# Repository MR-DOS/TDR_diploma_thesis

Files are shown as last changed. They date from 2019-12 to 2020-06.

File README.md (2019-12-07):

# Time domain reflectometer
----
## Description
Simple and cheap TDR based on experience from TDR\_avalanche and TDR\_splitter. Primary intention of this device is to give people the possibility to measure defects on cables / PCBs for less than about $100.
It is also my diploma thesis. All software (GUI in Octave), firmware (which runs in the processor in the reflectometer) and hardware (the PCB) was written/drawn by me. All parts are open source and you can use the in any way which is conformant with GNU GPL 3.0. The only parts not made by me are the SPD and CMSIS drivers which are included because the firmware might not work with different versions (note: I patched a bug in the SPD in ADC section where changing ADC sources was programmed plainly wrong). 

----
## Overview
This device uses a PLL, fast CML buffer and diode sampling bridge. The principle is simple: one oscillator is fed into the CML buffer and then the resulting rectangular waveform with sharp edges (measured around 75-85 ps) is fed into the cable. Both the input pulse and the reflections are sampled by the diode sampling bridge which is driven by another oscillator. The oscillators have a fixed frequency ratio, which allows equivalent-time sampling. The use of equivalent time sampling reduces cost of the device, because the slowed-down waveform can be sampled by a normal ADC, thus there is no need for a oscilloscope grade fast ADC, fast (and expensive) circuitry like FPGAs.
The generated pulse should have maximum jitter of about 23 ps peak-to-peak and 4 ps RMS (measured). The TDR is able to sample with timestep of 20 ps.
In contrary with the TDR\_avalanche, this device uses only deterministic parts. The avalanche pulser had quite a lot of jitter and was difficult to tune to behave properly, I decided to use these instead.

----
## How it works
### Pulse generator
This TDR uses Si5351-A-B with 8 outputs as a triple oscillator with balanced outputs. One of the oscillators drives a CML buffer (SY54020), which creates a rectangular pulse with sharp edges. The pulses are fed into the network which connect the pulse generator, cable and sampler.

### Connecting network
The network mentioned earlier serves as a matching network to reduce impedance mismatch at the measuring connector.

### Sampler
The sampler is a simple dual diode bridge sampler which is fed by the other two oscillators. These two oscillators are synchronous with constant offset to allow double sampling and have a slightly different frequency than the oscillator in the generator. With this setup, the output of the sampler is a slowed-down version of the input waveform, which is then sampled by the microcontroller.

### ADC
The sampled waveform is digitized by the ADC of the microcontroller.

----
## References
[1-GHz Sampling Oscilloscope Front End Is Easily Modified](http://www.redrok.com/sampscope.htm)

----
## Sidenotes

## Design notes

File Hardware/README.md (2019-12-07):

# TDR_5351_core
----
## Description
Simple and cheap TDR based on experience from TDR\_avalanche and TDR\_splitter. Primary intention of this device is to give people the possibility to measure defects on cables / PCBs for less than about $100. UNDER CONSTRUCTION UNTIL STATED OTHERWISE.

----
## Overview
This device uses a PLL, fast CML buffer and diode sampling bridge. The principle is simple: one oscillator is fed into the CML buffer and then the resulting rectangular waveform with sharp edges (currently less than 200 ps) is fed into the cable. Both the input pulse and the reflections are sampled by the diode sampling bridge which is driven by another oscillator. The oscillators have a fixed frequency ratio, which allows equivalent-time sampling. The use of equivalent time sampling reduces cost of the device, because the slowed-down waveform can be sampled by a normal ADC, thus there is no need for a oscilloscope grade fast ADC, fast (and expensive) circuitry like FPGAs.
The generated pulse should have maximum jitter of about 80 ps peak-to-peak. The jitter of the sampler is not known as of now. Without the use of any averaging or statistical analysis, this could allow to sample points separated by no more than 100 ps (about 1-1.5 cm in a typical cable) and even less if averaging is used.

In contrary with the TDR\_avalanche, this device uses only deterministic parts. The avalanche pulser had quite a lot of jitter and was difficult to tune to behave properly. Since there are now quite cheap buffers with low rise/fall times (less than 200 ps, but there are even faster, though more expensive), Idecided to use these instead.

----
## How it works
### Pulse generator
This TDR uses Si5351-A-B with 8 outputs as a triple oscillator with balanced outputs. One of the oscillators drives a CML buffer (SY54020), which creates a rectangular pulse with sharp edges. The pulses are fed into the network which connect the pulse generator, cable and sampler.

### Connecting network
The network mentioned earlier serves as a matching network to reduce impedance mismatch at the measuring connector.

### Sampler
The sampler is a simple dual diode bridge sampler which is fed by the other two oscillators. These two oscillators are synchronous with constant offset to allow double sampling and have a slightly different frequency than the oscillator in the generator. With this setup, the output of the sampler is a slowed-down version of the input waveform, which is then sampled by the microcontroller.

### ADC
The sampled waveform is digitized by the ADC of the microcontroller. Because the ADC has only 12 bits, there is also a logarithmic detector with 90 dB dynamic range, effectively increasing the resolution to ~15 bits. This resolution can not be achieved with realtime sampling without spending a fortune on the ADC itself. There is an additional DAC for calibrating offset before measurement.

### First level of postprocessing
The first level of postprocessing is differentiation and normalization. After these operations, the user gets the response of the DUT to the input impulse. However, since the input pulse does not have infinitesimally short risetime, it may need additional postprocessing to get transmission / reflection graph.

### Second level of postprocessing
This second level consists of Wiener deconvolution - we have a measured input pulse and a "wish" - we want to get a nice clean step rising edge. Using these two vectors, a reverse filter can be computed using Wiener deconvolution. This step could help to get data which could be processed by the third level of postprocessing.

### Third level of postprocessing
This level analyses the data from the second level to get transmission and reflection coefficients for each measured point. The measured data has to be processed point-by-point. At each point, the reflected energy is used to compute the coefficients and the remaining energy after it has passed through this point. Then, a 1D simulation is run to get a vector of the reflected pulses. 
This resulting vector is then subtracted from the measured vector of data to get rid of multiple reflections. There is still one unsolved problem: defects with antisymmetrical reflection coefficient. This happens when two cables of different impedance are connected together. A localised defect (such as additional resistor in the path) has symmetrical reflection coefficient. Second problem is figuring out what is a multiple reflection and what is a periodic structure (this question may even have NO answer). After processing all of the points, the T/R vectors should be computed (note that there are two vectors for each parameter due to the antisymmetric behavior).
Next step is to turn the T/R vectors into a vector of characteristic impedance.

----
## Images
Description:
Description
Description2:
Description2

----
## References
[1-GHz Sampling Oscilloscope Front End Is Easily Modified](http://www.redrok.com/sampscope.htm)

----
## Sidenotes

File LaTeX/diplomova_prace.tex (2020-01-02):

% arara: pdflatex: { synctex: yes }
% arara: makeindex: { style: ctuthesis }
% arara: bibtex

% The class takes all the key=value arguments that \ctusetup does,
% and a couple more: draft and oneside
\documentclass[twoside]{ctuthesis}
\newcommand{\unit}[1]{\ensuremath{\, \textup{#1}}}
\usepackage{amsmath}
\usepackage{mathtools}
\usepackage{graphicx}
\usepackage{epsfig}
\usepackage{physics}
\usepackage[automake,acronym,nonumberlist]{glossaries}
\usepackage[binary-units=true,detect-all]{siunitx}
\sisetup{%
     output-decimal-marker = {,},
     %inter-unit-product = \ensuremath{{}\cdot{}}
        }
\sisetup{range-phrase=--}
\usepackage[short,ddmmyyyy]{datetime}
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

V práci je popsána vytvořená konstrukce reflektometru a princip jeho funkce. Jednotlivé funkční bloky jsou podrobně popsány, vysvětlen je i postup optimalizace těchto bloků k dosažení co nejlepších parametrů zapojení. Vysvětleny jsou i metody detekce závad na vedení, kalibrace zařízení a autokalibrace.

Práce ze zabývá i případnými možnostmi, jak by bylo možné rozšířit schopnosti tohoto zařízení o funkci transmisometru, která by umožnila používat toto zařízení jako vektorový analyzátor v časové oblasti.

\end{abstract-czech}

% Abstract in English
\begin{abstract-english}
This work deals with construction of reflectometer in time domain, which is implemented as functional device along with control software. The goal was to develop a device capable of measuring reflections on transmission lines caused by faults with spatial resolution on the order of units of centimetres. The emphasis was to develop a cheap and simple device while trying not to limit the functionality or capability of the device.

The resulting device is able to measure up to units of~\si{\GHz}, sampling step is \SI{20}{\ps}, resulting in equivalent sampling rate of \SI{50}{\gigasample}. This sampling step theoretically allows spatial resolution of \SI{0.3}{\centi\meter} in vacuum, possibly even less in real environment. The device can detect simple faults on its own, along with their type and position. When used with computer, it is possible to perform calibration using calibration set.

The work contains explanation of the construction and its principles. Each functional block is described in detail as well as the optimalisations which were used to obtain the best possible parameters of the construction. Also explained are methods of detection of faults on the transmission line, calibration and autocalibration of the device.

This work also deals with eventual possibilities of extending the capabilities of the device by implementing a function of transmisometer, which could allow to use the device as a vector network analyzer in time domain.

\end{abstract-english}

% Acknowledgements / Podekovani
\begin{thanks}
Děkuji svým rodičům i celé rodině, že mi byli oporou po celou dobu mého studia.

Děkuji Ing. Viktoru Adlerovi, Ph.D., a prof. Ing. Karlu Hoffmannovi, CSc., za umožnění přístupu k mikrovlnné měřicí technice a možnost konzultování detailů této práce.

Děkuji Ing. Viktoru Adlerovi, Ph.D., za významnou pomoc při analýze vysokofrekvenčních parametrů substrátu použitého pro plošný spoj reflektometru.

Děkuji studentskému klubu Silicon Hill a projektu \quotedblbase MacGyver - Bastlíři SH\textquotedblleft\ za umožnění přístupu k měřicímu vybavení, pájecí a osazovací technice.

Děkuji Ing. Pavlu Poláškovi, Ing. Petru Bartoňovi, Ing. Stanislavu Tomáškovi, Ing. Martinu Řehákovi, Ing. Stanislavu Mašláňovi a Bc. Janu Sixtovi za pomoc při kontrole překlepů, jazykové úrovně a detailů estetické formy této práce.
\end{thanks}

% Declaration / Prohlaseni
\begin{declaration}
Prohlašuji, že jsem  předloženou práci vypracoval samostatně a že jsem uvedl veškeré použité informační zdroje v souladu s Metodickým pokynem č.~1/2009 o dodržování etických principů při přípravě vysokoškolských závěrečných prací.

Dále prohlašuji, že nemám závažný důvod proti užití tohoto školního díla ve smyslu §60 zákona č.~121/2000 Sb., o právu autorském, o právech souvisejících s právem autorským a o změně některých zákonů (autorský zákon).

V Praze, \ctufield{day}.~\monthinlanguage{title}~\ctufield{year}

% podpis pod prohlasenim
\begin{flushright}
	\parbox{5cm}
	{
		\begin{center}
			\dotfill \\ Bc. Petr Polášek 
		\end{center}
	}
\end{flushright}

\end{declaration}

% Only for testing purposes
%\listfiles
\usepackage[pagewise]{lineno}

\begin{document}

\maketitle

\printglossaries

\input{diplomova_prace_1_uvod.tex}
\input{diplomovy_projekt_1_uvod.tex}
\input{diplomovy_projekt_2_buzeni.tex}
\input{diplomovy_projekt_3_vzorkovani.tex}
\input{diplomovy_projekt_4_separace.tex}
\input{diplomovy_projekt_5_rozsireni_dynamickeho_rozsahu.tex}
\input{diplomovy_projekt_6_navrzena_architektura.tex}
%\input{diplomova_prace_2_princip_funkce.tex}
\input{diplomova_prace_3_popis_zapojeni.tex}
\input{diplomova_prace_popis_firmware.tex}
\input{diplomova_prace_popis_software}
\input{diplomova_prace_4_kalibrace.tex}
\input{diplomova_prace_5_detekce_zavad.tex}
\input{diplomova_prace_6_zmerene_parametry.tex}
%\input{diplomova_prace_7_uzivatelske_rozhrani_a_popis_ovladani.tex}
\input{diplomova_prace_8_zaver.tex}

\appendix

\printindex

\bibliographystyle{unsrt}
\bibliography{diplomova_prace}

%\ctutemplate{specification.as.chapter}

\end{document}

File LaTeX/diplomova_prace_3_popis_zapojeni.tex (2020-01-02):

\chapter{Princip zapojení}

\section{Základní princip zapojení}
Zapojení se skládá z generátoru impulsů, vzorkovacích obvodů a řídicího fázového závěsu, který tyto dvě části synchronizuje. Generátor impulzů se používá pro tvorbu budicího signálu, který je zaveden do měřeného systému. Pomocí vzorkovacího můstku se pak provádí měření odezvy měřeného systému. Fázový závěs časuje spouštění generátoru a vzorkovače asynchronně tak, aby se postupně spouštěcí událost obou části vzájemně posouvala. Tím dochází k tomu, že každý vzorek odpovídá jinému bodu měřené odezvy. Zařízení tedy pracuje v režimu měření v ekvivalentním čase. To znamená, že měřená odezva není změřena v reálném čase, ale je pomalu sbírána. V navrženém zapojení dojde při každé periodě budicího signálu ke změření jednoho vzorku odezvy systému.

\section{Blokové zapojení}
\begin{figure}[htbp]
\caption{Blokové zapojení reflektometru.} \label{block_diagram}
\end{figure}

Podrobnější blokové zapojení reflektometru je znázorněno na obrázku \ref{block_diagram}. V dalších částech této kapitoly jsou jednotlivé bloky popsány do hloubky. Oproti základnímu blokovému zapojení z obrázku \ref{reflectometer_blockdiagram} obsahuje toto blokové zapojení navíc 3 bloky, jejichž nezbytnost vyplynula ze simulací. Důvody pro nezbytnost těchto bloků jsou vysvětleny v rámci této kapitoly. 

\section{Generování potřebných hodinových signálů}
Hlavním prvkem celého zapojení je vícekanálový digitální fázový závěs, který je postaven na obvodu Si5351C-B \cite{Si5351datasheet}. Tento obvod obsahuje krystalový oscilátor, na nějž jsou zavěšeny dva interní oscilátory \acrshort{VCO}. Vnitřní blokové schéma je možné vidět na obrázku \ref{5351blockdiagram}.

Tyto oscilátory je možné nezávisle nastavit. Jejich frekvence $f_\mathrm{VCO}$ může být neceločíselným násobkem frekvence krystalového oscilátoru $f_\mathrm{XTAL}$.
\begin{equation}
f_\mathrm{VCO}=f_\mathrm{XTAL} \left(a+\dfrac{b}{c} \right)
\end{equation}
Koeficient $a$ může nabývat hodnot $\langle 15, 90 \rangle$. V neceločíselném režimu může koeficient $c$ nabývat hodnot $\langle 0, 1048575 \rangle$, koeficient $b$ pak $\langle 0, c \rangle$.
Je tedy možné nastavit frekvenci oscilátorů tak, že se liší o méně než 1 ppm. Při použití těchto dvou frekvencí jako časovacích signálů pro buzení a vzorkování je tedy možné odebírat až 1048576 vzorků. Dochází totiž k tomu, že s každou periodou se postupně hrany těchto obdélníkových signálů vůči sobě časově posunou o fixní časový krok. Tento krok je možné spočítat z nastavených frekvencí oscilátorů.

\begin{equation}
\begin{gathered}
f_\mathrm{VCO1}=f_\mathrm{XTAL} \left(a_1+\dfrac{b_1}{c_1} \right) \\
f_\mathrm{VCO2}=f_\mathrm{XTAL} \left(a_2+\dfrac{b_2}{c_2} \right)
\end{gathered}
\end{equation}

Za těmito oscilátory ještě následují děličky. Ty také umožňují neceločíselné dělení, které je ovšem nevýhodné, protože může zvyšovat fázové chvění výstupního signálu. Proto jsou použity pouze v celočíselném režimu. Děličky jsou použity kvůli omezenému vzorkovacímu kmitočtu použitého \acrshort{ADC}. Výsledkem jsou tedy dvě frekvence $f_\mathrm{OUT1}$ a $f_\mathrm{OUT2}$. Označíme-li společný dělicí poměr $d$ a za předpokladu, že $a_1=a_2=a$, $c_1=c_2=c$ a $b_2=0$:

\begin{equation}
\begin{gathered}
f_\mathrm{OUT1}=\dfrac{f_\mathrm{VCO1}}{d}=f_\mathrm{XTAL} \left(\dfrac{a+\dfrac{b_1}{c} }{d}\right) \\
f_\mathrm{OUT2}=\dfrac{f_\mathrm{VCO2}}{d}=f_\mathrm{XTAL} \left(\dfrac{a}{d}\right).
\end{gathered}
\end{equation}

Pak se během jedné periody oscilátory vůči sobě posunou o čas $T_\textrm{SHIFT}$:

\begin{equation}
\begin{gathered}
T_\mathrm{SHIFT}=T_\mathrm{OUT2}-T_\mathrm{OUT1}=\dfrac{1}{f_\mathrm{OUT2}} - \dfrac{1}{f_\mathrm{OUT1}} \\
T_\mathrm{SHIFT}=\dfrac{d}{f_\mathrm{XTAL}} \left(\dfrac{1}{a} - \dfrac{1}{a+\dfrac{b_1}{c}}\right) = \dfrac{d}{a f_\mathrm{XTAL}} \left(\dfrac{1}{1+a\dfrac{c}{b_1}}\right).
\end{gathered}
\label{equation_tshift}
\end{equation}

Pro minimalizaci fázového chvění je podle \cite{Si5351datasheet} a \cite{Si5351applicationnote} vhodné preferovat celočíselné násobení i dělení, je-li to možné. Dále může fázové chvění zmenšit i použití sudých násobitelů a dělitelů. V navrženém zapojení je tedy fázový závěs nastaven takto:

\begin{equation}
\begin{gathered}
f_\mathrm{XTAL}=\SI{25}{MHz} \\
a=24 \;\;\; b_1=24/8=3 \\
c=500000/8=62500 \;\;\; d=128 \cdot 46=5888 \\
f_\mathrm{OUT1} \doteq \SI{101902}{kHz} \doteq f_\mathrm{OUT2} \\
T_\mathrm{SHIFT} = \dfrac{46 \cdot 128}{24 \cdot 25000000} \left(\dfrac{1}{1+24 \cdot \dfrac{500000}{24}}\right) \doteq \SI{19.627}{ps}.
\end{gathered}
\end{equation}

Podobný princip měření pomocí dvou oscilátorů o podobné frekvenci se již v literatuře objevil, avšak zatím nebyl implementován přímo pomocí fázového závěsu. V \cite{vernierreflectometer} byly použity dva nezávislé oscilátory. Toto řešení je sice jednodušší, avšak není možné zajistit, jak velký bude časový krok měření. Vzhledem ke skutečnosti, že oscilátory jsou závislé na teplotě a dalších vnějších vlivech, není možné zajistit ani dlouhodobou stabilitu. Při použití dvojitého fázového závěsu s neceločíselným násobitelem však je možné tuto dlouhodobou stabilitu zajistit. Krok měření je pak závislý pouze na frekvenci jediného krystalového oscilátoru. Při použití \acrshort{TCXO} může být tato stabilita velmi dobrá, na úrovni jednotek \si{ppm}.

Další podobný způsob časování vzorkování je použit v \cite{ddsfpgareflectometer}, kde je využito \acrshort{FPGA} jako \acrshort{DDS}. Výstup z této \acrshort{DDS} je filtrován dolní propustí a následně zaveden do komparátoru, římž je získáván obdélníkový řídicí signál. Řízení vzájemné polohy budicího pulzu a vzorkování je pak dosaženo nastavováním fáze sinusového signálu, který je generován \acrshort{DDS}. Tento systém umožňuje krok vzorkování v jednotkách pikosekund. Je tedy podobný vlastnostmi konstrukci popsané v této práci. Něvýhodou je však to, že autoři se příliš nezabývali generátorem impulzů, náběžná hrana použitého generátoru činí přibližně \SI{2}{ns}. Důvod, proč tak autoři učinili, je možná omezení vyplývající ze zvoleného způsobu vzorkování pomocí komparátoru a digitálního integrátoru.

\begin{figure}[htbp]
\caption{Zapojení hodinového generátoru Si5351.}\label{timing_section_schematic}
\end{figure}	

Zapojení hodinového generátoru s fázovým závěsem Si5351 je zobrazeno na \ref{timing_section_schematic}. Symbol obvodu je rozdělený na dvě části, U207A a U207B. Kromě samotného obvodu Si5351 je potřeba pouze referenční krystal a napájecí obvody. Napájení je rozděleno na dvě domény. První je jádro fázového závěsu, které napájí interní logické obvody a \acrshort{VCO}. Druhá napájí výstupní budiče. Toto rozdělení by mělo omezit fázový šum generovaných hodinových signálů způsobený rušením na napájení \acrshort{VCO} \cite{Si5351applicationnote}. Pro krystalový oscilátor není potřeba používat zatěžovací kondenzátory, jsou obsaženy uvnitř obvodu Si5351, je možné je nastavit v rozsahu \SIrange{4}{10}{\pico\farad}.

Výstupní budiče obvodu Si5351 jsou slučitelné jak s \acrshort{CMOS} obvody a jejich modernějšími variantami, tak i s obvody rodin \acrshort{TTL}, \acrshort{ECL}, \acrshort{CML}, \acrshort{LVDS} a podobnými. Budiče jsou proudové, proud je možné nastavit ve čtyřech krocích v rozsahu \SIrange{2}{8}{\milli\ampere} \cite{Si5351datasheet}. Tohoto faktu je využito v zapojení, 4 výstupy jsou použity přímo pro proudové buzení vzorkovacích můstků, 2 výstupy pro buzení \acrshort{CML} bufferu, jeden výstup pro synchronizaci vzorkování použitého mikrokontroléru a jeden výstup pro řízení stavu \acrshort{CML} bufferu.

Dle katalogových údajů by tento fázový závěs měl typicky dosahovat mezivrcholového fázového šumu \SI{70}{\pico\second}, maximálně  \SI{155}{\pico\second}. Dle výrobce by mělo jít o parametry v \quotedblbase nejhorším možném případě v reálné aplikaci \ldots{} skutečné vlastnosti mohou být výrazně lepší\textquotedblleft{} \cite{Si5351datasheet}. Bohužel není uvedeno, jak se tento parametr mění v závislosti na nastavení násobicích a dělicích sekcí. Není uveden ani histogram šumu, jeho frekvenční spektrum, ani efektivní hodnota. Spektrum fázového šumu je možné najít v \cite{Si5351_phase_noise_measurement}, bohužel se nejedná o ověřený zdroj.

\section{Tvorba budicího pulzu}
Pro tvorbu budicích pulzů byl vybrán obvod SY54020, který je původně určen jako \acrshort{CML} buffer. Logické obvody \acrshort{CML} používají logické úrovně referencované vůči kladnému pólu napájení, výstupy i vstupy těchto obvodů jsou přizpůsobené impedanci \SI{50}{\ohm}. Podle katalogových údajů \cite{SY54020datasheet} by měla výstupní impedance ležet v rozsahu \SIrange{45}{55}{\ohm}. Hlavní důvod pro použití tohoto bufferu je vysoká rychlost, dle katalogových údajů by měla délka náběžných a sestupných hran spadat do rozsahu \SIrange{35}{100}{\pico\second}, typicky \SI{60}{ps}. Tento údaj je udáván pro body, kde prochází náběžná hrana \SI{20}{\%} a \SI{80}{\%} mezi původním a konečným napětím. U obvodu Si5351 by podle katalogových údajů měl tento parametr být typicky \SI{1}{\nano\second}, maximálně \SI{1.5}{\nano\second}. Použitím obvodu SY54020 by tedy mělo být možné zkrátit náběžné hrany o \SIrange{90}{98}{\%} oproti přímému použití výstupu z obvodu Si5351 jako zdroje budicích pulzů. Dle katalogových údajů by špičkové aditivní fázové chvění mělo být přibližně \SI{1}{\pico\second}, tedy přibližně o dva řády lepší, než fázové chvění obvodu Si5351. Použití budiče SY54020 by tedy mělo mít zcela minimální vliv na celkovou úroveň fázového chvění.

\begin{figure}[htbp]
\caption{Zapojení generátoru budicích pulzů}\label{pulse_generator_section_schematic}
\end{figure}	

Postatná výhoda obvodu SY54020 spočívá v oddělení napájecích úrovní vstupů a výstupů tohoto obvodu. V zapojení je vstupní část obvodu napájena \SI{3.3}{\volt}, výstupní část \SI{1.65}{\volt}, tedy přesně polovičním napájecím napětím. Tato napájecí hladina označená jako VCC, a zároveň jako GNDS, je použita jako virtuální analogová země. Všechny následující analogové obvody jsou vztažené k této virtuální zemi. Díky tomu je možné k buzení vzorkovacích můstků použít přímo fázový závěs Si5351, protože můstek je tak buzen symetricky. Zapojení generátoru budicích impulzů je na obrázku \ref{pulse_generator_section_schematic}.

\section{Přizpůsobovací obvody a testovací port}
Generátor budicích impulzů z předchozího bodu je nezbytné připojit k měřicímu portu. K tomuto portu však musí být zároveň připojeny vzorkovací obvody. Proto jsou nezbytné přizpůsobovací obvody, které umožňují připojit k testovacímu portu obě tyto části při dodržení vstupní impedance. Jejich zapojení je uvedeno na obrázku \ref{match_section_schematic}.

\begin{figure}[htbp]
\caption{Schéma přizpůsobovacích obvodů.}\label{match_section_schematic}
\end{figure}

Přizpůsobovací obvody jsou navrženy tak, aby bylo dosaženo co nejlepšího impedančního přizpůsobení na testovacím konektoru. Problematická je impedance vzorkovacího můstku, neboť na jeho výstupu je připojen vzorkovací kondenzátor, který způsobuje rezonanci pouzdra vzorkovacího můstku na frekvenci přibližně \SI{1.7}{\giga\hertz}. Vliv této rezonance na vstupní impedanci reflektometru je částečně potlačen použitím děliče sestaveného z odporů R220, R224 a R229 a cívky L201 (označení podle obrázku \ref{match_section_schematic}). Výsledná impedance je zakreslena v grafu \ref{input_impedance}, parametr $S_{11}$ pak v grafu \ref{input_reflection}. Simulace byla provedena bez vedení T1, které se nachází na schématu \ref{ltspice_schematic} a přibližně simuluje vedení mezi testovacím konektorem a vzorkovačem. Hodnoty použitých součástek v děliči se mezi schématy liší, protože během vývoje zařízení byly použité diodové můstky HSMS-282P vyřazeny z výroby. Jako náhrada byly vybrány diodové můstky SMS3923-081LF. Díky podrobnějšímu SPICE modelu bylo možné do simulace zahrnout i vliv parazitních vlastností pouzdra tohoto můstku, což umožnilo další optimalizace. Konečné hodnoty použitých součástek se nachází ve schématu použitém v simulaci.

\begin{figure}[htbp]
\caption{Schéma použité pro simulaci vstupní impedance v programu LTSpice.}\label{ltspice_schematic}
\end{figure}

\begin{figure}[htbp]
\caption{Vstupní impedance reflektometru.}\label{input_impedance}
\end{figure}

\begin{figure}[htbp]
\caption{Přizpůsobení vstupní impedance reflektometru.}\label{input_reflection}
\end{figure}

Vstupní impedance byla simulována do 10 GHz. V celém simulovaném pásmu se vstupní impedance odchyluje od nominálních $50~\Omega$ o méně než $\pm2~\Omega$. Parametr $\lvert S_\mathrm{11} \rvert$ je vykreslen v grafu \ref{input_reflection}. V celém rozsahu je menší než \SI{-33}{\deci\bel}, což odpovídá koeficientu odrazu $\Gamma <= 0.023$. Navržené přizpůsobení by tedy mělo být velmi dobré. Vzhledem k tomu, že konektory obvykle způsobují odraz větší, než je odraz vycházející ze simulace, měl by být klíčovým prvkem pro dosažení malého odrazu na testovacím portu kvalitní konektor a připojovací vedení. Při uvažování tolerance impedance budiče SY54020, která se pohybuje v rozsahu \SIrange{45}{55}{\ohm}, se přizpůsobení zhorší, nicméně v celém rozsahu je lepší než \SI{-30}{\deci\bel}.

\section{Vzorkovací obvody a oddělovací zesilovač}
Vzorkování je v reflektometru prováděno ve třech stupních. První stupeň je tvořený diodovým můstkem U208 (na obrázku \ref{sampler_section_schematic}) a kondenzátorem C230. Druhý stupeň vzorkování je tvořen diodovým můstkem U209 a kondenzátorem C233. Třetí stupeň probíhá uvnitř mikrokontroléru v \acrshort{ADC}.

První vzorkovací stupeň je připojen k obvodu Si5351, který proudově napájí vzorkovací můstek. Proud nastavený na budičích tohoto obvodu je \SI{8}{\milli\ampere}. V době, kdy vzorkovač sleduje vstupní signál, jsou diody sepnuty v propustné oblasti, můstek se pak chová přibližně jako rezistor o odporu jednotek \si{\ohm} zapojený mezi vstupem a vzorkovacím kondenzátorem. V okamžiku, kdy má být odebrán vzorek měřeného napětí, se obrátí směr proudu tekoucí skrz můstek, čímž se můstek rozepne. Po rozepnutí má můstek charakter kondenzátoru o kapacitě desetin pikofaradu. Aby můstek co nejméně ovlivňoval vstupní impedanci reflektometru, je připojen přes přizpůsobovací obvody. Kondenzátor C230 musí mít co nejmenší kapacitu, aby příliš kapacitně nezatěžoval vzorkovací můstek. Při použití většího kondenzátoru klesá šířka propustného pásma vzorkovače a zvětšuje se vliv vzorkovače na vstupní impedanci reflektometru. Pro potlačení kapacitního charakteru vzorkovače je v přizpůsobovacím obvodu použita kombinace R229 a L201 podle schématu \ref{sampler_section_schematic}, které částečně na vysokých frekvencích stáčí impedanci zpět k reálným hodnotám. Při použití příliš malého kondenzátoru je problematická parazitní kapacita diodového můstku v rozepnutém stavu, měřený signál pak výrazně \quotedblbase prosakuje\textquotedblleft{} do navzorkovaného signálu i v okamžiku, kdy je diodový můstek rozepnutý.

\begin{figure}[htbp]
\caption{Zapojení vzorkovacích obvodů.}\label{sampler_section_schematic}
\end{figure}

Vzhledem k velice malé kapacitě vzorkovacího kondenzátoru je nezbytné, aby obvody připojené k němu měly minimální vstupní proud. To by bylo možné zajistit přímo unipolárním operačním zesilovačem U205, avšak má velkou vstupní kapacitu, přibližně 27 pF \cite{oscilloscopefrontend}. Proto je použit oddělovací zesilovač s unipolárním dvouhradlovým tranzistorem BF998 s malou kapacitou hradla. Vstupní impedance oddělovacího zesilovače je přibližně do \SI{900}{\mega\hertz} takřka čistě imaginární, kapacita odpovídající této impedanci je přibližně \SI{0.6}{\pico\farad} na \SI{10}{\mega\hertz} a \SI{0.9}{\pico\farad} na \SI{1}{\giga\hertz}. Zesilovač je zapojen jako sledovač signálu s jednotkovým ziskem. V source tranzistoru je zapojen proudový zdroj kvůli minimalizaci zkreslení. Dle simulace by stejnosměrné zkreslení zesilovače mělo být lepší než \SI{0.0005}{\%}, absolutní chyba výstupního napětí je uvedena v grafu \ref{buffer_voltage_error}. Rozkmit měřeného napětí je podle simulací \SI{20}{\milli\volt}.

Při návrhu zapojení byly uvažovány i varianty s jinými tranzistory. Bohužel nebyl nalezen žádný tranzistor, který by byl  schopen pracovat do vyšších frekvencí a přitom měl nízký vstupní proud hradla. Moderní tranzistory HEMT bohužel zpravidla mají vstupní proud v řádu mikroampérů. Rychlejší tranzistory typů MOSFET nebo MESFET se vyrábí pouze pro výkonové aplikace. Ke vhodným tranzistorům typu JFET se bohužel dodávají pouze S-parametry a nejsou dostupné parametry pro SPICE modely. Nakonec tedy byl zvolen tranzistor BF998. 

Maximální hodnotu kapacity kondenzátoru C230 určuje i oddělovací zesilovač. Při kapacitě větší než \SI{1.5}{\pico\farad} se oddělovací zesilovač rozkmital, což bylo zjištěno v zapojení během testování. Následně byla tato skutečnost potvrzena simulací a opravena. Proto jsou v zesilovači použity odpory R249, R250 a R251. R251 omezuje kladnou zpětnou vazbu a tlumí rezonanci páru U208~--~C230, čímž je zabráněno rozkmitání zesilovače. Odpor R249 nadále zeslabuje tuto kladnou zpětnou vazbu. Odpor R250 zvětšuje vstupní impedanci zesilovače a zvětšuje šířku pásma tohoto oddělovacího stupně. Kondenzátor C231 není v konečném zapojení použit, neboť zmenšoval použitelnou šířku pásma zesilovače a zhoršoval stabilitu zapojení. Přenosová charakteristika oddělovacího zesilovače je uvedena v grafu \ref{frequency_transfer_function_bf}.Podle těchto odsimulovaných výsledků by měla být 6\si{\deci\bel} šířka pásma přibližně \SI{5.9}{\giga\hertz}.

\begin{figure}[htbp]
\caption{Přenos oddělovacího zesilovače.}\label{frequency_transfer_function_bf}
\end{figure}

Celková přenosová charakteristika od testovacího portu až k výstupu oddělovacího zesilovače je uvedena v grafu \ref{frequency_transfer_function_all}. 6\si{\deci\bel} šířka pásma pak činí přibližně \SI{1.93}{\giga\hertz}.

\begin{figure}[htbp]
\caption{Přenos celého systému přizpůsobení-vzorkovač-zesilovač.}\label{frequency_transfer_function_all}
\end{figure}

Simulace nebyla provedena s idealizovaným proudovým zdrojem, ale již v zapojení, které je uvedeno na schématu \ref{sampler_section_schematic}. Simulovaná data by tak měla lépe odpovídat realitě. Důvod, proč na schématu \ref{ltspice_schematic} není uvedeno celé zapojení proudového zdroje, ale jen idealizovaného zdroje, je časová náročnost výpočtů. Při simulacích vstupní impedance má tato část minimální vliv na výsledky, ale výrazně zpomaluje výpočty, proto byla ze simulací týkajících se vstupní impedance a tranzientních simulací oddělovacího zesilovače vynechána. Celé zapojení proudového zdroje je vidět na schématu \ref{current_source_section_schematic}.

\begin{figure}[htbp]
\caption{Absolutní chyba linearity oddělovacího zesilovače.}\label{buffer_voltage_error}
\end{figure}

\begin{figure}[htbp]
\caption{Zapojení proudového zdroje.}\label{current_source_section_schematic}
\end{figure}

Proudový zdroj na schématu \ref{current_source_section_schematic} napájí oddělovací zesilovač. Zdroj je řízen \acrshort{DAC}, je možné jej nastavit v rozsahu \SIrange{0}{15.9}{\si{mA}} v 4096 krocích po přibližně \SI{3.88}{\micro\ampere}. Zdroj je určen k autokalibraci reflektometru, umožňuje stejnosměrné posunutí měřeného signálu. Tento autokalibrační proces je nezbytný kvůli výrobním tolerancím a teplotní závislosti unipolárního dvouhradlového tranzistoru BF998. Proudový zdroj je zapojen jako kaskodové proudové zrcadlo. Odpor R235 spolu s tranzistory Q203 a Q204 slouží jako převodník z napětí na proud. Tranzistory Q202, Q205, Q206 a Q207 tvoří proudové zrcadlo. V emitorech tranzistorů jsou zapojeny odpory, čímž se zrcadlo podobá Widlarově proudovému zrcadlu se zesilovacím poměrem přibližně 60. Tranzistor Q202 je vysokofrekvenční typ s $f_T=\SI{6}{\giga\hertz}$ při \SI{8}{\milli\ampere} a nízkou výstupní kapacitou kolektoru, maxímálně $C_\mathrm{ob}<\SI{1.8}{\pico\farad}$. Pro ochranu tranzistoru Q202 před lavinovým průrazem během zapínání reflektometru a autokalibrace je použita dioda D201, která omezuje napětí kolektor-emitor na tranzistoru Q202 na přibližně \SI{4}{\volt}, průrazné napětí tranzistoru je dle katalogových údajů \SI{6}{\volt}. Proudový zdroj je navržen tak, že není možné nastavit proud emitorem tranzistoru Q202 větší než \SI{15}{\milli\ampere}, přičemž povolený trvalý proud je \SI{50}{\milli\ampere}. Tranzistor by tedy měl být kompletně ochráněn před poškozením. Pro potlačení vlivu kapacity diody D201 na přenos oddělovacího zesilovače na vysokých frekvencích je použita cívka L203.

\begin{figure}[htbp]
\caption{Zapojení napájecích zdrojů vzorkovacích obvodů.}\label{analog_source_section_schematic}
\end{figure}

Napájecí zdroj operačních zesilovačů, proudového zdroje a oddělovacího zesilovače je na schématu \ref{analog_source_section_schematic}. Zdroj je napájen z \SI{5}{\volt} získávaných z USB. Jádrem je spínaný zdroj MT3608 pracující na frekvenci \SI{2}{\mega\hertz}, který je nastaven na napětí \SI{12.6}{\volt}. Tato napájecí větev je filtrována aktivním filtrem s tranzistorem Q208. Napájecí hladina \SI{12.6}{\volt} je filtrována RC článkem R244-C264. Toto vyfiltrované napětí je zapojeno do gate tranzistoru Q208, který je zapojen jako sledovač. Teoreticky je tak možné zajistit značné potlačení zvlnění napětí na napájecí větvi. Výsledkem je vyfiltrované nestabilizované napětí přibližně \SI{10}{\volt}. Potlačení zvlnění by dle simulace mělo být přibližně \SI{-128}{\deci\bel} na frekvenci \SI{2}{\mega\hertz}, kde pracuje spínaný zdroj. Přenosová charakteristika tohoto aktivního filtru je na grafu \ref{analog_source_filter_transfer}, je vyznačená modře. V realizovaném zapojení bude toto potlačení pravděpodobně výrazně menší, což může způsobit např. nízká renonanční frekvence nebo sériový odpor kondenzátorů použitých na výstupu filtrů.

Záporná napájecí větev je získávána z téhož zdroje pomocí nábojové pumpy tvořené kondenzátory C266 -- C268 a diodami D205 a D206. Výsledné napětí je přibližně \SI{-12}{\volt}. Tranzistor Q209 opět tvoří aktivní filtr. Odporovým děličem je nastaveno výstupní napětí přibližně \SI{-5}{\volt}. Potlačení zvlnění by dle simulace mělo být přibližně \SI{-134}{\deci\bel} na frekvenci \SI{2}{\mega\hertz}, kde pracuje spínaný zdroj. Přenosová charakteristika tohoto aktivního filtru je na grafu \ref{analog_source_filter_transfer}, je vyznačená oranžově.

Za předpokladu, že simulace odpovídají reálnému chování navržených obvodů, mělo by být zvlnění na napájecích větvích způsobené spínaným zdrojem potlačeno aktivními filtry natolik, že by nemělo být měřitelné a nemělo by nijak ovlivňovat měření.

\begin{figure}[htbp]
\caption{Přenosová charakteristika aktivních napájecích filtrů.}\label{analog_source_filter_transfer}
\end{figure}

Za oddělovacím zesilovačem následuje jednotkový sledovač s operačním zesilovačem TL072, který slouží ke snížení výstupní impedance oddělovacího zesilovače. Výstup tohoto zesilovače je opět vzorkován pomocí vzorkovacího můstku U209 do \SI{1}{\nano\farad} kondenzátoru. Oddělovací zesilovač má sice vysokou impedanci, takže téměř nezpůsobuje drift napětí na vzorkovacím kondenzátoru C230, nicméně vzhledem ke svodovému proudu vzorkovacího můstku U208 je tento drift nenulový. Proto těsně před sepnutím můstku U208 se rozepne můstek U209. Vzhledem k tomu, že kapacita kondenzátoru C233 je o 3 řády větší, než kapacita kondenzátoru C230, je i výsledný drift o 3 řády menší. Napětí po tomto sekundárním vzorkování je zesíleno v zesilovači U205 na schématu \ref{secondary_sampler_section_schematic}.

\section{Logaritmický detektor}

Toto navzorkované napětí je převáděno na logaritmickou podobu pomocí logaritmického detektoru AD8307. Logaritmický detektor byl použit pro rozšíření dynamického rozsahu měření dvanáctibitového \acrshort{ADC}. Bohužel, v rámci testování se ukázalo, že šum vzorkovacích obvodů je příliš velký a logaritmický detektor nepřinášel žádné zpřesnění měřených hodnot. Změřená závislost výstupního napětí logaritmického detektoru na kódovém slově \acrshort{DAC} je v grafu \ref{log_function_graph_whole}, přiblížená problematická oblast v grafu \ref{log_function_graph_zoomed}.

\begin{figure}[htbp]
\caption{Schéma sekundárního vzorkovače a logaritmického detektoru.}\label{secondary_sampler_section_schematic}
\end{figure}

\begin{figure}[htbp]
\caption{Změřená závislost výstupního napětí na kódovém slově DAC, celkové zobrazení.}\label{log_function_graph_whole}
\end{figure}

\begin{figure}[htbp]
\caption{Změřená závislost výstupního napětí na kódovém slově DAC, výřez problematické oblasti.}\label{log_function_graph_zoomed}
\end{figure}

\section{Digitalizace měřeného průběhu}
Navzorkovaný průběh je třeba pro zpracování zdigitalizovat. K tomuto účelu je použit interní \acrshort{ADC} použitého mikrokontroléru STM32F103. Tento převodník má rozlišení 12~bitů a maximální vzorkovací kmitočet \SI{1}{\megasample}. Podstatná výhoda interního převodníku je automatizace obsluhy měření. Digitalizace je synchronizována se vzorkováním, obvod Si5351 generuje synchronizační signál, kterým se digitalizace spouští. Ihned po dokončení digitalizace se vyvolává přerušení, které změřený vzorek zpracuje. Tento proces by bylo možné ještě zjednodušit použitím DMA v procesoru, avšak bylo zvoleno řešení s přerušením, protože přerušení řeší i průměrování a další úkony. Zapojení mikrokontroléru je vyobrazeno na schématu \ref{microcontroller_section}.

\begin{figure}[htbp]
\caption{Zapojení mikrokontroléru.}\label{microcontroller_section}
\end{figure}

\section{Komunikace s počítačem}
Komunikace reflektometru s počítačem je zajištěna pomocí virtuálního sériového portu. Ten je tvořen převodníkem CH340G, který podporuje standardní přenosové rychlosti, navíc nabízí i nestandardní rychlosti až do \SI{2}{\mega\baud}. Pro komunikaci s reflektometrem slouží software napsaný v prostředí Octave.

\section{Navržená deska plošných spojů}
Plošný spoj reflektometru byl nakreslen v návrhovém prostředí KiCAD. Vysokofrekvenční část spojů zahrnuje pouze cestu mezi konektorem, budičem a vzorkovačem. Tato cesta je dlouhá pouze několik milimetrů. Proto byl spoj navržen s předpokladem, že na takto krátkou vzdálenost není nezbytné použít materiál určený pro vysokofrekvenční zapojení. Byl proto použit obyčejný substrát typu FR-4 o tloušťce \SI{0.6}{\milli\meter}, motiv je pouze oboustranný. Tloušťka byla zvolena tak, aby koplanární vedení nemusela být širší než přibližně \SI{1}{\milli\meter} při mezeře mezi vedením a zemnicí plochou větší než \SI{0.2}{\milli\meter}. Požadavek na mezeru vychází z běžných výrobních požadavků a tolerancí výrobců plošných spojů. Navržená a vyrobená deska plošných spojů je vyfocena na obr. \ref{pcb_top_unassembled} a \ref{pcb_bottom_unassembled}. Osazená a otestovaná deska plošných spojů je na obrázcích \ref{pcb_top_assembled} a \ref{pcb_bottom_assembled}. Velké hnědé součástky, které jsou osazeny z obou stran desky plošných spojů, jsou kondenzátorová pole, která slouží ke spojení virtuální a skutečné signálové země pro vysoké frekvence, ohraničují celou oblast virtuální země. Okolí testovacího portu s koplanárním vedením je na obr. \ref{pcb_coplanar}.

\begin{figure}[htbp]
\caption{Vrchní strana desky plošných spojů, neosazená.}\label{pcb_top_unassembled}
\end{figure}

\begin{figure}[htbp]
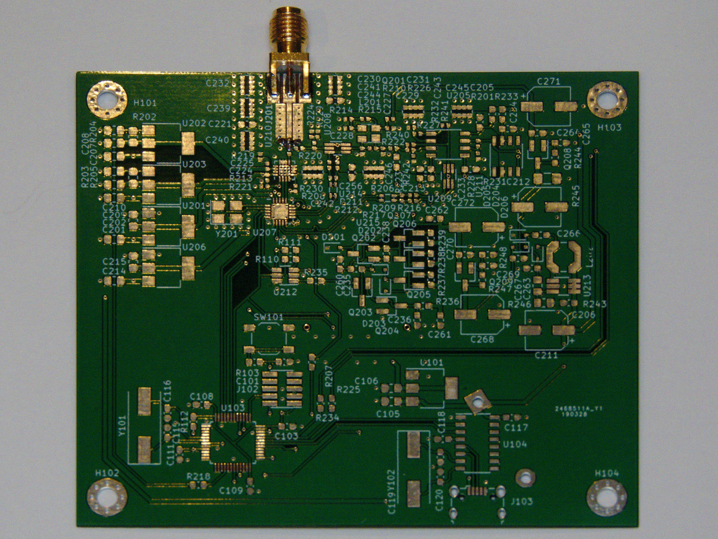
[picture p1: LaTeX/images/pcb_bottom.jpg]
\caption{Spodní strana desky plošných spojů, neosazená.}\label{pcb_bottom_unassembled}
\end{figure}

\begin{figure}[htbp]
\caption{Vrchní strana desky plošných spojů, osazená.}\label{pcb_top_assembled}
\end{figure}

\begin{figure}[htbp]
\caption{Spodní strana desky plošných spojů, osazená.}\label{pcb_bottom_assembled}
\end{figure}

\begin{figure}[htbp]
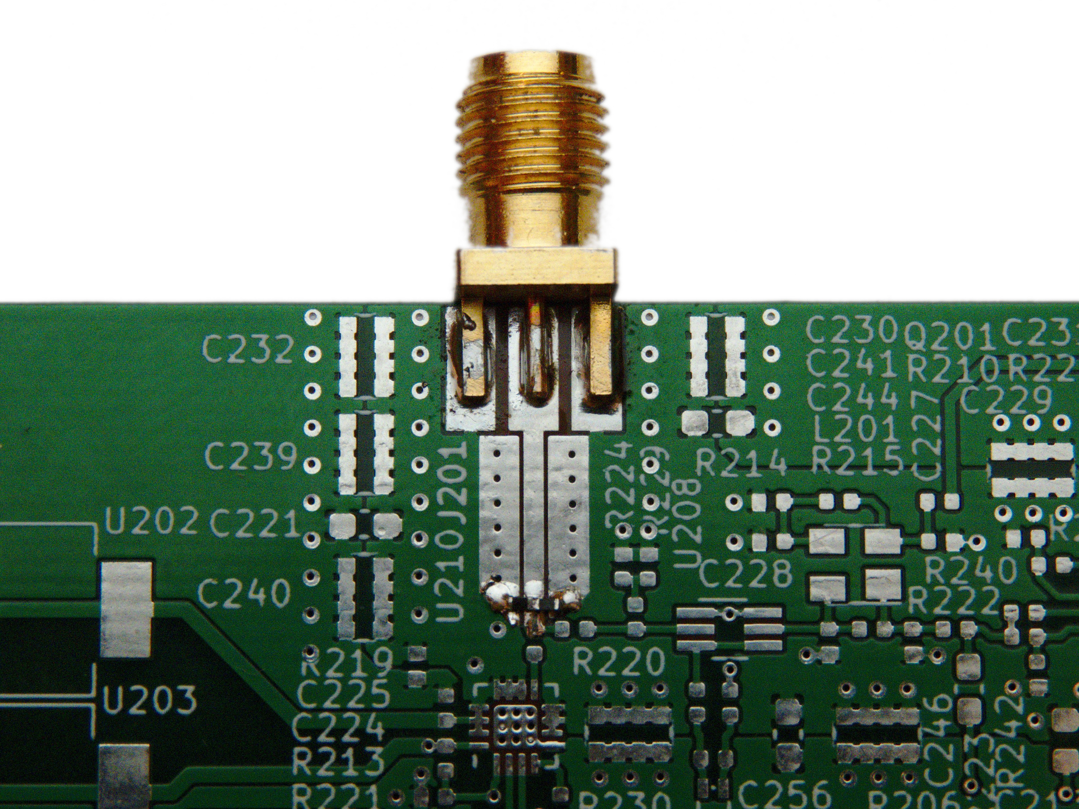
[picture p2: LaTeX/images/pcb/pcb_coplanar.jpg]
\caption{Testovací konektor, koplanární vedení a motiv budiče a vzorkovače.}\label{pcb_coplanar}
\end{figure}

Na obr. \ref{pcb_coplanar} je vidět koplanární vedení vedoucí ke konektoru. Délka tohoto vedení je necelých \SI{8}{\milli\meter}, šířka vodiče je \SI{0.775}{\milli\meter} a šířka mezery \SI{0.2}{\milli\meter}. Při tloušťce substrátu \SI{0.6}{\milli\meter} a permitivitě $\epsilon _r= \SI{4.6}{}$ vychází impedance tohoto koplanárního vedení na \SI{50.01}{\ohm}.

Pod konektorem se nachází také koplanární vedení. Jeho délka je \SI{5.3}{\milli\meter}, šířka vodiče je \SI{2}{\milli\meter} a šířka mezery \SI{0.2}{\milli\meter}. Tato část vedení byla bohužel nesprávně navržena, šířka pájecí plošky pro konektor měla být správně přibližně \SI{1.1}{\milli\meter} a mezera \SI{0.9}{\milli\meter}. Takto má tato část vedení impedanci přibližně \SIrange{30}{40}{\ohm} namísto \SI{50}{\ohm}. Spočtená impedance je uvedená jako rozsah, protože geometrické rozměry se nacházejí v rozsahu, kde se různé analytické nástroje ve výsledku lišily, protože obvykle pracují pouze pro určitý rozsah poměru šířky vedení k tloušťce substrátu. Mezi použitými nástroji byly programy TX-LINE, Saturn PCB Toolkit a KiCAD. Během měření se také ukázalo, že vybraný SMA konektor nebyl pro toto použití vhodný, neboť má velké výrobní tolerance a malou opakovatelnost montáže.

Na obrázku \ref{pcb_pll_buffer} se nachází napravo uprostřed fázový závěs Si5351 s referenčním krystalem. Nad ním se nachází budič SY54020. Nalevo se nacházejí celkem čtyři napájecí zdroje. Spodní dva zdroje slouží pro napájení fázového závěsu. Jeden napájí výstupní budiče, druhý vnitřní logiku a oba vnitřní oscilátory. Horní dva zdroje slouží pro napájení budiče SY54020, jeden napájí vstupní obvody, druhý výstupní budiče. Obě komponenty vyžadují nízkou impedanci napájecích větví, proto je blízko těchto komponent na každé napájecí větvi velké množství vyrovnávacích kondenzátorů. Většinu těchto kondenzátorů není možné vyfotit, protože se nacházejí pod displejem, který je na druhé straně plošného spoje. Jejich poloha je vidět v obr. \ref{pcb_decoupling}, jde o snímek z návrhového prostředí KiCAD. Zmíněné kondenzátory byly zvýrazněny. Červená vrstva je strana, kde se nachází fázový závěs a budič. Zelená vrstva je strana s diplejem. Většina kondenzátorů se nachází z opačné strany desky plošných spojů než fázový závěs a budič, aby byly se zemí spojeny co nejkratší cestou. Pro napájení byly použity lineární stabilizátory pro zajištění co nejmenšího šumu na napájecích větvích.
\begin{figure}[htbp]
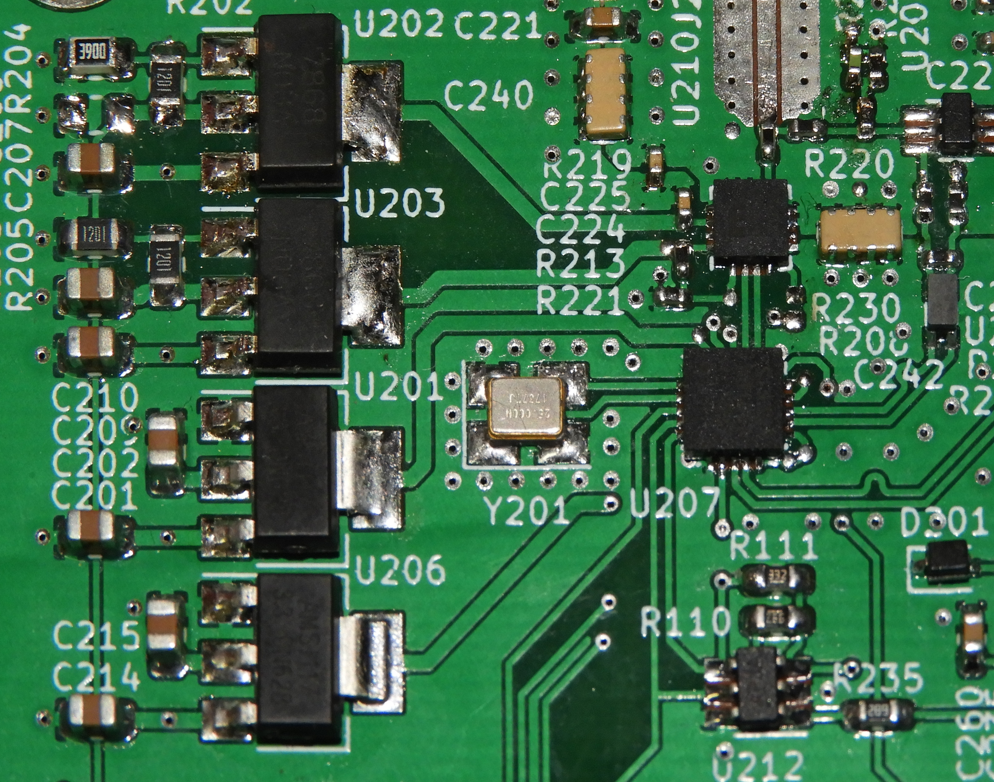
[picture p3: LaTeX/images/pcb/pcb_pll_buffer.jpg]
\caption{Fázový závěs, generátor budicích impulzů a napájecí zdroje.}\label{pcb_pll_buffer}
\end{figure}

\begin{figure}[htbp]
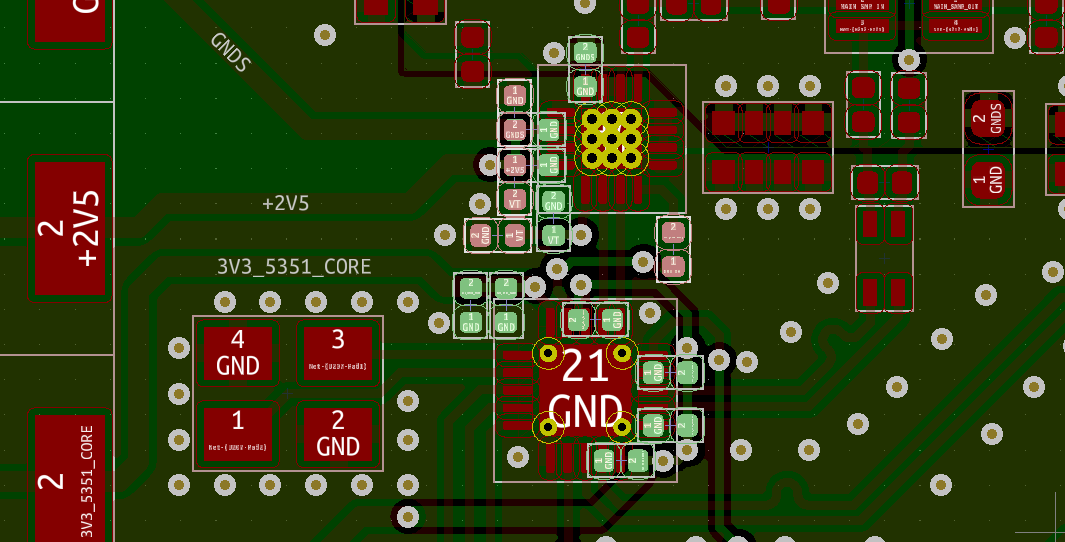
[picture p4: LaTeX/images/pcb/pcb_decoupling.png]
\caption{Okolí fázového závěsu a budiče v návrhovém prostředí KiCAD. Červenou barvou je vyznačena vrstva, kde se nachází většina součástek, zeleně vrstva, na které se nachází displej.}\label{pcb_decoupling}
\end{figure}

Na obrázku \ref{pcb_splitter} je okolí testovacího konektoru. Na spodním okraji se nachází budič SY54020, přímo nad ním se nachází rezistivní splitter určený k přizpůsobení budiče a vzorkovače k \SI{50}{\ohm} vedení. Splitter je připojen ke konektoru pomocí koplanárního vedení. Pro zajištění správné impedance a minimálních ztrát je z koplanárního vedení odstraněna nepájivá maska. U zvoleného výrobce bohužel nebyla k dispozici možnost nechat vyrobit desku plošných spojů bez povrchové úpravy. Možnosti povrchové úpravy byly olovnatý \acrshort{HAL}, bezolovnatý HAL a zlacení ENIG. Podle \cite{pcb_surface} a \cite{pcb_surface_simple} je z těchto možností lepší volba HAL, protože vedení s touto povrchovou úpravou má vlivem menší drsnosti povrchu nižší ztráty.
\begin{figure}[htbp]
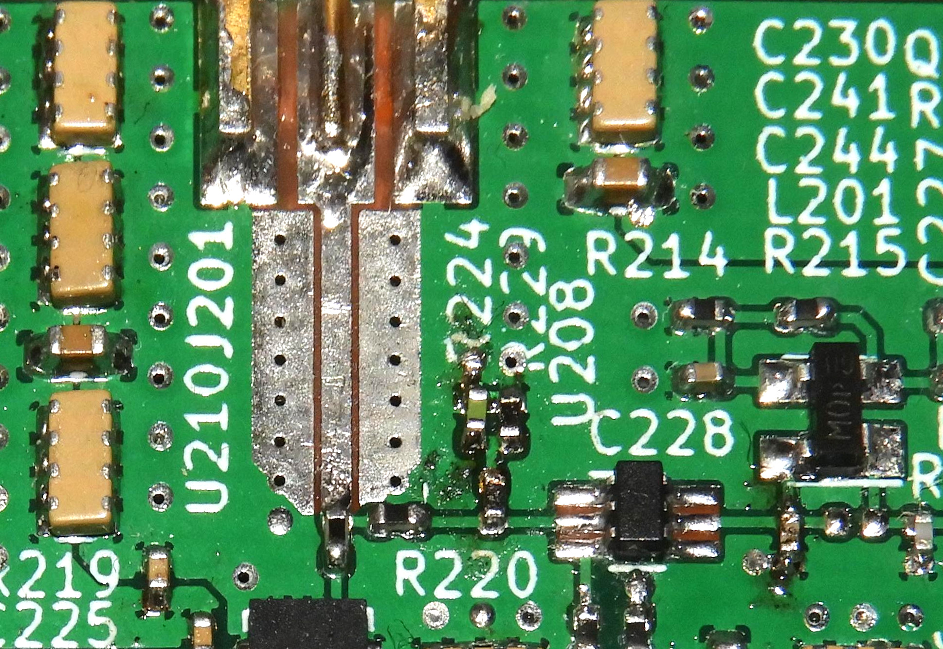
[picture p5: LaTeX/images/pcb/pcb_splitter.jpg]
\caption{Budič, rezistivní dělič, koplanární vedení a testovací konektor.}\label{pcb_splitter}
\end{figure}

Na obr. \ref{pcb_main_sampler} je vidět hlavní vzorkovač. V plastovém pouzdře se 6 vývody se nachází diodový můstek SMS3923-081. Pod ním se nachází \SI{150}{\ohm} rezistory a balun, přes které je přivedeno buzení z fázového závěsu Si5351. Tyto komponenty byly použity pro zvýšení souhlasné impedance buzení a tedy zvýšení vstupní impedance vzorkovače. Balun byl později odstraněn, neboť způsoboval rezonanční zákmity na hranách měřeného průběhu. Napravo od vzorkovače je oddělovací zesilovač, lépe je vidět na obr. \ref{pcb_buffer}. Nad tranzistorem BF998 se nachází odpory pro nastavení pracovního bodu. Vpravo se nachází operační zesilovač TL072, ve spodní části odpor, který vede do proudového zdroje, který se využívá pro autokalibraci.
\begin{figure}[htbp]
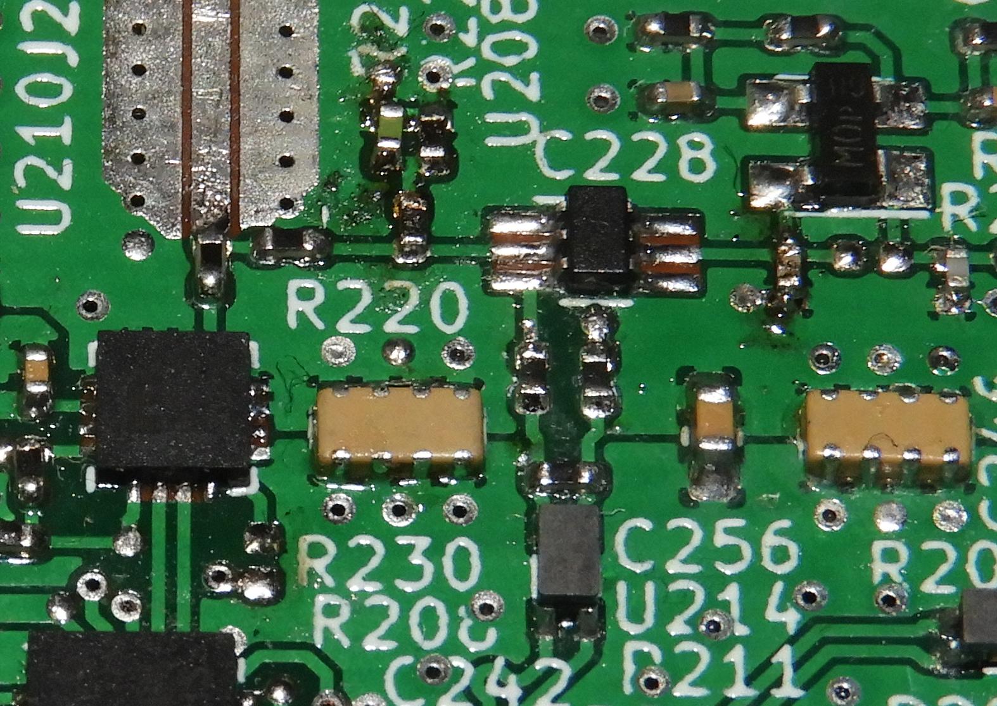
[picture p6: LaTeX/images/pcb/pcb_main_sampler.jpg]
\caption{Hlavní vzorkovač.}\label{pcb_main_sampler}
\end{figure}

\begin{figure}[htbp]
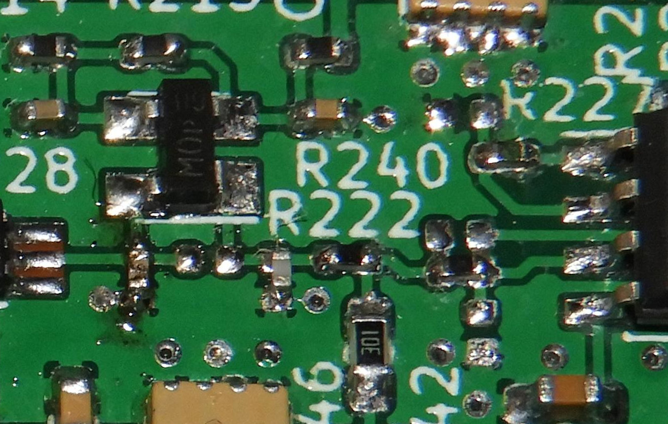
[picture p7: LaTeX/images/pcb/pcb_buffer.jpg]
\caption{Oddělovací zesilovač.}\label{pcb_buffer}
\end{figure}

Na obr. \ref{pcb_current_source} je proudový zdroj, který je součástí oddělovacího zesilovače. Pouzdro s 6 vývody v levé části je DAC, kterým se celý zdroj řídí. Ve spodní části se nachází převodník z napětí na proud, vpravo proudové zrcadlo. Tranzistor Q202 je VF tranzistor 2SC5773, jeho kolektor je připojen k oddělovacímu zesilovači.
\begin{figure}[htbp]
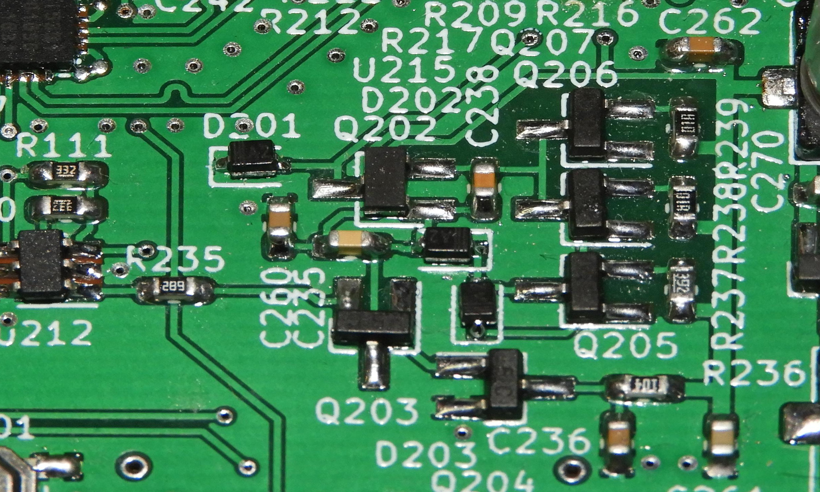
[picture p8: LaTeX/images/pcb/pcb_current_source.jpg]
\caption{Proudový zdroj.}\label{pcb_current_source}
\end{figure}

Na obr. \ref{pcb_log} je sekundární vzorkovač a logaritmický detektor. Vzorkovací můstek je opět připojen k fázovému závěsu přes odpory a balun, který byl také později odstraněn. V levé spodní části fotografie je vidět meandr sloužící k vyvážení délek diferenciálního páru. Diferenciální pár, který budí vzorkovací můstek primárního i sekundárního vzorkovače, má takto vyvažované délky vodičů, aby se všechny diody ve vzorkovacích můstcích spínaly ve stejný okamžik. Výstup sekundárního vzorkovače je připojen do operačního zesilovače TL072. Zde se zesílí, aby byl co nejlépe využit rozsah použitého ADC. Zároveň je tento signál přiveden do logaritmického detektoru kvůli možnosti rozšíření dynamického rozsahu měření. Bohužel se později ukázalo, že úroveň šumu v navzorkovaném signálu je příliš vysoká, a tedy detektor nepřináší rozšíření dynamického rozsahu. Dynamický rozsah měření se tedy ve výsledku vylepšuje pomocí průměrování popsaného v rovnici \ref{equation_averaging} podle \cite{HP54100_article_journal}.
\begin{figure}[htbp]
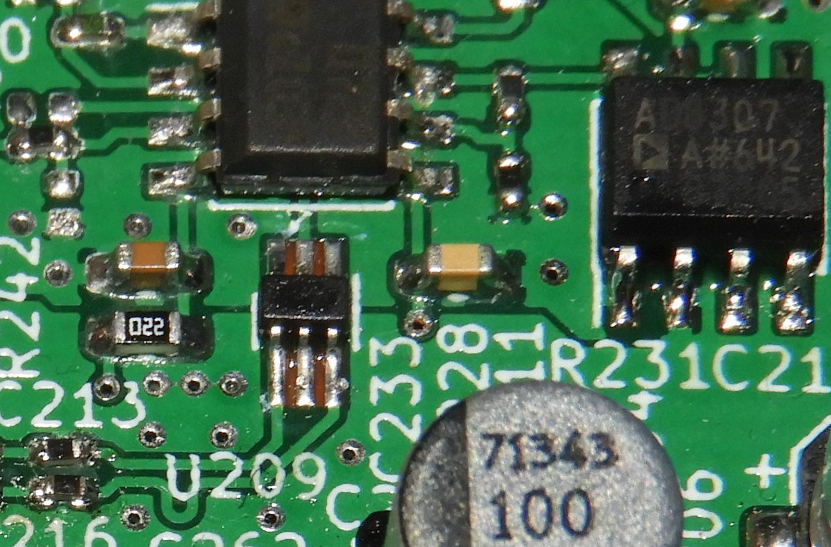
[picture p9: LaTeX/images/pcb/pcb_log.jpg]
\caption{Sekundární vzorkovač a logaritmický detektor.}\label{pcb_log}
\end{figure}

Na fotografii \ref{pcb_analog_supply} je symetrický spínaný zdroj pro analogové části reflektometru. Napájí oddělovací zesilovač, proudový zdroj oddělovacího zesilovače a operační zesilovač. V šestinohém pouzdře je samotný měnič MT3608, v těsné blízkosti jsou umístěny blokovací keramické kondenzátory a zpětná vazba kladné napájecí větve. Nalevo od cívky měniče se nachází nábojová pumpa, která vytváří zápornou napájecí větev. Mezi elektrolytickými kondenzátory v levé části se nachází aktivní filtr záporné napájecí větve, jehož zapojení se nachází ve schématu \ref{analog_source_section_schematic}.
\begin{figure}[htbp]
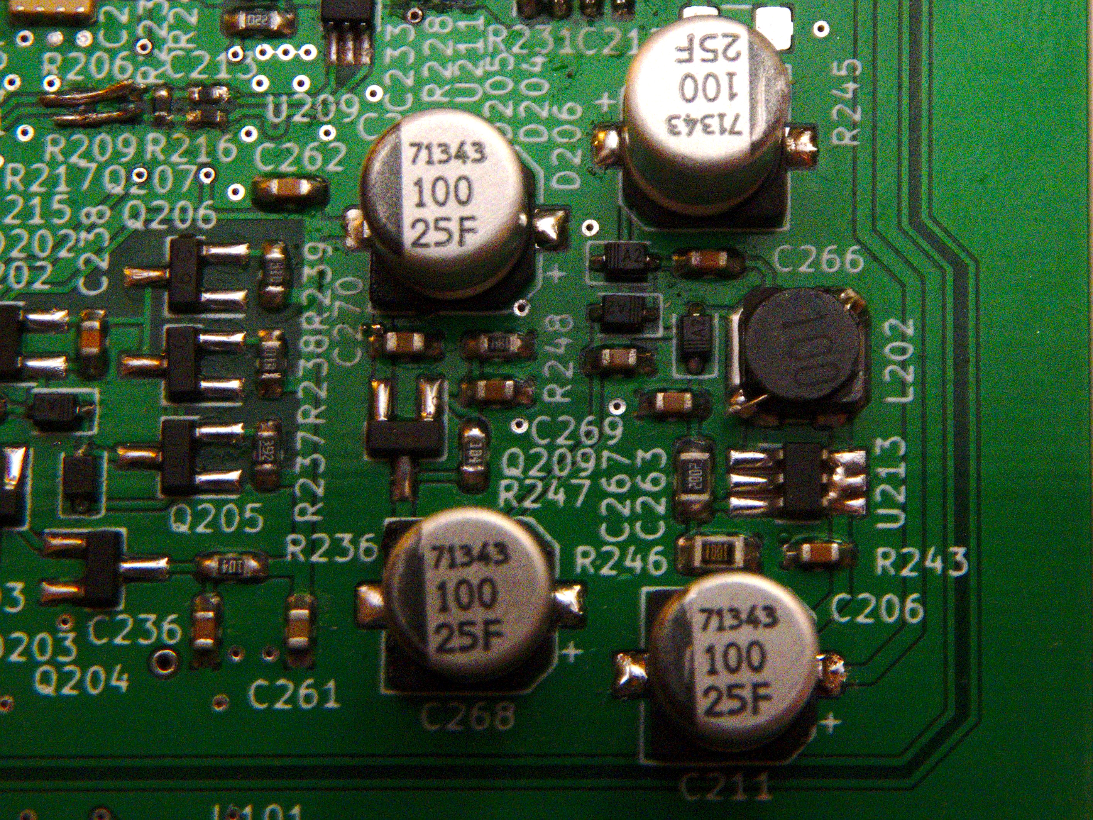
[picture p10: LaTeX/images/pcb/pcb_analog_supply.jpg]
\caption{Kombinovaný symetrický zdroj pro analogové části reflektometru.}\label{pcb_analog_supply}
\end{figure}

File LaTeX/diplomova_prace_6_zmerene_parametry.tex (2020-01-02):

\chapter{Změřené parametry}

\section{Průběh budicího pulzu}
Průběh budicího pulzu byl nejprve změřen osciloskopem Teledyne LeCroy WaveRunner 6 Zi. Tento osciloskop vyniká vzorkovací frekvencí \SI{40}{\gigasample} v reálném čase a analogovou šířkou pásma \SI{4}{\giga\hertz}. Měřicí soustava s tímto osciloskopem je na fotografii \ref{lecroy_photo}. Bohužel v měření na grafu \ref{lecroy} se ukázalo, že šířka pásma \SI{4}{\giga\hertz} je pro toto měření nedostatečná.

\begin{figure}[htbp]
\caption{Fotografie měřicí sestavy s osciloskopem LeCroy Waverunner 6 Zi.}\label{lecroy_photo}
\end{figure}

\begin{figure}[htbp]
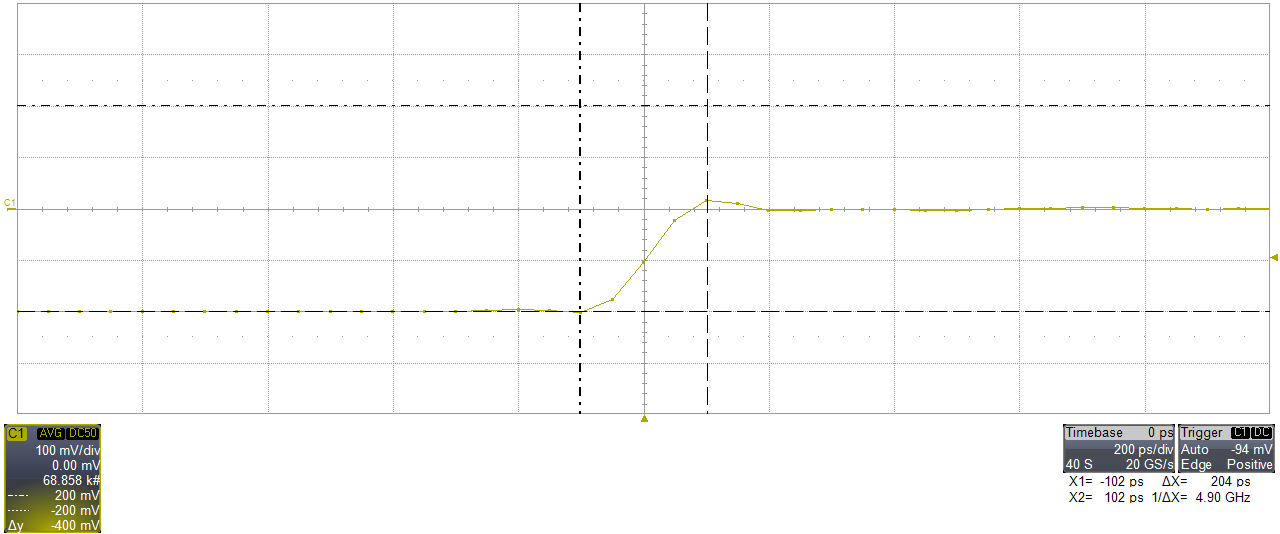
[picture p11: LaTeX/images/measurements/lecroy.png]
\caption{Náběžná hrana budicího signálu změřená osciloskopem LeCroy Waverunner 6 Zi.}\label{lecroy}
\end{figure}

Následně byl budicí pulz změřen vzorkovací hlavou Agilent 86015C v mainframe Agilent 86100C s měřením v ekvivalentním čase a analogovou šířkou pásma \SI{20}{\giga\hertz}. Pro měření bylo nezbytné připojit jak měřený signál, tak spuštěcí signál. Měřicí soustava je uvedena na fotografii \ref{agilent_photo}. Změřený průběh je uveden v grafu \ref{agilent_fall}. Změřená délka sestupné hrany se pohybuje v rozsahu \SIrange{80}{95}{\pico\second}. Bohužel výrobce u vzorkovací hlavy neuvádí, jaká je nejkratší měřitelná délka náběžné hrany. Proto není možné usuzovat, zda se jedná již o skutečnou délku náběžné hrany, nebo zda je měření zatíženo schopnostmi použité vzorkovací hlavy. Z měření je však možné usuzovat, že délka náběžné hrany je kratší nebo rovna \SI{90}{\pico\second}.
\begin{figure}[htbp]
\caption{Fotografie měřicí sestavy s mainframem 86100C.}\label{agilent_photo}
\end{figure}

\begin{figure}[htbp]
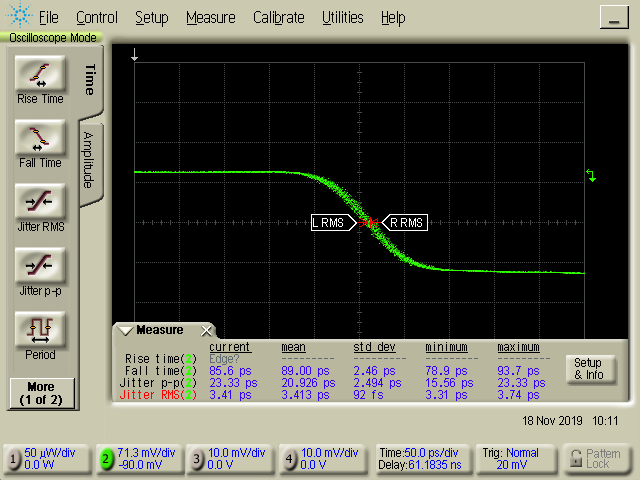
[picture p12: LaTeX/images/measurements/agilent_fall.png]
\caption{Měření sestupné hrany na mainframe Agilent 86100C.}\label{agilent_fall}
\end{figure}

\section{Parametry fázového závěsu}
Snahou v této části měření bylo změřit fázový šum fázového závěsu. Tato snaha bohužel byla z větší části neúspěšná. Nejprve byl vyzkoušen osciloskop Teledyne LeCroy WaveRunner 6 Zi, který umí měřit fázový šum a ze změřených dat vytvořit graf histogramu fázového šumu, graf frekenčního spektra šumu a numerické statistiky. Bohužel se ukázalo, že tento osciloskop, který katedra elektromagnetickéh pole vlastní, není vybaven softwarovou licencí na tato měření. Vyzkoušen byl tedy mainframe Agilent DCA-J 86100C, který podle označení DCA-J obsahuje hardwarové vybavení potřebné pro měření jitteru. Bohužel i u tohoto osciloskopu se také ukázalo, že není vybaven softwarovou licencí pro tato měření. Bez této licence je schopen pouze zobrazit dvě statistické hodnoty, mezivrcholovou úroveň fázového šumu a efektivní úroveň fázového šumu. Nakonec byl pouze změřen fázový šum mezi dvěma výstupy připojenými ke stejnému fázovému závěsu. Výsledkem měření je tedy fázový šum odpovídající šumu mezi dvěma výstupy diferenciálního páru. Toto měření je vidět na grafu \ref{agilent_fall}. Mezikanálový šum tedy dosahuje mezivrcholové úrovně \SI{21}{\pico\second} a efektivní úrovně \SI{3.4}{\pico\second}.

\section{TDR měření vstupní impedance reflektometru}
Vstupní impedance reflektometru byla změřena pomocí TDR hlavy Agilent 54754A v mainframe Agilent 86100C. Před použitím byla provedena kompletní kalibrace TDR hlavy pomocí kalibrů open, short a match. Podle očekávání na přechodu mezi konektorem a plošným spojem dochází k poklesu impedance přibližně na \SI{35}{\ohm}. K dalšímu poklesu impedance dochází nejspíše na přechodu mezi koplanárním vedení pod konektorem a úzkým koplanárním vedením. Dále již impedance reflektometru odpovídá \SI{50}{\ohm}.
\begin{figure}[htbp]
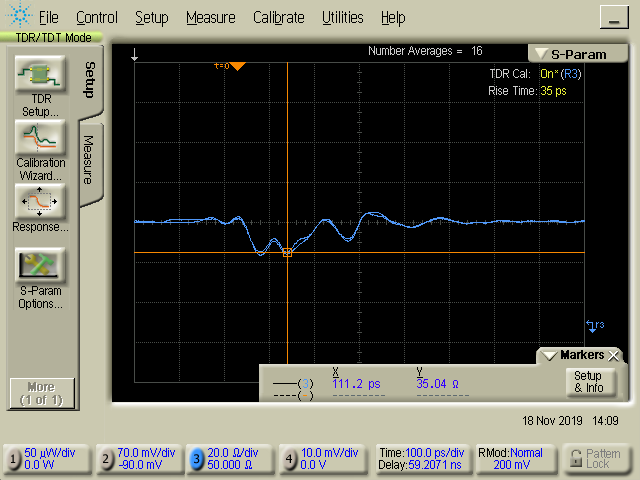
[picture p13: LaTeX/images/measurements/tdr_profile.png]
\caption{TDR měření vstupní impedance reflektometru.}\label{tdr_profile}
\end{figure}

\section{Měření vstupní impedance reflektometru pomocí VNA}
Měření impedance bylo zopakováno pomocí \acrshort{VNA} Agilent E8364A. Výsledek měření je prezentován v grafu \ref{vna_impedance}. Parametr $S_{11}$ je menší než \SI{-20}{\deci\bel} pro frekvence do \SI{3.5}{\giga\hertz} a menší než \SI{-10}{\deci\bel} pro frekvence do \SI{7.7}{\giga\hertz}. Měření bylo provedeno při různých výkonech generátoru ve VNA za účelem zjištění, zda se vstupní port chová lineárně. Test probíhal pro výkony do \SI{0}{\deci\bel m}, neprojevovaly se žádné viditelné nelineární jevy.

Toto měření bylo opakováno s neosazenou deskou plošných spojů z obr. \ref{pcb_coplanar}, změřený průběh parametru $S_{11}$ je v grafu \ref{vna_impedance_blank}. Změřený průběh je velmi podobný osazené desce plošných spojů, charakteristické prvky se vyskytují na podobných frekvencích a s podobnou velikostí. Zavěrem tohoto měření je tedy fakt, že špatné přizpůsobení vstupu není způsobeno navrženým splitterem, budičem, ani vzorkovačem, nýbrž nesprávným návrhem vedení pod konektorem a nekvalitním konektorem.

\begin{figure}[htbp]
\caption{Měření vstupní impedance reflektometru pomocí VNA. Modře je označeno měření v logické úrovni 1 a žlutě měření v logické úrovni 0.}\label{vna_impedance}
\end{figure}

\begin{figure}[htbp]
\caption{Měření vstupní impedance reflektometru pomocí VNA. Modře je označeno měření v logické úrovni 0, červeně měření na neosazené desce z obr. \ref{pcb_coplanar} terminované \SI{50}{\ohm} terminátorem.}\label{vna_impedance_blank}
\end{figure}

\section{Měření parametrů použitého substrátu}
Pro ověření permitivity použitého substrátu byla vytvořena testovací deska s kalibry pro kalibrační metody \acrshort{TRL} a \acrshort{UOSM}. Tato deska je na fotografii \ref{uoml}. Nachází se na ní seshora postupně kalibrační vedení nulové délky \quotedblbase thru\textquotedblleft , kalibry \quotedblbase short\textquotedblleft , \quotedblbase open\textquotedblleft{} a \quotedblbase match\textquotedblleft{}. Pod nimi se nachází tři vedení různých délek. Seshora jsou to vedení délek \SI{8}{\milli\meter}, \SI{50}{\milli\meter} a \SI{69.8}{\milli\meter}. Tloušťka substrátu a povrchová úprava je stejná jako u reflektometru, tedy \SI{0.6}{\milli\meter} a olovnatý HAL. Deska byla navržena tak, aby bylo možné na ni namontovat jak kvalitní konektory Southwest Endlaunch, tak i připájet levné konektory použité na reflektometru. Detail kalibru \quotedblbase match\textquotedblleft{} v podobě rezistoru velikosti 0201 je na fotografii \ref{match_detail}, pro srovnání velikosti má otvor napravo od rezistoru průměr \SI{0.3}{\milli\meter}.
\begin{figure}[htbp]
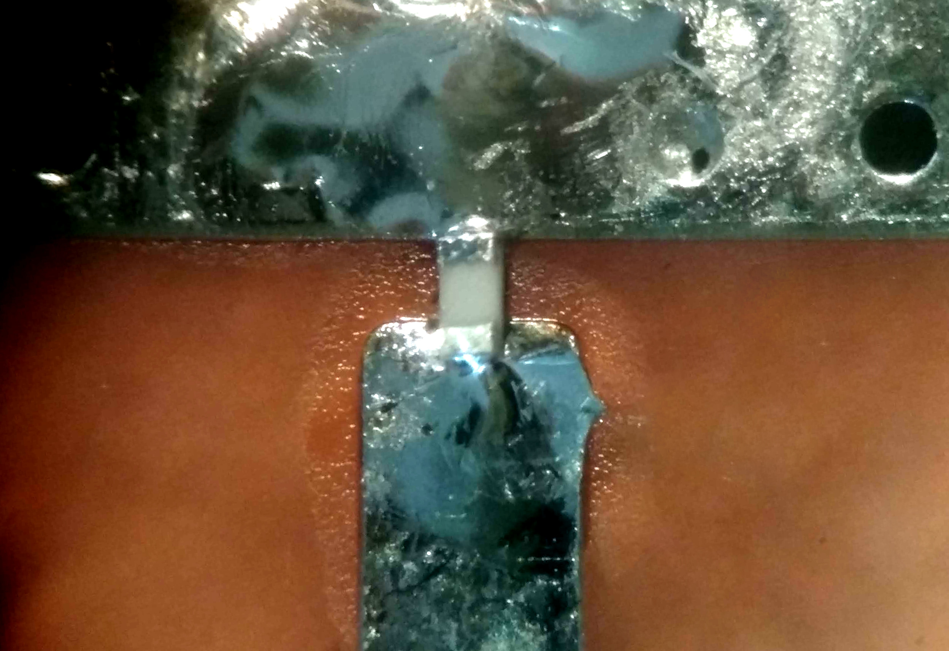
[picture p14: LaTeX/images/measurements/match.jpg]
\caption{Detail kalibru \quotedblbase match\textquotedblleft .}\label{match_detail}
\end{figure}

\begin{figure}[htbp]
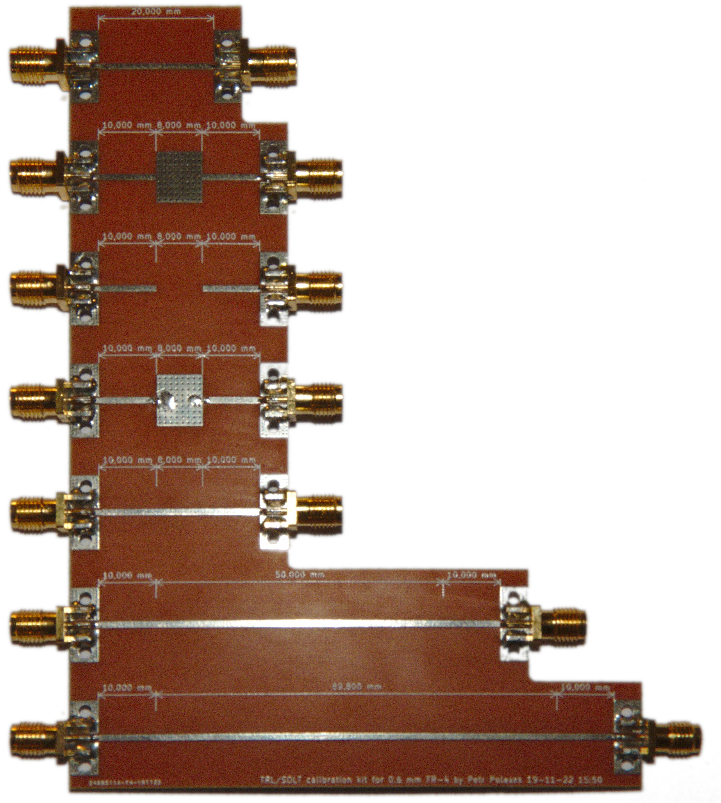
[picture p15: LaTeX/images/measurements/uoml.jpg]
\caption{Testovací deska plošných spojů pro změření parametrů substrátu s připájenými konektory.}\label{uoml}
\end{figure}

Pro zjištění parametrů substrátu bylo provedeno měření všech vedení a kalibrů pomocí \acrshort{VNA} Agilent E8364A. Změřená data byla zpracována pomocí algoritmu, který vytvořil podle \cite{TRL_calibration} Ing.~Viktor Adler,~Ph.D. v matematickém prostředí MATLAB. Takto zpracovaná data ze změřených kalibrů, vedení a jejich vzájemných kombinací byla použita pro kalibraci. Pomocí takto získané kalibrace byly získány parametry jednoho z vedení. Tato data byla následně importována do simulačního nástroje CST a pomocí optimalizace parametrů substrátu byly získány jeho vlastnosti. Bohužel takto získané parametry jsou zatíženy zdrojem chyb, který pramení ze skutečnosti, že byly získávány pouze parametry substrátu, nebyl uvažován vliv samotného vedení. Ztráty způsobené např. hrubostí povrchu vedení na desce plošných spojů jsou tak součástí získaných parametrů substrátu. Parametr $\tan \delta$ uvedený v tabulce \ref{permittivity_table} tedy nejspíše neodpovídá přesně ztrátám způsobeným substrátem. V tabulce \ref{permittivity_table} je vidět, že permitivita substrátu je až do \SI{6}{\giga\hertz} přibližně konstantní, poté začne klesat. Pokles je ovšem vcelku malý, na \SI{18}{\giga\hertz} činí pokles permitivity méně než \SI{1.5}{\percent}.

Při permitivitě substrátu $\epsilon'=\SI{4.1}{}$ místo $\epsilon'=\SI{4.6}{}$, se kterou byl reflektometr navržen, tak vychází impedance použitého koplanárního vedení na přibližně \SI{52.5}{\ohm}. Vzhledem ke skutečnosti, že pod testovacím konektorem se nachází vedení s nesprávnou (nižší) impedancí, má tento fakt vliv spíše pozitivní, protože je tak výsledný odraz na měřicím portu menší, než bylo původně očekáváno.

\begin{table}[htbp]
\begin{center}
\caption{Tabulka permitivity a ztrát substrátu získaná z testovací desky plošných spojů z obr. \ref{uoml}}\label{permittivity_table}
\begin{tabular}{ |c|c|c|  }
 \hline
 Frekvence (\si{\giga\hertz}) & $\epsilon'$ (-) & $\tan \delta$ (-)\\
 \hline
 \hline
	\SI{0.99}{}	&	\SI{4.100}{}	&	\SI{0.013}{}\\
 \hline
	\SI{2.18}{}	&	\SI{4.104}{}	&	\SI{0.006}{}\\
 \hline
	\SI{4.15}{}	&	\SI{4.081}{}	&	\SI{0.005}{}\\
 \hline
	\SI{6.13}{}	&	\SI{4.096}{}	&	\SI{0.007}{}\\
 \hline
	\SI{8.10}{}	&	\SI{4.065}{}	&	\SI{0.010}{}\\
 \hline
	\SI{10.1}{}	&	\SI{4.083}{}	&	\SI{0.012}{}\\
 \hline
	\SI{12.1}{}	&	\SI{4.050}{}	&	\SI{0.014}{}\\
 \hline
	\SI{14.0}{}	&	\SI{4.061}{}	&	\SI{0.015}{}\\
 \hline
	\SI{16.0}{}	&	\SI{4.037}{}	&	\SI{0.017}{}\\
 \hline
	\SI{18.0}{}	&	\SI{4.046}{}	&	\SI{0.017}{}\\
 \hline
\end{tabular}
\end{center}
\end{table}

\section{Parametry změřených dat}
Prvním zajímavým parametrem, který je možné z dat změřených reflektometrem získat, je délka měřené náběžné hrany. V grafu \ref{measured_open_risetime} je tato náběžná hrana vykreslena. Při měření délky náběžné hrany mezi \SIrange{20}{80}{\percent} mezi počátečním a konečným napětím je tato délka \SI{220}{\pico\second}. Celý změřený průběh pro kalibr \quotedblbase open\textquotedblleft{} na konci vedení je zakreslen v grafu \ref{measured_open}. Z grafu je vidět, že koeficient odrazu na tomto kalibru je $\Gamma \doteq 1$. Ve vzdálenosti odpovídající délce kabelu mezi reflektometrem a kalibrem, tedy přibližně okolo \SI{23}{\nano\second} se nachází další odraz, tentokrát menší a záporný. Ten je způsoben odrazem změřené odezvy na kalibr od konektoru reflektometru a zpět. Záporný je z toho důvodu, že impedance měřicího portu reflektometru je menší než \SI{50}{\ohm}.
\begin{figure}[htbp]
\caption{Délka náběžné hrany při měření kalibru \quotedblbase open\textquotedblleft{} na konci vedení.}\label{measured_open_risetime}
\end{figure}

\begin{figure}[htbp]
\caption{Odezva při měření kalibru \quotedblbase open\textquotedblleft{} na konci vedení.}\label{measured_open}
\end{figure}

Při měření kalibru v grafu \ref{measured_short_risetime} \quotedblbase short\textquotedblleft{} je náběžná hrana odezvy dlouhá \SI{240}{\pico\second}. Celá odezva se po diskontinuitě pohybuje okolo koeficientu odrazu $\Gamma \doteq -1$. Opět je na grafu \ref{measured_short} tento nežádoucí odraz vidět přibližně na \SI{23}{\nano\second}. Tentokrát má ovšem stejnou polaritu jako odraz od kalibru, protože koeficient odrazu měřicího portu i kalibru je záporný, po dvou odrazech má tedy stejnou polaritu jako první odraz.

\begin{figure}[htbp]
\caption{Délka náběžné hrany při měření kalibru \quotedblbase short\textquotedblleft{} na konci vedení.}\label{measured_short_risetime}
\end{figure}

\begin{figure}[htbp]
\caption{Odezva při měření kalibru \quotedblbase short\textquotedblleft{} na konci vedení.}\label{measured_short}
\end{figure}

Odezva na kalibr \quotedblbase match\textquotedblleft{} je v grafu \ref{measured_load}. Dle očekávání není v změřených datech viditelný žádný odraz od tohoto kalibru, přítomen je pouze šum.

\begin{figure}[htbp]
\caption{Odezva při měření kalibru \quotedblbase match\textquotedblleft{} na konci vedení.}\label{measured_load}
\end{figure}

\section{Měření funkčnosti potlačení šumu a zvlnění průměrováním a jednoduchou kalibrací}
Pro ověření funkčnosti potlačení šumu pomocí průměrování byl změřen kalibr \quotedblbase open\textquotedblleft{} při různých počtech průměrování ($1\times$, $2\times$, $4\times$, $8\times$, $16\times$, $32\times$, $64\times$). Tato změřená data jsou zanesena v grafu \ref{noise_raw_comparison}. Graf je pouze informativní, data pro různé úrovně průměrování jsou posunuta tak, aby se nepřekrývala. Měření probíhalo při vzorkovacím kroku $10\times$~větším, než ve zbytku práce, tedy přibližně \SI{196.2}{\pico\second}. Byl změřen i standard \quotedblbase load\textquotedblleft{} při průměrování $64\times$, pomocí získaných dat byla zkalibrována data jednotlivých měření kalibru \quotedblbase open\textquotedblleft . Z měření je vidět, že úroveň šumu klesá s rostoucím počtem průměrování, přičemž nedochází k žádným viditelným negativním jevům průměrování, jako je například prodloužení náběžné hrany vlivem vysokého fázového šumu. V grafu \ref{noise_cal_comparison} jsou zakreslena tatáž změřená data po kalibraci pomocí standardu \quotedblbase load\textquotedblleft . Z tohoto grafu je vidět, že téměř veškeré zvlnění měřeného signálu pomocí této kalibrace bylo výrazně potlačeno.

\begin{figure}[htbp]
\caption{Porovnání úrovně šumu pro různé počty průměrování, bez jednoduché kalibrace pomocí standardu \quotedblbase load\textquotedblleft .}\label{noise_raw_comparison}
\end{figure}

\begin{figure}[htbp]
\caption{Porovnání úrovně šumu pro různé počty průměrování, s použitím jednoduché kalibrace pomocí standardu \quotedblbase load\textquotedblleft .}\label{noise_cal_comparison}
\end{figure}

\begin{figure}[htbp]
\caption{Spektrum měřeného kalibru \quotedblbase open\textquotedblleft{} při průměrování $1\times$, bez jednoduché kalibrace pomocí standardu \quotedblbase load\textquotedblleft .}\label{noise_raw_avg1}
\end{figure}

\begin{figure}[htbp]
\caption{Spektrum měřeného kalibru \quotedblbase open\textquotedblleft{} při průměrování $64\times$, bez jednoduché kalibrace pomocí standardu \quotedblbase load\textquotedblleft .}\label{noise_raw_avg64}
\end{figure}

\begin{figure}[htbp]
\caption{Spektrum měřeného kalibru \quotedblbase open\textquotedblleft{} při průměrování $1\times$, s použitím jednoduché kalibrace pomocí standardu \quotedblbase load\textquotedblleft .}\label{noise_cal_avg1}
\end{figure}

\begin{figure}[htbp]
\caption{Spektrum měřeného kalibru \quotedblbase open\textquotedblleft{} při průměrování $64\times$, s použitím jednoduché kalibrace pomocí standardu \quotedblbase load\textquotedblleft .}\label{noise_cal_avg64}
\end{figure}

Amplitudové spektrum měřeného kalibru při počtech průměrování $1\times$ a $64\times$, s jednoduchou kalibrací i bez ní, je uvedeno v grafech \ref{noise_raw_avg1}, \ref{noise_raw_avg64}, \ref{noise_cal_avg1} a \ref{noise_cal_avg64}. V grafu \ref{noise_raw_avg64} je oproti grafu \ref{noise_raw_avg1} vidět výrazně nižší úroveň šumu - spektrum je hladší a i na frekvencích přes \SI{2}{\giga\hertz} jsou vidět periodické propady ve spektru, zatímco bez průměrování jsou tyto propady viditelné jen přibližně do \SI{0.5}{\giga\hertz}. Pomocí průměrování tedy bylo dosaženo snížení šumové úrovně a rozšíření použitelného frekvenčního rozsahu reflektometru. Graf \ref{noise_cal_avg1} a \ref{noise_raw_avg1} vypadají podobně, pro malé počty průměrování tedy kalibrace nepřínáší výrazné vylepšení měřených dat. V grafu \ref{noise_cal_avg64} je však vidět, že při velkém počtu průměrování zlepšuje kalibrace dynamický rozsah. Při použití kalibrace je amplituda mezi vrcholy a propady ve spektru přibližně \SIrange{80}{90}{\deci\bel}, bez použití kalibrace je tato amplituda pouze přibližně \SIrange{40}{80}{\deci\bel}.

Experimentálně tedy bylo zjištěno, že průměrováním a kalibrací pomocí kalibru \quotedblbase load\textquotedblleft{} je možné výrazně potlačit šum a zvlnění a zlepšit dynamický rozsah měření.

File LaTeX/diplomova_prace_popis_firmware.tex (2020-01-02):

\chapter{Popis firmware}

Pojmem firmware je v této kapitole myšlen program, který běží v mikrokontroléru, obsluhuje všechny části reflektometru, poskytuje uživatelské rozhraní a zajišťuje měření, vyhodnocování měření a komunikaci s počítačem. Firmware je napsán v jazyce C, knihovny pro ovládání periferií byly převzaty od výrobce. Všechen ostatní zdrojový kód je vlastní, vznikl v rámci této práce.

\section{Technické parametry firmware}
Použitý mikrokontrolér disponuje \SI{20}{\kilo\byte} \acrshort{RAM}. Jeden měřený vzorek zabírá 12 bitů, bez použití komprese dat je možné do \acrshort{RAM} uložit 10000~vzorků. Parametr $\frac{a b}{c}$ v rovnici \ref{equation_tshift} určuje délku měřeného souboru dat. Vzhledem k použitým hodnotám má měřený soubor dat 500000~bodů s časovým krokem přibližně \SI{19.62}{\pico\second}. Část RAM ovšem zabírá program pro svůj chod, délka měřicího okna byla nakonec zvolena 4096 bodů, což umožňuje v rámci jednoho okna změřit interval o délce přes \SI{80}{\nano\second}. Ve vakuu tento interval odpovídá délce měřeného úseku \SI{12}{\meter}. Pro koaxiální kabely odpovídá měřený úsek přibližně \SIrange{7.9}{10.2}{\meter} při uvažování typického rozsahu zkracovacího činitele \SIrange{0.66}{0.85}{}. V případě potřeby měřit delší vedení se může měřicí okno posunout a měřit další úsek vedení. Tento nedostatek tedy nebrání měřit libovolně dlouhá vedení, pouze znamená, že pro delší vedení je nezbytné provádět měření po částech.

\section{Autokalibrace a autodiagnostika zařízení}

\subsection{Detekce stability fázového závěsu}
Po zapnutí mikrokontrolér zapne všechny svoje interní periferie, načež začne komunikovat s fázovým závěsem Si5351. Nejprve je kontrolován indikátor úspěšného startu fázového závěsu, firmware čeká, dokud není fázový závěs připraven. Firmware pak nakonfiguruje všechny registry fázového závěsu, ovšem prozatím je nastaven tak, aby negeneroval žádné řídicí signály. Následně kontroluje firmware diagnostické registry fázového závěsu pro zjištění, zda je stabilní krystalový oscilátor. Fázový závěs je schopen indikovat stav, kdy vysazuje krystalový oscilátor \cite{Si5351datasheet}, například kvůli nedostatečnému zisku oscilátoru. Dále jsou kontrolovány indikátory nestability fázového závěsu, která může být způsobena například špatně navrženým napájením obvodu, které má na pracovních frekvencích \acrshort{VCO} pak příliš vysokou impedanci (interní \acrshort{VCO} pracují ve frekvenčním rozsahu \SIrange{600}{900}{\mega\hertz}). Pokud během fáze testování nenastane žádná z popsaných chyb, pokračuje program dále, jinak se zastaví a informuje uživatele o chybě.

\subsection{Autokalibrace stejnosměrné složky}
Dalším krokem autokalibrace je nastavení stejnosměrného posuvu měřeného signálu. Tento krok je nezbytný kvůli rozptylu parametrů tranzistoru BF998 použitého v oddělovacím zesilovači, testuje se při odpojeném měřeném vedení. Fázovému závěsu se nyní zapnou všechny výstupy, není však generován budicí impulz, výstup obvodu je ovládán firmwarem. Nejprve je nastavena logická úroveň 1, firmware postupně inkrementuje kódové slovo \acrshort{DAC}, dokud se nedostane měřené napětí do měřitelného rozsahu. Pokud tento test selže, je opět indikována chyba. Výstup pro budicí impulz se přepne do logické úrovně 0. Ze změřených napětí se spočítá, jak je nezbytné dále posunout měřený signál tak, aby průměr napětí v obou stavech ležel uprostřed rozsahu ADC. Podle tohoto výsledku je kódové slovo DAC inkrementováno nebo dekrementováno, dokud není dosaženo požadovaného stavu.

\subsection{Kalibrace napěťových úrovní}
V dalším kroku se provede kalibrace logických úrovní a zjištění úrovně šumu v měřeném signálu. V obou logických úrovních budicího pulzu je nejprve změřeno 4096 vzorků, ze kterých se spočítá průměr. Potom se změří dalších 4096 vzorků, které jsou použity pro spočítání rozptylu měřených hodnot. Tím se získá informace o statických napěťových úrovních pro stavy odpovídající vedení zakončenému otevřeným koncem a zkratem, tedy pro koeficienty odrazu $-1$ a $+1$, čímž je získán teoretický rozsah měřených hodnot. Rozptyl hodnot je podstatný pro odhad vhodného počtu průměrování. Vhodný počet průměrování byl uvažován jako počet průměrů, při kterých již byl šum podstatně potlačen, avšak dále by jeho úroveň klesala již pomalu.

\subsection{Odhad šumové úrovně a průměrování}
Pro průměrování je použit algoritmus, který se v minulosti objevil např. v osciloskopech značky Hewlett-Packard \cite{HP54100_article_journal}. Tento algoritmus je počítán celočíselně a pro svůj chod potřebuje množství paměti odpovídající pouze jedinému zaznamenanému průběhu. Pro algoritmus je potřeba jen soubor předchozích změřených dat $ y_{i-1}$, nový změřený vzorek $x$ a proměnná $i$ vyjadřující, kolikátý průměr je právě měřen. Při změření nového $n$-tého vzorku se odpovídající $n$-tý zprůměrovaný vzorek získá podle rovnice \ref{equation_averaging}.

\begin{equation}
\begin{gathered}
	y_i[n]=	\frac{x[n]+i \cdot y_{i-1}[n]}{i+1}
\end{gathered}
\label{equation_averaging}
\end{equation}

Tento algoritmus byl numericky simulován, nejprve v přesné podobě v plovoucí desetinné čárce a poté v celočíselné podobě. Pro simulaci byla použita náhodná data s rozptylem 1024, a tedy směrodatnou odchylkou 32. Tato hodnota je blízká reálně měřeným hodnotám v realizovaném zapojení reflektometru. Graf \ref{averaging_variance} vychází z dat simulovaných v plovoucí desetinné čárce, pro celočíselnou variantu není graf uveden, neboť rozdíl mezi nimi není rozpoznatelný. Rozdíly jsou znázorněny na následujících grafech. Výpočty byly provedeny $256\times$, výsledky byly zprůměrovány, aby byly křivky v grafech hladké. Bez průměrování jsou křivky lehce zatížené šumem.

\begin{figure}[htbp]
\caption{Závislost rozptylu na počtu provedených průměrů.}\label{averaging_variance}
\end{figure}	

Průběh této závislosti odpovídá funkci $\frac{1}{N}$, což je možné vizualizovat tak, že se rozptyl ve všech bodech pronásobí počtem průměrů, který danému bodu odpovídá. Na grafu \ref{averaging_float_difference_error} je vidět, že součin rozptylu s počtem průměrů je přibližně konstantní a odpovídá počátečnímu rozptylu. Diference rozptylu se pro větší počet průměrů než 16 blíží nule. Pro více než 16 průměrů, tedy polovinu směrodatné odchylky, tedy již úroveň šumu výrazně neklesá.

\begin{figure}[htbp]
\caption{Závislost diference rozptylu (červeně) a součinu rozptylu s počtem průměrů (modře) na počtu provedených průměrů pro výpočet v plovoucí desetinné řádce.}\label{averaging_float_difference_error}
\end{figure}

\begin{figure}[htbp]
\caption{Závislost diference rozptylu (červeně) a součinu rozptylu s počtem průměrů (modře) na počtu provedených průměrů pro celočíselné výpočty.}\label{averaging_integer_difference_error}
\end{figure}

V případě celočíselných výpočtů vypadá diference rozptylu podobně, ovšem ze součinu počtu průměrů a rozptylu je vidět, že závislost rozptylu na počtu průměrů neodpovídá již přesně hyperbolické funkci. Jde o vliv numerických chyb způsobovaných zaokrouhlováním výsledků. Pro větší počet průměrů než je směrodatná odchylka měřeného signálu, již znatelně stoupají numerické chyby. Význam tohoto faktu spočívá v tom, že již nestoupá odstup užitečného signálu od šumu, protože dominantním zdrojem šumu jsou chyby zaokrouhlování.

Výsledkem těchto simulací je odhad vhodného počtu průměru. Optimální počet průměrů $N$ tedy leží v rozsahu $\langle\frac{\sigma}{2}, \sigma \rangle$, kde $\sigma$ je směrodatná odchylka měřeného signálu. Po změření rozptylu měřeného signálu je tedy možné přímo odhadnout vhodný počet průměrování.

\subsection{Autokalibrace polohy budicího pulzu}
Při zapnutí fázového závěsu je fázový rozdíl mezi budicím signálem a vzorkovacím signálem náhodný. Proto je potřeba nejprve najít polohu budicího pulzu v měřených datech. Vzhledem k tomu, že není pro nedostatek RAM možné uložit celé měření a v uložených datech hledat budicí impulz, je využito přímého hledání náběžné hrany, kdy se ukládá pouze posledních 8 vzorků. Ta probíhá tak, že v obslužném přerušení se ukládá posledních 8 měřených vzorků, ze kterých se počítá průměr diferencí přes těchto 8 vzorků kvůli zvýšení imunity vůči šumu. Výpočet této průměrné diference je možné zjednodušit podle vzorce \ref{equation_difference_sum}. 

\begin{equation}
\begin{gathered}
	\mathit{diff}_{\mathrm{AVG8}}[n]= \dfrac{1}{8} \sum_{k=0}^7 \dfrac{x[n-k]-x[n-(k+1)]}{2}= \dfrac{x[n]-x[n-8]}{16}
\end{gathered}
\label{equation_difference_sum}
\end{equation}

Pak platí, že pro průměr $n$ diferencí je potřeba spočítat jen diferenci ze dvou vzorků vzdálených o~$n$~prvků. Tato operace tedy pro každý změřený vzorek vyžaduje jedinou matematickou operaci, a tedy zabere malé množství výpočetního času, díky čemuž je možné tento výpočet umístit do obslužného přerušení. Z tohoto spočteného průměru diferencí se hledá maximum, tedy oblast s nejvyšší strmostí. Během fáze hledání náběžné hrany je mimo přerušení sledována odhadnutá poloha náběžné hrany. Pokud se tato poloha čtyřikrát v řadě ocitne v tolerančním poli $\pm256$ bodů, je tato poloha uznána jako skutečná poloha náběžné hrany. Celá tato autokalibrační fáze probíhá s odpojeným měřeným systémem i prodlužovacím vedením. 

\begin{figure}[H]
\caption{Budicí pulz při připojeném standardu \quotedblbase load\textquotedblleft{} přímo k testovacímu portu. Červeně je vyznačena diference při průměrování přes 8 bodů. Maximum diference odpovídá přibližně středu náběžné hrany.}\label{rising_edge_port_load}
\end{figure}

\subsection{Kalibrace polohy roviny měření}
Následně je poloha měřicího okna nastavena 512 bodů před detekovanou hranu budicího pulzu. Reflektometr čeká na zásah uživatele, je vyžadováno připojení vedení, na jehož konec se později bude připojovat měřený systém. Na konec vedení je při tomto kalibračním kroku připojený kalibr typu \quotedblbase open\textquotedblleft. Průběh v okolí budicího pulzu je osmkrát změřen a zprůměrován. Ve změřeném průběhu jsou v oblasti odhadnuté náběžné hrany v rovině měření změřena počáteční napětí před náběžnou hranou a konečné napětí po náběžné hraně, odhad probíhá na základě maxima, ke kterému dochází na náběžné hraně v rámci překmitu. Následně proběhne hledání bodů, kde náběžná hrana prochází \SI{20}{\percent} a \SI{80}{\percent} mezi počátečním a konečným napětím. Z polohy těchto bodů je lineárně extrapolován počátek odezvy v rovině měření tak, aby při měření již nebyla měřena část sytému před rovinou měření. Budicí impulz je tedy po tomto kroku již mimo okno měření a nadále již v měření nijak nevystupuje. Ukázková odezva kalibru \quotedblbase open\textquotedblleft{} společně s vyznačenými význačnými body je na grafu \ref{rising_edge_DUT_open}.

\begin{figure}[H]
\caption{Odezva v rovině měření při připojeném standardu \quotedblbase open\textquotedblleft , čáry vyznačují úrovně \SI{20}{\percent} (tmavě červená) a \SI{80}{\percent} (tmavě zelená) náběžné hrany a jejich polohu v čase. Délka náběžné hrany v tomto úseku je \SI{180}{\pico\second}. Při měření mezi body \SI{10}{\percent} a \SI{90}{\percent} náběžné hrany je tato délka \SI{280}{\pico\second}.}\label{rising_edge_DUT_open}
\end{figure}

\section{Postup ovládání firmware}
Po zapnutí se zobrazí obrazovka s informací o verzi firmware, datu a času jeho kompilace. Její podoba je vidět na obrázku \ref{greeting_screen}. Všechny dále uvedené obrázky byly vyexportovány z běžícího zařízení, měly by tedy přesně odpovídat zobrazovaným informacím.
\begin{figure}[H]
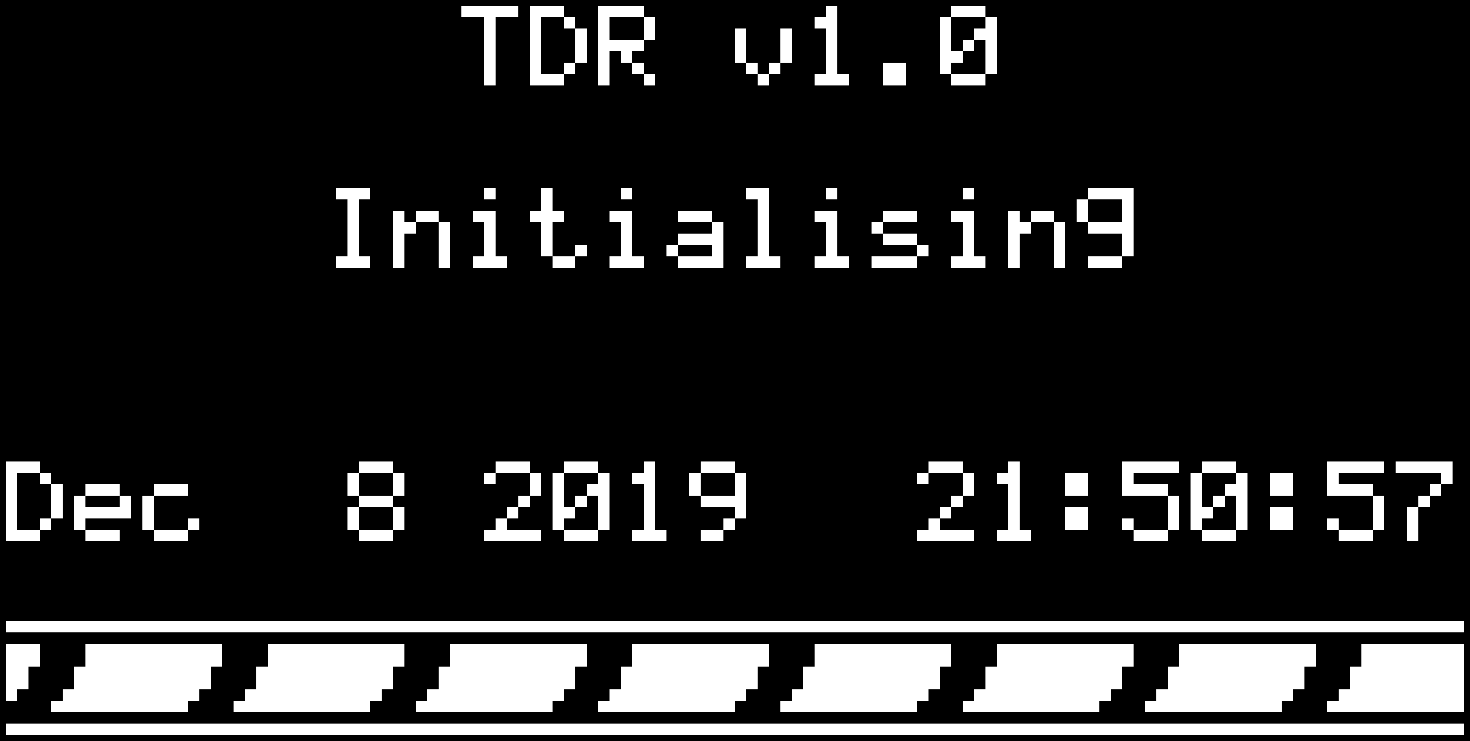
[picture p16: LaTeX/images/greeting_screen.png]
\caption{Uvítací obrazovka s informací o verzi.}\label{greeting_screen}
\end{figure}

Prozatím není zařízení interaktivní, pouze oznamuje stav autokalibračních postupů. Následuje detekce stability fázového závěsu, tuto část ukazují obrázky \ref{init_5351} a \ref{stability_5351}. Ukazatel ve spodní části je běžící, aby uživateli signalizoval, že zařízení běží a nezastavilo se například z důvodu nějaké chyby.
\begin{figure}[H]
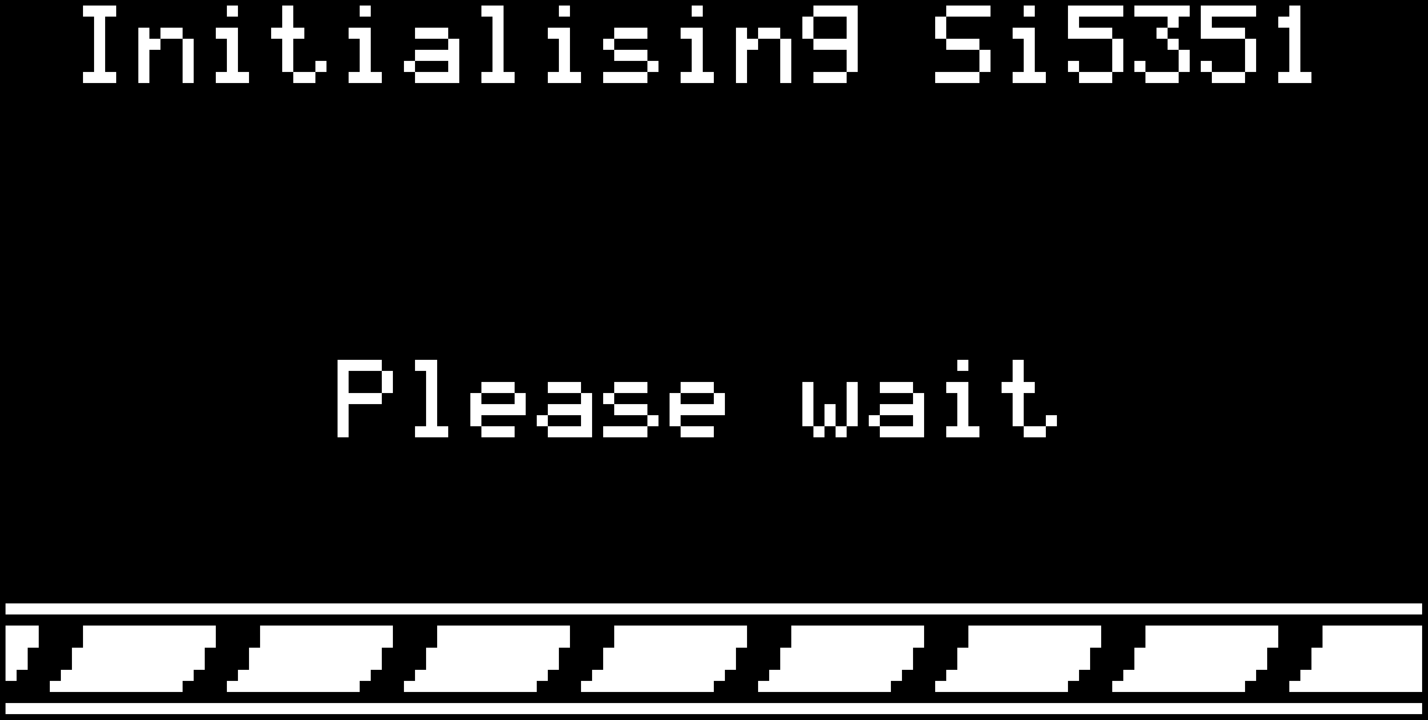
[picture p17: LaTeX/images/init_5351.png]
\caption{Obrazovka zobrazovaná po dobu inicializace fázového závěsu.}\label{init_5351}
\end{figure}

Po inicializaci následuje indikace stability jednotlivých částí PLL podle obrázku \ref{stability_5351}. V případě, že je vše v pořádku, zobrazí se hlášení \quotedblbase PLL Startup complete\textquotedblleft{} a program pokračuje dále. V případě, že dojde k chybě, program se zde zastaví s indikací chyby \quotedblbase PLL Startup error\textquotedblleft. 
\begin{figure}[H]
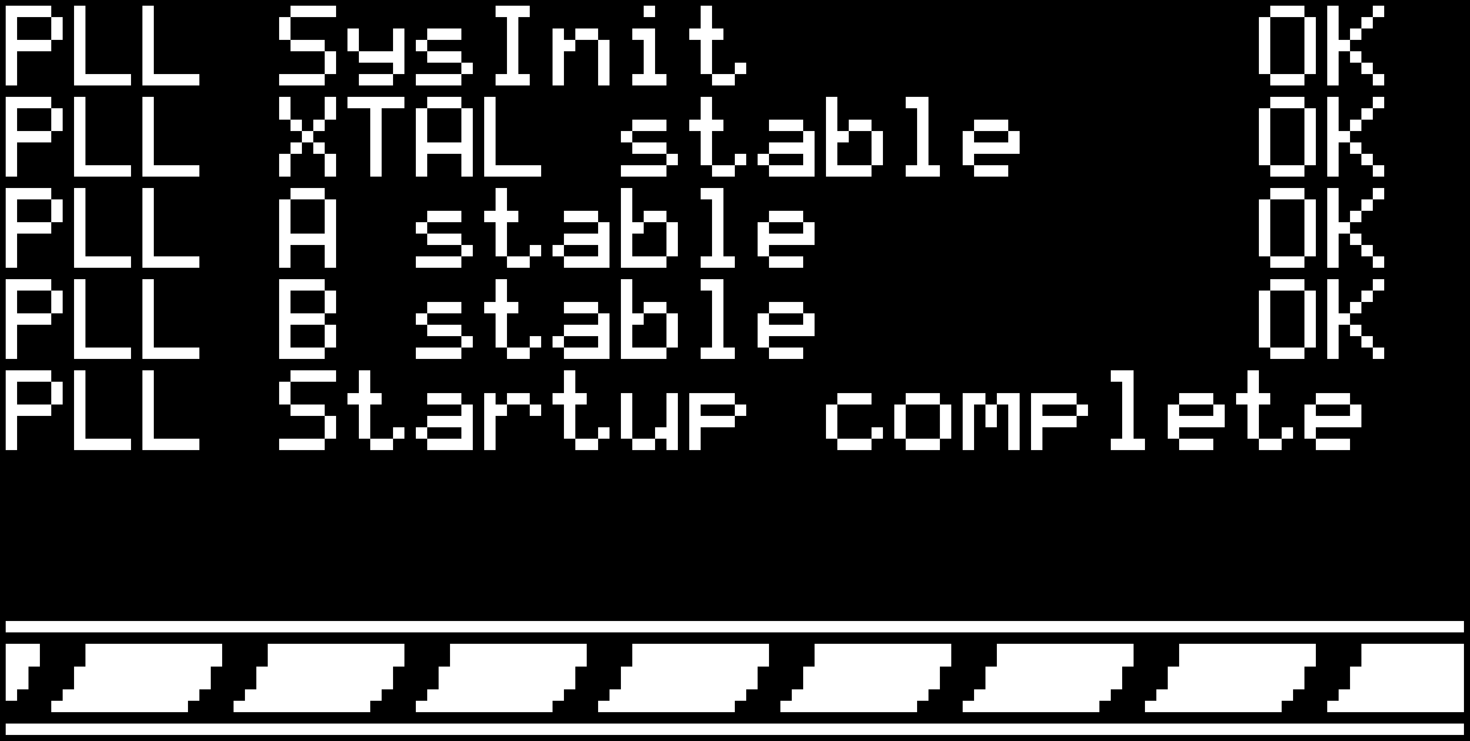
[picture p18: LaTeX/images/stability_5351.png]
\caption{Obrazovka s informacemi o stabilitě jednotlivých částí PLL Si5351.}\label{stability_5351}
\end{figure}

Před autokalibrací polohy budicího pulzu, autokalibrací stejnosměrné složky a odhadu šumové úrovně je uživatel požádán, aby odpojil od reflektometru všechna připojená vedení nebo DUT. Tento požadavek je uveden na obr. \ref{offset_user_wait}. V tuto chvíli se zastaví běžící ukazatel ve spodní části obrazovky, aby signalizoval čekání.
\begin{figure}[H]
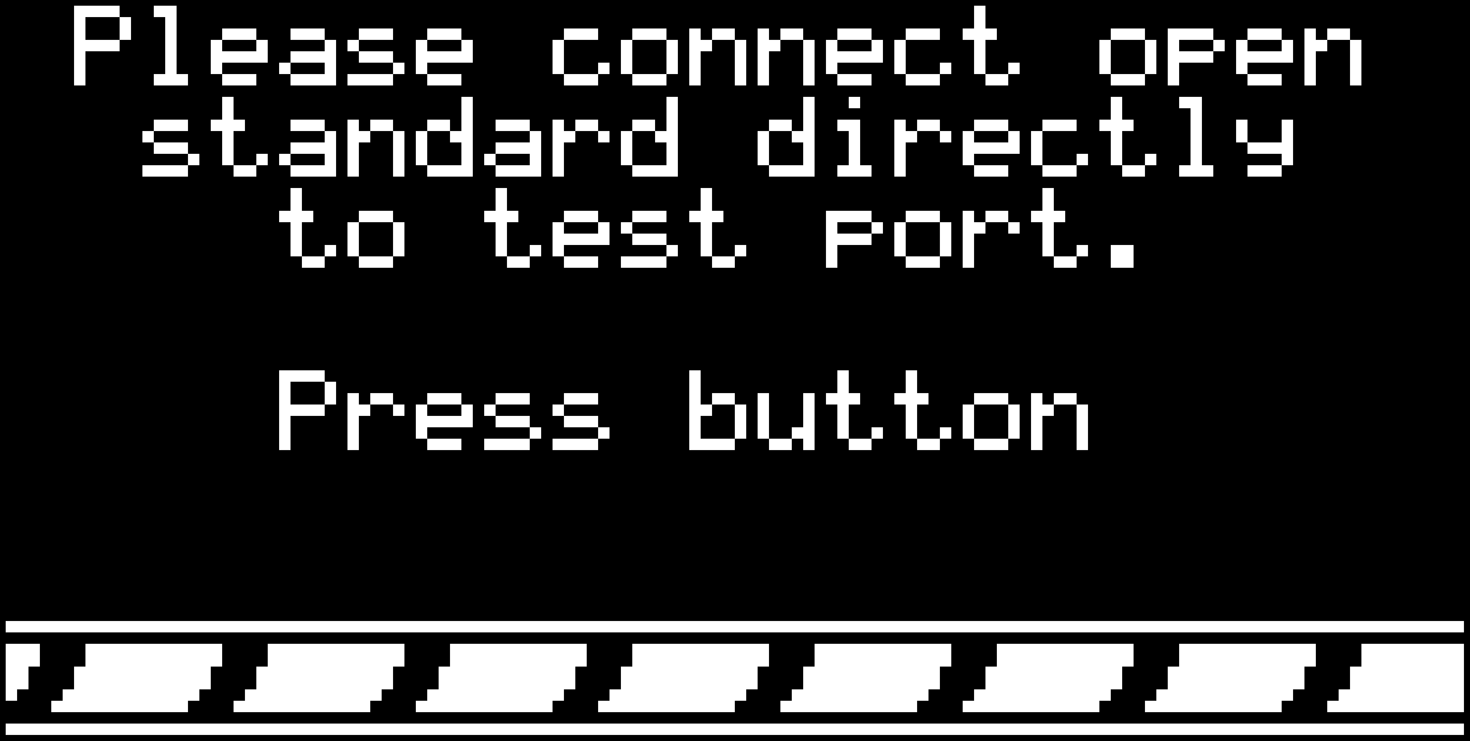
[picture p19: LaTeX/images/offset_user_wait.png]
\caption{Čekání na zásah uživatele - autokalibrace stejnosměrné složky, kalibrace úrovní a měření úrovně šumu.}\label{offset_user_wait}
\end{figure}

V průběhu autokalibračních kroků je uživatel postupně informován o probíhajícím kroku, případně o jeho postupu. Takto proběhne autokalibrace stejnosměrné složky (obr. \ref{offset_wait}) a měření napěťových úrovní a úrovně šumu (obr. \ref{levels_user_wait}). Následně je uživatel informován o výsledku autokalibrace napěťových úrovní a šumu (obr. \ref{levels_complete}), ze kterých je možné odhalit některé možné závady. Pokud by například jedna z úrovní byla rovna 0 nebo 4095, případně kdyby se obě přibližně rovnaly, pak je možné usuzovat na chybu ADC nebo hardwarovou závadu. Pokud by vyšla variance měřeného signálu příliš vysoká nebo příliš nízká, mohla by tato informace indikovat chybu vzorkovače.
\begin{figure}[H]
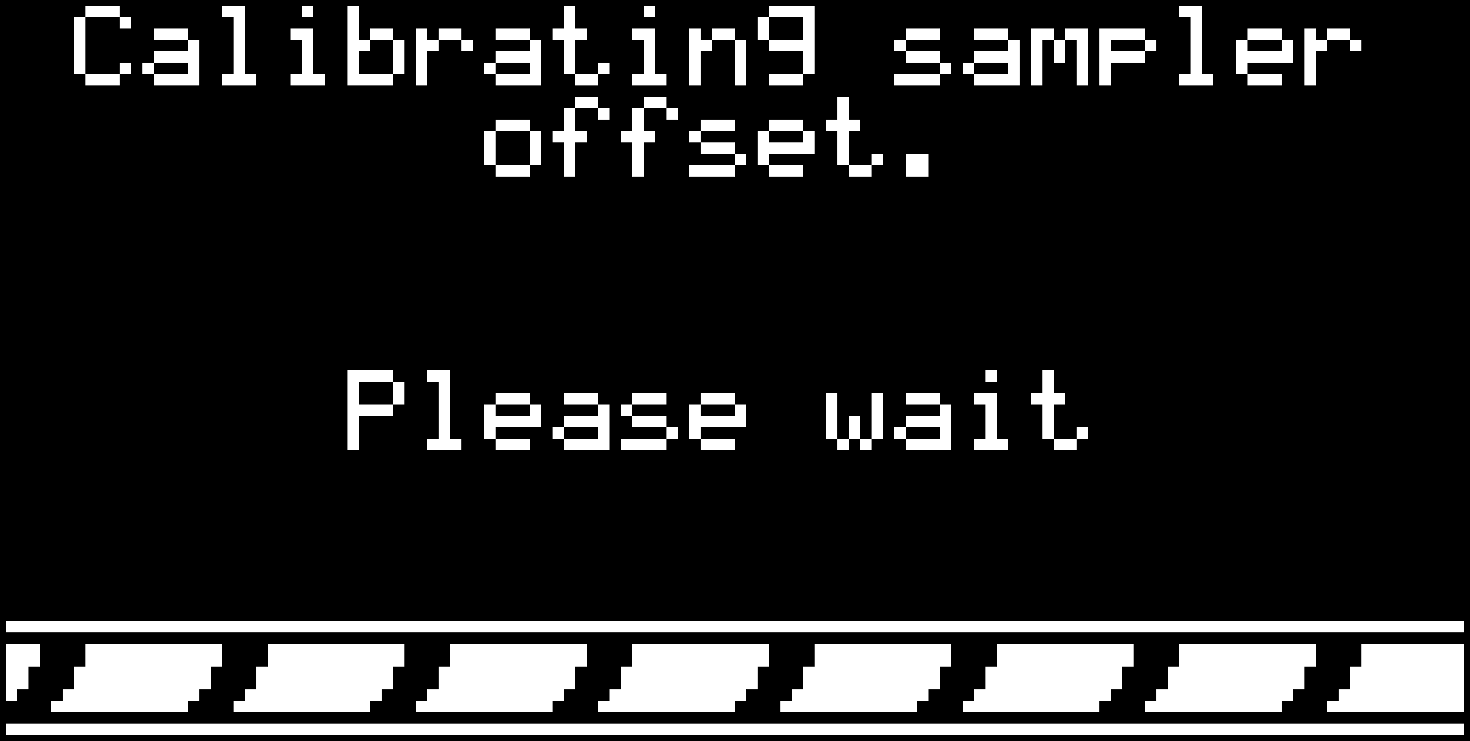
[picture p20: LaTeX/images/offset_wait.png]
\caption{Probíhající autokalibrace stejnosměrné složky.}\label{offset_wait}
\end{figure}

\begin{figure}[H]
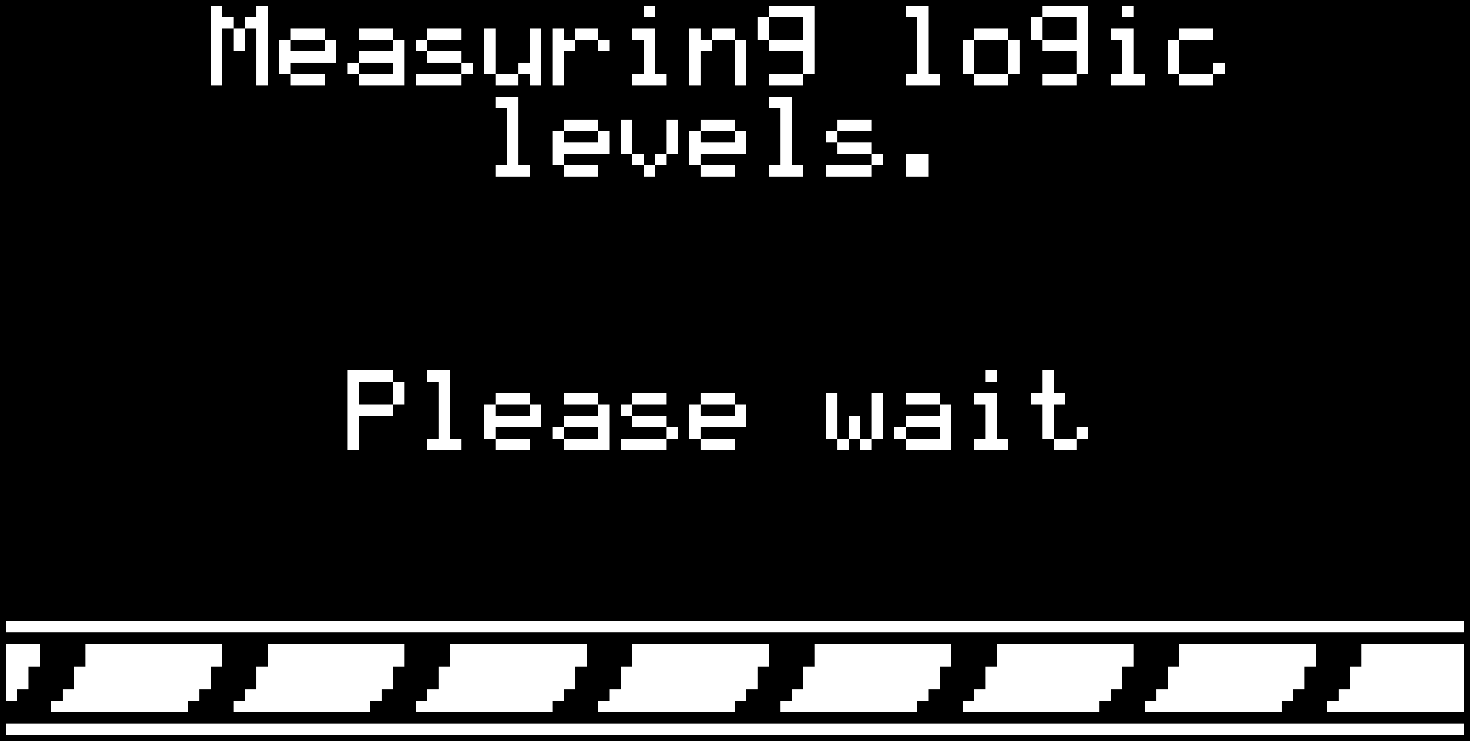
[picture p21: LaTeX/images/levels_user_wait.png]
\caption{Probíhající autokalibrace napěťových úrovní a měření úrovně šumu.}\label{levels_user_wait}
\end{figure}

\begin{figure}[H]
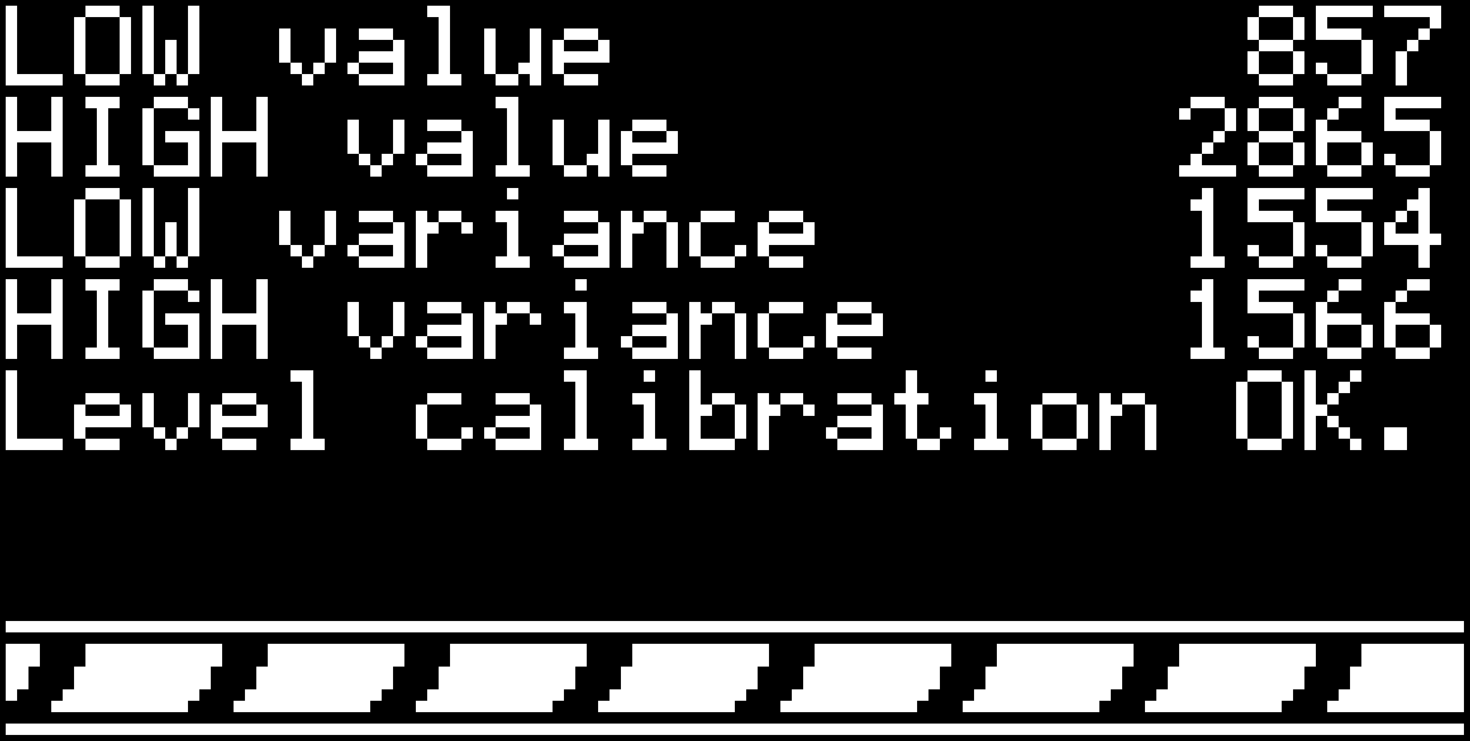
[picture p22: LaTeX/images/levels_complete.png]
\caption{Výsledek autokalibrace napěťových úrovní a měření šumu.}\label{levels_complete}
\end{figure}

Po změření napěťových a šumových úrovní následuje hrubé hledání náběžné hrany budicího signálu, indikováno je dle obr. \ref{edge_wait}.
\begin{figure}[H]
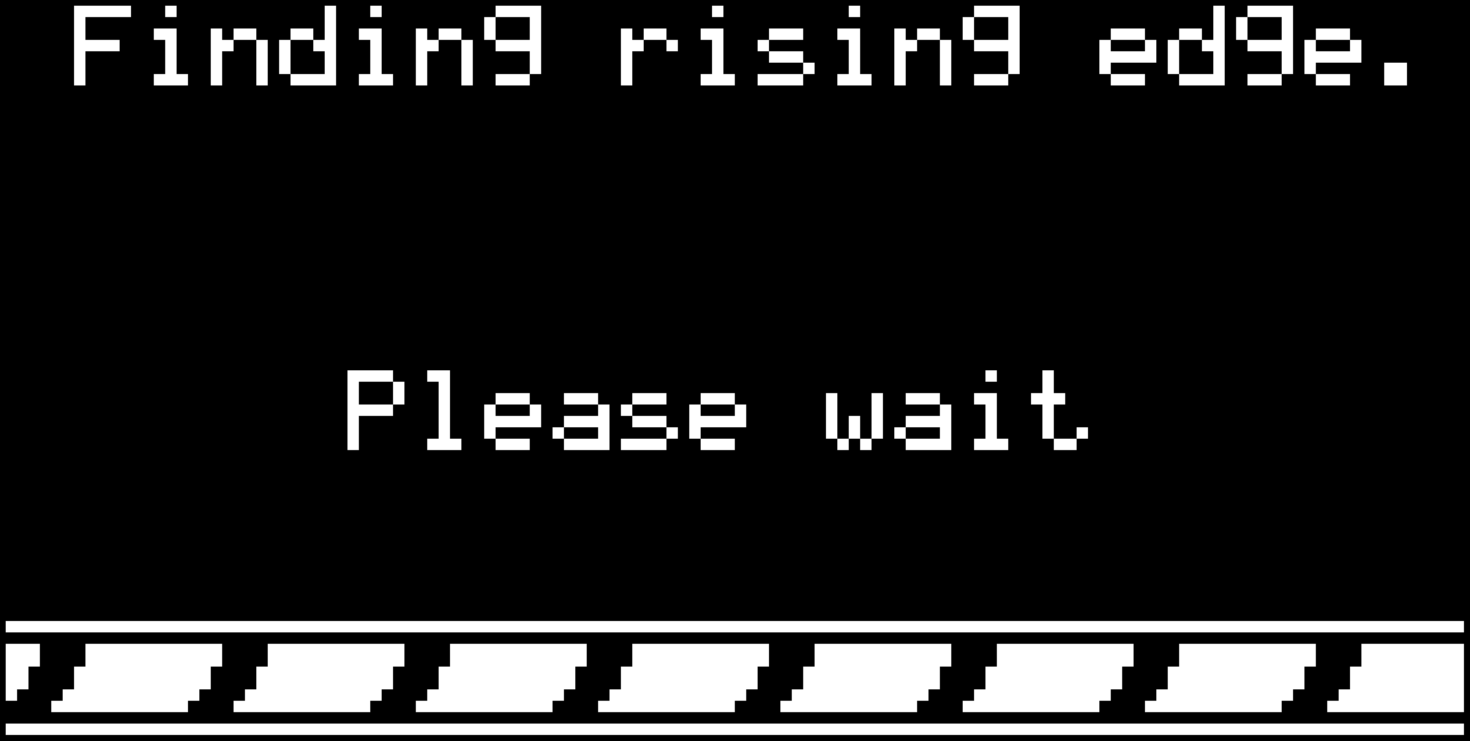
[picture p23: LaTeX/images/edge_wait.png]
\caption{Hrubé hledání náběžné hrany.}\label{edge_wait}
\end{figure}

Po hrubém nalezení polohy hrany budicího signálu je uživatel vyzván k připojení testovacího vedení a připojení standardu \quotedblbase open\textquotedblleft{} na konec vedení podle obr. \ref{edge_user_wait}.
\begin{figure}[H]
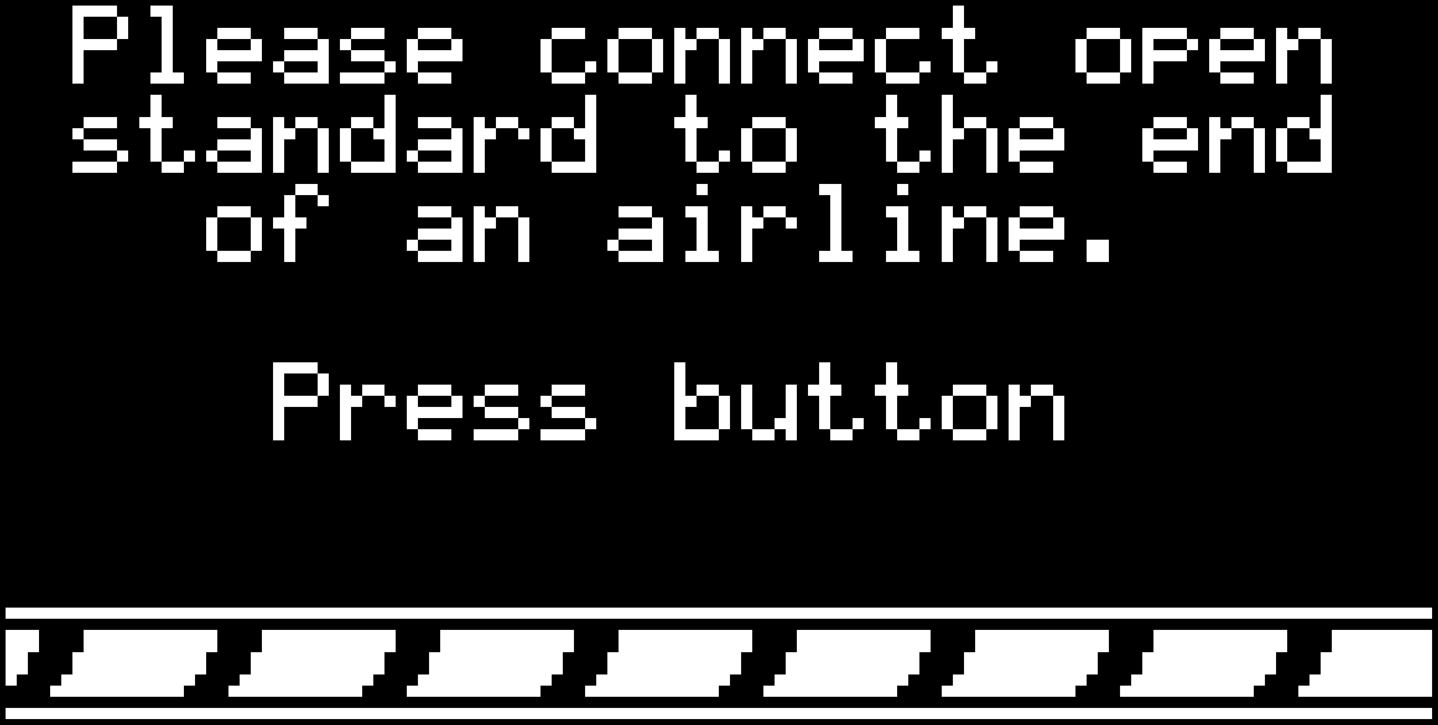
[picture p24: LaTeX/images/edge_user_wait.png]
\caption{Čekání na zásah uživatele - přesné hledání náběžné hrany.}\label{edge_user_wait}
\end{figure}

Přesné hledání polohy měřicí roviny trvá delší dobu, protože dochází k opakovanému měření a průměrování. Tento proces je tedy indikován ukazatelem průběhu, ze kterého je možné odhadnout, kdy bude proces dokončen. Tento krok je uveden na obr. \ref{edge_sampling}. Po dokončení hledání je zobrazeno potvrzení o úspěšném dokončení autokalibrace podle obr. \ref{edge_found}.
\begin{figure}[H]
\caption{Přesné hledání náběžné hrany.}\label{edge_sampling}
\end{figure}

\begin{figure}[H]
\caption{Úspěšné nalezení přesné polohy náběžné hrany.}\label{edge_found}
\end{figure}

Nyní je již zařízení připraveno k měření. Uživatel je dle obr. \ref{measurement_user_wait} vyzván k připojení DUT a potvrzení začátku měření tlačítkem.
\begin{figure}[H]
\caption{Čekání na zásah uživatele - připojení DUT a začátek měření.}\label{measurement_user_wait}
\end{figure}

Během prvního měření je zobrazena informace o čekání na dokončení prvního měření dle obr. \ref{measurement_avg_wait}.
\begin{figure}[H]
\caption{Čekání na proběhnutí prvního měření.}\label{measurement_avg_wait}
\end{figure}

V průběhu dalších měření je průběh každého měření indikován ukazatelem v levé spodní části obrazovky dle obr. \ref{measurement_running} a celkový počet změřených průběhů je uveden v pravé spodní části obrazovky. Změřený a zprůměrovaný průběh je vidět v horní části obrazovky.
\begin{figure}[H]
\caption{Průběh měření, 33. průměr.}\label{measurement_running}
\end{figure}

V případě, že je zařízení ovládáno z počítače, je na konci měření zobrazena výzva k vyčkání na odeslání zprůměrovaných změřených dat do počítače. Tato výzva je vyobrazena na obr. \ref{measurement_complete}.
\begin{figure}[H]
\caption{Měření dokončeno.}\label{measurement_complete}
\end{figure}

V případě, že je zařízení ovládáno bez využití počítače, přiblíží se změřená data tak, aby každý změřený bod odpovídal jednomu horizontánímu bodu na displeji. Začátek tohoto procesu je zachycen na obr. \ref{zooming_start}, konec tohoto procesu pak na obr. \ref{zooming_complete}.
\begin{figure}[H]
\caption{Měření dokončeno, začátek přibližování změřených dat.}\label{zooming_start}
\end{figure}

\begin{figure}[H]
\caption{Měření dokončeno, konec přibližování změřených dat.}\label{zooming_complete}
\end{figure}

Po přiblížení se změřený průběh začne plynule posouvat až k části průběhu, kde byla detekována diskontinuita na vedení podle obr. \ref{discontinuity_open_after_split}. Firmware jako diskontinuitu považuje jakoukoli část změřeného průběhu, kde diference průběhu odpovídá $\abs{\Gamma}>\SI{0.15}{}$. Zde několik sekund počká, aby si jej uživatel mohl prohlédnout. 
\begin{figure}[H]
\caption{Přiblížená data vycentrovaná na polohu diskontinuity.}\label{discontinuity_open_after_split}
\end{figure}

Následně se zobrazí informační text, který informuje o pořadí diskontinuity, koeficient odrazu v místě diskontinuity, detekovaný typ závady a polohu závady. Poloha je indikována v časových jednotkách, protože nejsou známé parametry vedení. Poloha je vztažena vůči detekované poloze roviny měření. Tato informační obrazovka je vyobrazena na obr. \ref{discontinuity_split}.
\begin{figure}[H]
\caption{Informační obrazovka o typu diskontinuity, obecná diskontinuita.}\label{discontinuity_split}
\end{figure}

Odezva na kalibr typu \quotedblbase open\textquotedblleft{} je na obr. \ref{discontinuity_open}. Z levé strany je průběh uprostřed obrazovky, odpovídá $\Gamma=0$, v místě diskontinuity přejde až k vrchnímu okraji obrazovky, který odpovídá $\Gamma=1$. Spodní okraj obrazovky odpovídá $\Gamma=-1$.
\begin{figure}[H]
\caption{Přiblížená odezva na kalibr typu \quotedblbase open\textquotedblleft .}\label{discontinuity_open}
\end{figure}

Průběhu na obr. \ref{discontinuity_open_report} odpovídá informační obrazovka z obr. \ref{discontinuity_open_report}. Koeficient $\Gamma$ je přibližně roven 1, odpovídá tedy odrazu na kalibru \quotedblbase open\textquotedblleft .
\begin{figure}[H]
\caption{Informační obrazovka o typu diskontinuity, kalibr typu \quotedblbase open\textquotedblleft .}\label{discontinuity_open_report}
\end{figure}

Poté, co jsou uživateli popsány všechny diskontinuity (firmware detekuje pouze 8 největších diskontinuit), zobrazí se informace o tom, že všechny diskontinuit již byly zobrazeny. Tato informace je vidět na obr. \ref{discontinuities_shown}. Poté je možné celé měření opakovat.
\begin{figure}[H]
\caption{Informační obrazovka o zobrazení všech diskontinuit.}\label{discontinuities_shown}
\end{figure}

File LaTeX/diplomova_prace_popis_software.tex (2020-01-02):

\chapter{Popis software}

Pojmem software je v této kapitole myšlen program, který je spuštěn v počítači, ke kterému je připojen reflektometr. Tento program slouží pro ovládání reflektometru, zobrazování změřených dat a kalibraci reflektometru. Kalibrace probíhá pomocí změření odezvy na tři mechanické kalibry. Software předpokládá ideální kalibry \quotedblbase open\textquotedblleft, \quotedblbase short\textquotedblleft{} a \quotedblbase match\textquotedblleft{}.

Software je napsán v prostředí GNU Octave a určen pro operační systém GNU/Linux. S menšími úpravami by mělo být možné tento software provozovat i pod operačním systémem Windows. Prostředí Octave je z převážné části kompatibilní s programovacím jazykem MATLAB, v lehce upravené podobě by mělo být možné ovládací program spustit i  v prostředí MATLAB. Prostředí Octave bylo zvoleno, protože jde o jazyk určený pro matematické úlohy, podobně jako MATLAB, ovšem je šířeno zdarma pod licencí GNU GPL, k obsluze reflektometru tedy není třeba pořizovat nákladnou licenci na prostředí MATLAB. Další výhodou je, že Octave je multiplatformní, a není tedy vázáno jen na běžné počítače, ale je možné jej provozovat i na levných jednodeskových počítačích, např. na Raspberry Pi.

\section{Ovládání software}

Nejprve software testuje dostupnost sériových portů podle obr. \ref{serial_probe}. Tento problém může na operačním systému GNU/Linux nastat v příadě, kdy uživatel, který prostředí Octave spouští, nemá dostatečná práva na přístup k sériovým portům. Druhou možností, kdy k této chybě může dojít, je v případě, kdy je Octave spouštěno z kontejneru Flatpak bez povolení k přístupu k hardware. V případě operačního systému Windows může být příčinou chyby buď nedostatečné oprávnění uživatele nebo otevření sériového portu jiným programem, protože oproti operačnímu systému GNU/Linux neumožňuje otevřít sériový port ve více programech najednou.
\begin{figure}[H]
\caption{Test dostupnosti sériových portů.}\label{serial_probe}
\end{figure}	

V případě, že dojde k problému s přístupem k sériovému portu, je o této skutečnosti uživatel informován včetně nápovědy, co je možné v tomto případě dělat podle obr. \ref{serial_port_unsupported}. Uveden je příklad opravy spouštěcího příkazu pro kontejnery Flatpak.
\begin{figure}[H]
\caption{Chybové hlášení o nedostupnosti sériových portů, oříznuto.}\label{serial_port_unsupported}
\end{figure}	

V případě, že je přístup k sériovým portům povolen, začne program vyhledávat virtuální sériové porty připojené přes USB, přičemž zobrazí hlášení jako na obr. \ref{serial_port_lookup}. Ty se v prostředí GNU/Linux jmenují \verb"/dev/ttyUSB*". 
\begin{figure}[H]
\caption{Hledání sériových portů.}\label{serial_port_lookup}
\end{figure}

Pokud není nalezen žádný virtuální sériový port, je zobrazeno hlášení na obrázku \ref{serial_no_port_available}, které vyzývá uživatele k připojení reflektometru. Pokud je vhodný port nalezen, zobrazí se hlášení z obrázku \ref{serial_port_found}.
\begin{figure}[H]
\caption{Hlášení v případě, kdy není připojen žádný virtuální sériový port.}\label{serial_no_port_available}
\end{figure}

\begin{figure}[H]
\caption{Hlášení v případě, kdy je nalezen vhodný virtuální sériový port.}\label{serial_port_found}
\end{figure}

Software následně nalezený port otestuje tak, že na něj pošle zprávu \verb"DEV?", na kterou očekává odpověď. V případě, že je součástí odpovědí text \verb"TDR5351_CORE", software použije tento port pro komunikaci s reflektometrem. Plná identifikace zařízení obsahuje ještě informaci o datu a času kompilace firmware, tento identifikátor je vidět na obr. \ref{serial_device_found}. Zařízení je následně poslán příkaz \verb"REM!", kterým je zařízení informováno o požadavku na dálkové ovládání. Software očekává potvrzení ve formě zprávy \verb"REM.", načež se spustí vlastní rozhraní pro ovládání reflektometru. Celý úspěšný proces potvrzování je ještě indikován zprávou na obr. \ref{serial_accepted}.
\begin{figure}[H]
\caption{Hlášení v případě, kdy je nalezen vhodný virtuální sériový port.}\label{serial_device_found}
\end{figure}

\begin{figure}[H]
\caption{Informace o úpěšném potvrzení vzdáleného přístupu.}\label{serial_accepted}
\end{figure}

Po připojení k reflektometru se zobrazí ovládací rozhraní, které je vidět na obr. \ref{gui_edge_wait}. V tuto chvíli čeká reflektometr na odpojení všech zařízení od měřicího portu a potvrzení uživatelem. To je možné udělat jak barevně zvýrazněným tlačítkem CONTINUE, tak stiskem tlačítka na reflektometru. V případě odpojení ovládacího programu je možné program znovu spustit, přičemž reflektometr tato událost nijak nezasáhne - není potřeba znovu provádět autokalibrace, ani se nepřeruší měření. Grafické rozhraní je možné k reflektometru připojit kdykoli, není potřeba jej spustit při zapínání reflektometru.
\begin{figure}[htbp]
\caption{Grafické rozhraní, čekání na zásahu uživatele - autokalibrace napěťových úrovní, úrovně šumu a hrubé pozice budicího pulzu.}\label{gui_edge_wait}
\end{figure}

Grafické rozhraní postupně uživatele provází autokalibrací, vždy poskytuje informace o aktuálním probíhajícím kroku. Zároveň informuje uživatele srozumitelnou formou o tom, co se od něj očekává. Veškerá tlačítka se podle aktuálního stavu automaticky uzamykají a odemykají, případně podbarvují nebo mizí tak, aby uživatel nemohl provést neočekávaný požadavek, který by v dané chvíli buď nedával smysl, případně uživatele mátl.

V okamžiku, kdy jsou provedeny všechny autokalibrační procesy, je uživateli předloženo rozhraní podle obr. \ref{dut_ready}. Objevily se nové ovládací prvky, tlačítko RUN a posuvník pro nastavení počtu průměrování. Uživatel může nastavit pomocí posuvníku požadovaný počet průměrování. Program automaticky nastaví na posuvníku počet průměrování, který je dle odhadu šumové úrovně ideální, nicméně uživatel může toto nastavení dle svých potřeb změnit v rozsahu \SIrange{1}{64}{}. 
\begin{figure}[htbp]
\caption{Grafické rozhraní, zařízení je připraveno na měření.}\label{dut_ready}
\end{figure}

Jakmile software obdrží první měřená data, zobrazí je v grafu jako na obr. \ref{measured_data}. Poté se odemknou ovládací prvky a s grafem je možné manipulovat. Graf je možné horizontálně i vertikálně zvětšovat i posouvat. V případě nastavení mimo změřená data je možné osy resetovat do původního stavu.
\begin{figure}[htbp]
\caption{Probíhající měření s aktuálními změřenými daty.}\label{measured_data}
\end{figure}

Ve stavu, kdy již bylo provedeno měření a reflektometr je připraven k dalšímu měření, je možné stisknout tlačítka na kalibračním panelu. Stiskem tlačítek \quotedblbase Open\textquotedblleft, \quotedblbase Short\textquotedblleft{} nebo \quotedblbase Load\textquotedblleft{} se uloží kalibrační data pro daný mechanický kalibr, který byl předtím takto změřen. Kalibrační data je možné odstranit opětovným stiskem tlačítka. Je-li tlačítko vybraveno žlutě, má software pro daný kalibr již uložena kalibrační data. Od okamžiku, kdy se uloží kalibrační data pro standard \quotedblbase load\textquotedblleft , je pro zobrazování změřených dat použita jednoduchá základní kalibrace, která spočívá v tom, že od měřených dat je odečten průběh dpovídající kalibru \quotedblbase load\textquotedblleft . Tato částečná kalibrace se dá vypnout pouze tak, že se odstraní data pro kalibr \quotedblbase load\textquotedblleft , protože bylo vypozorováno, že aplikace této základní kalibrace výrazně potlačuje stejnosměrný posun měřených dat a zvlnění průběhu. Toto zvlnění je opakovatelné a prakticky neměnné, proto je možné jej takto jednoduše potlačit. Rozdíl mezi zobrazovanými průběhy před a po této základní kalibraci je vidět na obrázcích \ref{calibration_running} a \ref{calibrations_performed}.

\begin{figure}[htbp]
\caption{Měřený průběh před základní kalibrací pomocí kalibru \quotedblbase load\textquotedblleft .}\label{calibration_running}
\end{figure}

\begin{figure}[htbp]
\caption{Měřený průběh po základní kalibrací pomocí kalibru \quotedblbase load\textquotedblleft .}\label{calibrations_performed}
\end{figure}

V okamžiku, kdy jsou změřeny všechny tři kalibrační průběhy, je možné zapnout plnou kalibraci. Ta je implementována formou OSL kalibrace \cite{VNAcalibrationarticle} s předpokládanými ideálními mechanickými kalibry. Zaškrtnutím políčka \quotedblbase Use calibration\textquotedblleft se přepne zobrazování z nekalibrovaných dat na zobrazení dat po OSL kalibraci. Zobrazená data po \acrshort{OSL} kalibraci jsou vidět na obrázku \ref{calibration_applied_on_new_short}.

\begin{figure}[htbp]
\caption{Měřený průběh po plné kalibraci OSL.}\label{calibration_applied_on_new_short}
\end{figure}

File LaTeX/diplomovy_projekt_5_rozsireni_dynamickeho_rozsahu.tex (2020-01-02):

\chapter{Rozšíření dynamického rozsahu, potlačování šumu a rušení}
Pro co nejpřesnější měření je nezbytné dosáhnout co největšího SNR (signal to noise ratio). Prvním limitujícím faktorem je dynamický rozsah ADC. V případě měření v reálném čase by bylo možné použít nanejvýš osmibitové převodníky, které mají dynamiku přibližně \SI{48}{\deci\bel} podle vztahu \ref{equation_dynamic_range}.
\begin{equation}
	 \mathit{DR}_n=20\log\left(2^n-1\right)
	 \label{equation_dynamic_range}
\end{equation}
Pro nižší rychlosti jsou dostupné již ADC s vyšší přesností, někdy již integrované přímo do mikrokontrolérů. Běžně se integrují převodníky až do \SI{1}{\megasample} při rozlišení 12~bitů, tedy s dynamickým rozsahem přibližně
\begin{equation}
	\mathit{DR}_{12}\doteq \SI{72}{\deci\bel}.
\end{equation}

Pro aplikace ve zvukové technice jsou pak dostupné šestnáctibitové až dvacetičtyřbitové převodníky (obvykle do \SI{96}{\kilosample}) s dynamikou od 
\begin{equation}
	\mathit{DR}_{16}\doteq \SI{96}{\deci\bel}.
\end{equation} až do
\begin{equation}
	\mathit{DR}_{24}\doteq \SI{144}{\deci\bel}.
\end{equation}
 Druhý údaj je však pouze teoretický, převodníky sice nabízejí tento počet bitů, ovšem jejich vlastní šum zpravidla omezuje použitelný rozsah na méně než \SI{100}{\deci\bel}. Přesné \SI{24}{\bit} převodníky, které mají skutečně dynamický rozsah odpovídající počtu bitů, vzorkují zpravidla nanejvýš na desítkách \si{\hertz}. Takové rychlosti jsou však pro použití v reflektometru příliš pomalé, neboť změření odezvy systému by bylo velice zdlouhavé.

Vzhledem k rychlosti se zdají být použitelné nanejvýš \SIrange{12}{16}{bitové} převodníky. Existují ovšem metody rozšíření dynamického rozsahu, zpravidla spoléhající na zkreslení měřených dat nelineární funkcí, která umožní navzorkovaná data inverzní funkcí převést zpět na původní signál, přičemž ale nedojde ke ztrátě přesnosti, nýbrž k jejímu zlepšení v určité části převodní charakteristiky. Pro účely telefonie se v minulosti používaly například komprese definované ve standardu G.711 od ITU-T. Tyto komprese umožňovaly komprimovat logaritmicky enkódovaná data z 14~bitů na 8, přičemž uživatel po dekompresi pozoroval výrazně menší zkreslení, než k jakému by došlo, pokud by bylo použita přímo osmibitová kvantizace.

Pro účely měření vysokofrekvenčních signálů se vyrábí logaritmické detektory s rozsahem až \SI{100}{\deci\bel} \cite{AD8309datasheet} \ref{ad8309function}. Pro nízké frekvence poskytuje např. detektor AD8309 \SI{85}{\deci\bel} dynamického rozsahu při toleranci $\pm \SI{1}{\deci\bel}$, tolerance je zakreslena v grafu \ref{ad8309error}. Logaritmus je prostá funkce, je tedy možné spočítat její inverzní funkci. Podle \ref{ad8309function} odpovídá vstupnímu rozsahu \SI{-70}{\deci\bel m}~až~+\SI{10}{\deci\bel m} výstupní rozsah o velikosti \SI{1.5}{\volt}. Při uvažování převodníku s referencí \SI{3.3}{\volt} a rozlišení 12~bitů odpovídá nejmenší měřitelný rozdíl napětí převodníkem \SI{0.8}{\milli\volt}, což s detektorem odpovídá vstupnímu rozlišení přibližně \SI{0.043}{\deci\bel}. Kombinací takového detektoru s dvanáctibitovým převodníkem a proložením dat získaných z lineárního a logaritmického měření je možné vytvořit převodník, který se přesností blíží rychlému šestnáctibitovému převodníku.

Pro potlačení šumu v měřeném průběhu je možné použít velké převzorkování signálu a aplikovat na tato data filtr pro potlačení šumu mimo užitečné pásmo. Dále je možné měřený průběh opakovaně měřit a statisticky zpracovávat (buď jednoduchým průměrem nebo např. Kalmanovými filtry).

Použitím měření v ekvivalentním čase je také možné redukovat rušení z okolí za předpokladu, že žádný násobek tohoto rušivého signálu není přesně roven vzorkovacímu kmitočtu. Pak se toto rušení projeví jako šum, který je možné odstranit či alespoň potlačit metodami zmíněnými v předchozím odstavci. V opačném případě je možné rušení potlačit pouze tak, že se provede měření s jinou vzorkovací frekvencí.

\begin{figure}[htbp]\caption{Převodní funkce logaritmického detektoru AD8309 \cite{AD8309datasheet}}\label{ad8309function}\end{figure}	

\begin{figure}[htbp]\caption{Chyba převodní funkce logaritmického detektoru AD8309 \cite{AD8309datasheet}}\label{ad8309error}\end{figure}

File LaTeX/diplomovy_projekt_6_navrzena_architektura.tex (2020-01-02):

\chapter{Navržené blokové zapojení reflektometru}
V předchozích kapitolách byly vysvětleny technologie, které byly uvažovány pro návrh architektury jednoduchého reflektometru a následně byly z nich vybrány ty nejvhodnější nebo nejjednodušší na implementaci. Pro jednotlivé části reflektometru tedy budou použity tyto stavební bloky:
\begin{itemize}
	\item
	\textbf{Buzení}\\*
	Pro buzení bude použito buzení aproximovaným jednotkovým skokem pomocí budiče technologie \acrshort{CML}, kterým je možné dosáhnout aproximace s náběžnou hranou o délce kratší než \SI{100}{\pico\second}, typicky okolo \SI{60}{\pico\second}, tedy s užitečnou šířkou pásma v jednotkách \si{\giga\hertz}. Výstup je dobře přizpůsoben pro použití v \SI{50}{\ohm} systémech.
	
	\item
	\textbf{Separace budicího a odraženého signálu}\\*	
	Pro separaci buzení od odezvy systému bude použito prodlužovací vedení jako metoda pro dosažení časového posunu. Samotná separace bude probíhat až z navzorkovaných dat během zpracování.
	
	\item
	\textbf{Vzorkování}\\*	
	Data budou sbírána pomocí postupného vzorkování v ekvivalentním čase pomocí vyvážených diodových můstků. Touto metodou je možné vzorkovat měřený signál pomocí pomalých převodníků s větším dynamickým rozsahem a přesností, je také možné potlačit ruchy z okolí. Byla navržena metoda pro měření s dynamickým rozsahem nejméně \SI{80}{\deci\bel}.
	
	\item
	\textbf{Generování signálů pro řízení reflektometru}\\*	
	Pro řízení jednotlivých částí reflektometru bude použita \acrshort{PLL} Si5351, která disponuje 8 výstupy, které je možné konfigurovat jako diferenciální výstupy. Jednotlivé výstupy mohou mít neceločíselné vzájemné poměry frekvencí (krok nastavení je menší než \SI{1}{ppm}), je možné dosáhnout vzorkování s krokem menším než \SI{100}{\pico\second}, tedy ekvivalentní vzorkovací frekvence větší než \SI{10}{\gigasample}. Díky proudovým výstupům je možné ji přímo propojit jak se vstupy \acrshort{CML} logických prvků, tak ji použít pro spínání diodových vzorkovačů. Je možné i vygenerovat synchronizační hodinový signál pro mikrokontrolér, aby se provádělo vzorkování v přesně stanovený čas.
\end{itemize}

Z těchto jednotlivých prvků je tedy již možné navrhnout základní blokové zapojení navrhované architektury. Toto blokové zapojení je na obrázku \ref{reflectometer_blockdiagram}.

\begin{figure}[htbp]\caption{Základní blokové schéma navržené architektury reflektometru.}\label{reflectometer_blockdiagram}\end{figure}

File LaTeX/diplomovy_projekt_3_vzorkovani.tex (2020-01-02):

\chapter{Vzorkování odraženého signálu}
Má-li být doržen Nyquistův vzorkovací teorém, je nezbytné vzorkovat budicí a odražený signál na nejméně dvakrát větší frekvenci, než se nachází nejvyšší frekvenční složka měřených signálů. Vybraný zdroj budicího signálu má šířku frekvenčního pásma až \SI{9}{\giga\hertz}, je tedy nezbytné, aby vzorkovač byl schopen vzorkovat alespoň na \SI{18}{\gigasample}. Tento vztah platí při zanedbání frekvenční charakteristiky vzorkovače, který se může chovat jako dolní propust, a tedy minimální vzorkovací frekvence může být nižší. Takovýmto vzorkovacím frekvencím se však blíží jen \quotedblbase folding\textquotedblleft{} ADC a Flash \acrshort{ADC}, které však při takovýchto rychlostech jsou nanejvýš osmibitové, tedy nabízejí dynamický rozsah nanejvýš \SI{48}{\deci\bel}. Nejrychlejší převodníky zatím (v roce 2019) nedosahují vzorkovacích frekvencí ani \SI{10}{\giga\hertz} při dostatčném dynamickém rozsahu. Pro rychlejší vzorkování se používá tzv. \gls{ADCinterleave}, tedy prokládání většího počtu převodníků. Pro přenos a zpracování dat z takto rychlých převodníků jsou potřeba i velmi rychlá FPGA, případně ještě signálové procesory. Tato metoda je ve výsledku v současné době velmi nákladná, navíc má malý dynamický rozsah.

Od doby prvních digitálních osciloskopů se používá technika známá jako vzorkování v \quotedblbase ekvivalentním čase\textquotedblleft . Tato metoda spočívá ve vzorkování periodického signálu přes větší množství jeho period, přičemž postupně se doplňují změřené body, dokud nejsou nalezeny všechny body měřeného průběhu. Hlavní nevýhoda tohoto postupu je nemožnost vzorkování jednorázových signálů (např. šum). Zásadní výhoda tohoto postupu je ovšem možnost částečně potlačit rušení z okolí, jsou-li asynchronní vůči vzorkování. Případně je možné i zvětšit dynamický rozsah, je-li použit rychlý vzorkovač pro navzorkování signálu pro pomalejší vícebitový \acrshort{ADC}. Existují dva základní přístupy, jak provádět toto vzorkování:
\begin{itemize}
	\item
		\textbf{Náhodné vzorkování}\\*		
		Vzorky jsou odebírány neustále, je zaznamenáván časový rozdíl mezi spouštěcí událostí (zde začátek budicího signálu) a nejbližší následující periodou vzorkovacího hodinového signálu. Postupně se tak náhodně doplňují naměřené body, až vznikne dostatečně přesný obraz měřeného signálu. Tato metoda je vhodná například pro osciloskopy, protože zpravidla není možné synchronizovat přesně vzorkovací hodinový signál se spouštěcí událostí.
		
	\item
		\textbf{Postupné vzorkování}\\*
		Vzorky jsou odebírány při každé periodě měřeného průběhu tak, že jednotlivé odebrané vzorky jsou časově seřazeny. Toho se dá dosáhnout fázovým posouváním vzorkovacího hodinového signálu oproti spouštěcí události, což je možné udělat pomocí digitálních zpožďovacích linek nebo tak, že vzorkovací hodinový signál a budicí signál budou mít nepatrně jinou frekvenci \cite{vernierreflectometer}. První řešení může být jednodušší na implementaci, ale zpožďovací linka omezuje krok měření a maximální počet odebraných vzorků \cite{fpgadelaylinereflectometer}, \cite{simpledelaylinereflectometer}. Druhé řešení se dá vytvořit pomocí \acrshort{DDS} \cite{ddsfpgareflectometer} nebo fázového závěsu, který podporuje násobení nebo dělení frekvencí neceločíselným násobkem. Do nedávné doby nebylo řešení pomocí fázových závěsů praktické, protože vyžadovalo fázový závěs pro vytvoření vysokofrekvenční reference a další dva fázové závěsy pro vytvoření dvou rozdílných frekvencí. V posledních letech se však objevily fázové závěsy, které všechny tyto funkce (včetně \acrshort{VCO}) integrují do jediného integrovaného obvodu a prakticky vyžadují pouze kmitočtovou referenci v podobě krystalu nebo krystalového oscilátoru \cite{ADF4350datasheet}, \cite{Si5351datasheet}.
\end{itemize}

\begin{figure}[htbp]\caption{Blokové zapojení \acrshort{PLL} Si5351 \cite{Si5351datasheet}.}\label{5351blockdiagram}\end{figure}

Vzhledem k existenci dostupných fázových závěsů umožňujících velkou integraci a miniaturizaci zapojení bylo zvoleno postupné vzorkování pomocí fázového závěsu. Vybraný fázový závěs Si5351 obsahuje v jednom pouzdře dva neceločíselné fázové závěsy \cite{Si5351datasheet}, dva vysokofrekvenční \acrshort{VCO} a osm výstupních neceločíselných děliček. Díky tomuto vývoji v integraci je možné celý hodinový generátor zmenšit do podoby jednoho integrovaného obvodu, jedinou potřebnou externí součástkou je krystal nebo krystalový oscilátor. Neceločíselná část násobiče frekvence umožňuje krok po $2^{{-20}}$ referenční frekvence, je tedy možné měnit podíl frekvencí hodinových signálů s krokem menším než \SI{1}{\ppm}. Při rozdílu frekvencí \SI{1}{\ppm} je počet vzorkovaných bodů celkem 1\,000\,000, což je počet bodů, který je prakticky nedosažitelný se zpožďovacími linkami.
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

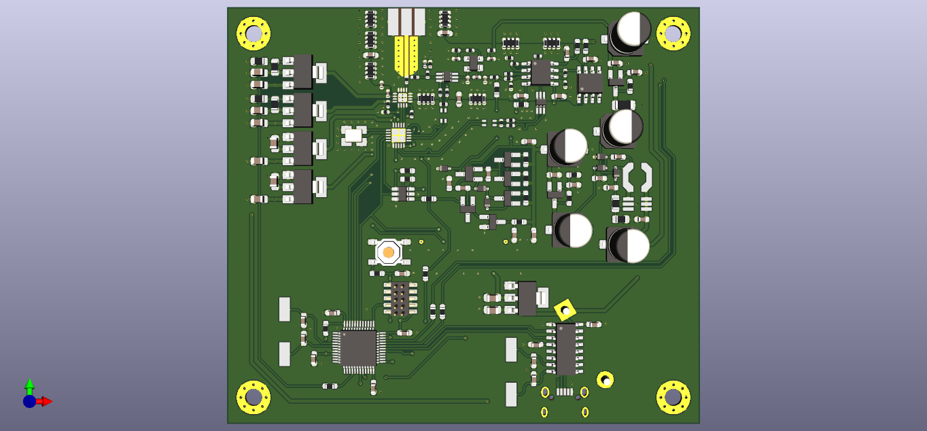
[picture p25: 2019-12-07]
Hardware/images/TDR_5351_core.png

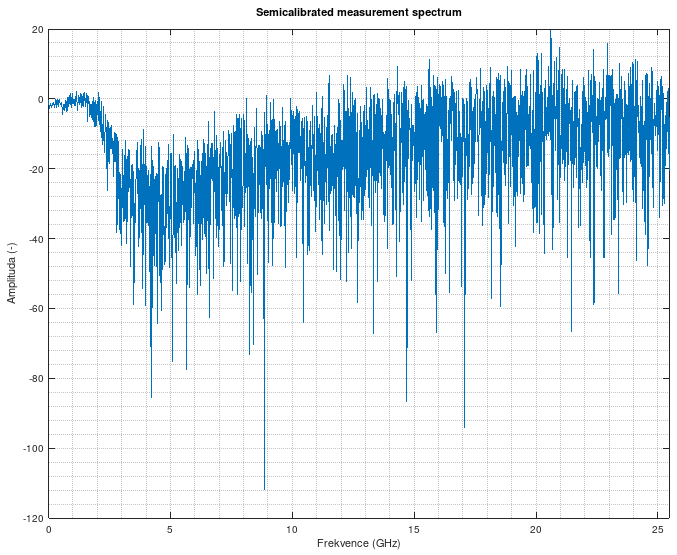
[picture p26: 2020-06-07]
obhajoba/semical_spectrum.png

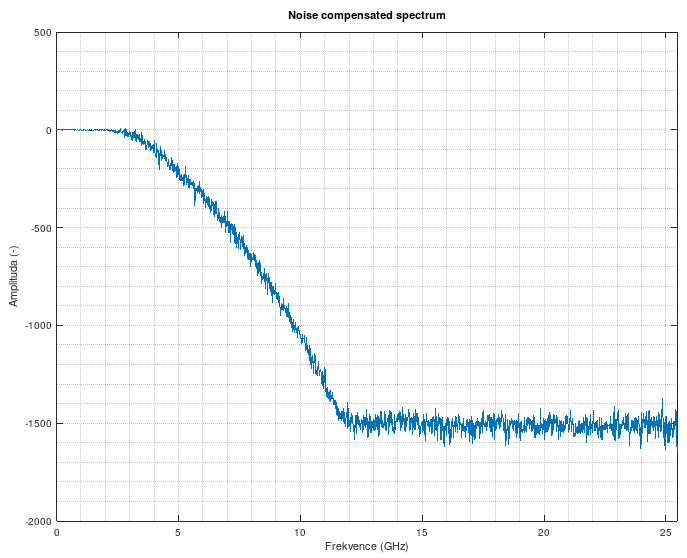
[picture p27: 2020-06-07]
obhajoba/nr_spectrum.png

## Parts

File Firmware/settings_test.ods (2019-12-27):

MASTER OFFSET | SLAVE INVERT | SLAVE OFFSET | ADC INVERT | ADC OFFSET | LOW variation | HIGH variation | OK?
0 | OFF | 0 | OFF | 0 | 29 | 34 | NOK
0 | OFF | 0 | OFF | 127 | 28 | 32 | NOK
0 | OFF | 0 | ON | 0 | 46 | 53 | NOK
0 | OFF | 0 | ON | 127 | 45 | 53 | NOK
0 | OFF | 127 | OFF | 0 | 27 | 32 | NOK
0 | OFF | 127 | OFF | 127 | 29 | 32 | NOK
0 | OFF | 127 | ON | 0 | 48 | 55 | NOK
0 | OFF | 127 | ON | 127 | 49 | 56 | NOK
0 | ON | 0 | OFF | 0 | 1803 | 1622 | OK
0 | ON | 0 | OFF | 127 | 1674 | 1594 | OK
0 | ON | 0 | ON | 0 | 1241 | 1215 | OK
0 | ON | 0 | ON | 127 | 1194 | 1277 | OK
0 | ON | 127 | OFF | 0 | 1539 | 1451 | OK
0 | ON | 127 | OFF | 127 | 2012 | 1625 | OK
0 | ON | 127 | ON | 0 | 1227 | 1252 | OK
0 | ON | 127 | ON | 127 | 1277 | 1303 | OK
127 | OFF | 0 | OFF | 0 | 29 | 30 | NOK
127 | OFF | 0 | OFF | 127 | 27 | 28 | NOK
127 | OFF | 0 | ON | 0 | 48 | 53 | NOK
127 | OFF | 0 | ON | 127 | 45 | 51 | NOK
127 | OFF | 127 | OFF | 0 | 27 | 31 | NOK
127 | OFF | 127 | OFF | 127 | 27 | 30 | NOK
127 | OFF | 127 | ON | 0 | 44 | 49 | NOK
127 | OFF | 127 | ON | 127 | 48 | 51 | NOK
127 | ON | 0 | OFF | 0 | 1656 | 1692 | OK
127 | ON | 0 | OFF | 127 | 1649 | 1732 | OK
127 | ON | 0 | ON | 0 | 1327 | 1236 | OK
127 | ON | 0 | ON | 127 | 1131 | 1202 | OK
127 | ON | 127 | OFF | 0 | 1584 | 1641 | OK
127 | ON | 127 | OFF | 127 | 1636 | 1579 | OK
127 | ON | 127 | ON | 0 | 1300 | 1148 | OK
127 | ON | 127 | ON | 127 | 1180 | 1265 | OK
MASTER OFFSET | SLAVE INVERT | SLAVE OFFSET | ADC INVERT | ADC OFFSET | LOW variation | HIGH variation | OK? | LOW | HIGH | Pk-pk | Refl. Open | Averages | Signal/noise | Refl.error
0 | ON | 0 | OFF | 0 | 1803 | 1622 | OK | 968 | 2965 | 1997 | 1.071 | 43 | 47.0305655794649 | 0.071
0 | ON | 0 | OFF | 127 | 1674 | 1594 | OK | 997 | 3016 | 2019 | 1.027 | 41 | 49.3467542046854 | 0.027
0 | ON | 0 | ON | 0 | 1241 | 1215 | OK | 1016 | 2850 | 1834 | NOK! | 36 | 52.0611120471956 | #VALUE!
0 | ON | 0 | ON | 127 | 1194 | 1277 | OK | 1048 | 2908 | 1860 | NOK! | 36 | 52.0496118973884 | #VALUE!
0 | ON | 127 | OFF | 0 | 1539 | 1451 | OK | 973 | 2996 | 2023 | 1.043 | 40 | 51.5675588466829 | 0.043
0 | ON | 127 | OFF | 127 | 2012 | 1625 | OK | 949 | 2957 | 2008 | 1.078 | 45 | 44.7661473915981 | 0.078
0 | ON | 127 | ON | 0 | 1227 | 1252 | OK | 1059 | 2879 | 1820 | 1.056 | 36 | 51.4362411239242 | 0.056
0 | ON | 127 | ON | 127 | 1166 | 1292 | OK | 1078 | 2973 | 1895 | 1.042 | 36 | 52.7203102660738 | 0.042
127 | ON | 0 | OFF | 0 | 1656 | 1692 | OK | 1002 | 3036 | 2034 | 1.079 | 42 | 49.4482321177863 | 0.079
127 | ON | 0 | OFF | 127 | 1649 | 1732 | OK | 1047 | 3095 | 2048 | 1.061 | 42 | 49.2102995284186 | 0.061
127 | ON | 0 | ON | 0 | 1327 | 1236 | OK | 1030 | 2872 | 1842 | 1.056 | 37 | 50.5654835197592 | 0.056
127 | ON | 0 | ON | 127 | 1131 | 1202 | OK | 986 | 2820 | 1834 | NOK! | 35 | 52.8989555741127 | #VALUE!
127 | ON | 127 | OFF | 0 | 1584 | 1641 | OK | 1038 | 3052 | 2014 | 1.08 | 41 | 49.7170298701592 | 0.08
127 | ON | 127 | OFF | 127 | 1636 | 1579 | OK | 985 | 3002 | 2017 | 1.035 | 41 | 49.8671155933839 | 0.035
127 | ON | 127 | ON | 0 | 1300 | 1148 | OK | 1090 | 2915 | 1825 | 1.067 | 37 | 50.6163929055522 | 0.067
127 | ON | 127 | ON | 127 | 1180 | 1265 | OK | 1066 | 2891 | 1825 | NOK! | 36 | 51.3118420867924 | #VALUE!

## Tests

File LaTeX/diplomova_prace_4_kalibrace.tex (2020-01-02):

\chapter{Kalibrace}

\section{Autokalibrace úrovní}
Vzhledem k omezenému množství paměti RAM v použitém mikrokontroléru a omezenému výkonu se při použití bez počítače používá pouze autokalibrace napěťových úrovní. Ty se detekují během autokalibračního kroku se standardem open. Touto metodou jsou získány napěťové úrovně odpovídající koeficientům odrazu $\Gamma=\SI{1}{}$ a $\Gamma=\SI{-1}{}$. Takto získané úrovně jsou použity pro zobrazení měřených dat do rozsahu $\Gamma\in\left\langle 1, -1 \right\rangle $ pomocí bilineárního mapování podle rovnice \ref{equation_normalization}.Tímto krokem je téměř odstraněn případný stejnosměrný posuv změřených dat, zároveň jsou data znormována. Tato autokalibrace však probíhá pouze pro dvě statické hodnoty, jedná se tedy prakticky o stejnosměrné měření a ne vždy přesně odpovídá pozdějším měřením, které již probíhají při zapnutém budicím signálu. Po této autokalibraci tedy stále může být v zobrazovaných datech přítomna stejnosměrná složka, případně nemusí plně odpovídat koeficient odrazu. Podle opakovaných testů s kalibračními standardy \quotedblbase short\textquotedblleft{} a \quotedblbase open\textquotedblleft{} je však tato chyba normování typicky menší než $\Delta\Gamma=\pm\SI{0.1}{}$. Tato autokalibrace probíhá ve firmware, používá ji i software, dokud není provedena OSL kalibrace. Změřené průběhy pro všechny tři kalibrační standardy po autokalibraci jsou zaneseny v grafu \ref{standards_after_autocalibration}. Na všech třech průbězích je vidět shodné zvlnění, stejnosměrný posuv a chyba normalizace.

\begin{equation}
\begin{gathered}
	\Gamma[n]=2\cdot\dfrac{U[n]-U_\mathrm{short}}{U_\mathrm{open}-U_\mathrm{short}} -1
\end{gathered}
\label{equation_normalization}
\end{equation}

\begin{figure}[htbp]
\caption{Průběhy odpovídající změřeným standardům po autokalibraci. Modře je označen průběh odpovídající kalibru \quotedblbase open\textquotedblleft , červeně pro kalibr \quotedblbase short\textquotedblleft{} a žlutě pro kalibr \quotedblbase load\textquotedblleft .}\label{standards_after_autocalibration}
\end{figure}

\begin{figure}[htbp]
\caption{Průběhy odpovídající změřeným standardům po základní kalibraci. Modře je označen průběh odpovídající kalibru \quotedblbase open\textquotedblleft , červeně pro kalibr \quotedblbase short\textquotedblleft{} a žlutě pro kalibr \quotedblbase load\textquotedblleft .}\label{standards_after_load_calibration}
\end{figure}

\section{Základní kalibrace pomocí standardu \quotedblbase open\textquotedblleft}
Jako základní metoda kalibrace pro potlačení zvlnění a stejnosměrného posuvu byla zvolena kalibrace pomocí standardu \quotedblbase load\textquotedblleft . V grafu \ref{standards_after_load_calibration} jsou vidět průběhy po základní kalibraci provedené pomocí odečtení změřeného průběhu pro kalibr \quotedblbase load\textquotedblleft{} od všech třech průběhů. Ve změřených datech tak bylo výrazně potlačeno zvlnění a stejnosměrný posuv. Zároveň byl z měřených dat odstraněn budicí pulz. Tato základní metoda kalibrace je automaticky aplikována, jakmile uživatel provede kalibraci se standardem \quotedblbase load\textquotedblleft{} a uloží kalibrační data pro tento standard. Jak je však vidět v grafu, nedochází k opravě chybné normalizace.

\section{Kalibrace typu OSL}

\subsection{Chybový model}
Systematické chyby měření reflektometru jsou idealizovány pomocí lineárního dvoubranu, který je virtuálně vložen mezi idealizovaný měřicí port reflektometru a \acrshort{DUT}. Tento model a odvození odstranění jeho vlivu byl převzat z \cite{time_domain_analyzer_calibration} a \cite{time_domain_analyzer_calibration_normalization}. Znázornění chybového modelu se nachází v grafu \ref{error_model}. Jako $a_0$ je označena napěťová vlna z generátoru budicích pulzů, $b_0$ je napěťová vlna měřená reflektometrem. Chybový model jeuvažován pro práci ve frekvenční doméně. S-parametr měřený reflektometrem je označen jako $S_\mathrm{M}$. Skutečný S-parametr DUT je uveden jako $S_\mathrm{A}$. Chybový model obsahuje čtyři chybové parametry, přičemž jeden byl normalizován na 1 a stal se součástí jednoho ze třech zbývajících parametrů, a sice $E_\textrm{R}$. Pro jednostranné měření, které se používá pro reflektometr pracující pouze v režimu TDR a nikoli \acrshort{TDT}, je možné takto redukovat počet stupňů volnosti a ke kalibraci tak stačí pouze tři mechanické kalibry místo čtyř. Parametr $E_\textrm{D}$ je chyba direktivity, která vyjadřuje prosakování budicího pulzu do měřených dat. Parametr $E_\textrm{R}$ je sdružená chyba dopředného a zpětného přenosu chybového dvoubranu, vyjadřuje útlum mezi reflektometrem a DUT, který je způsobený např. útlumem použitého vedení. Parametr $E_\textrm{S}$ vyjadřuje odraz od reflektometru, popř. jeho prodlužovacího vedení.
\begin{figure}[htbp]
\caption{Chybový model reflektometru.}\label{error_model}
\end{figure}

Podle \cite{time_domain_analyzer_calibration_normalization} odpovídá měřený koeficient odrazu
\begin{equation}
\begin{gathered}
	S_\mathrm{M} = E_\textrm{D} + E_\textrm{R} \left( \dfrac{S_\mathrm{A}}{1-E_\mathrm{S} S_\mathrm{A}} \right). 
\end{gathered}
\end{equation}

Z této rovnice je možné získat skutečný koeficient odrazu měřeného DUT
\begin{equation}
\begin{gathered}
	S_\mathrm{A} = \dfrac{S_\mathrm{M} - E_\textrm{D}}{E_\textrm{R} + E_\textrm{S} \left( S_\mathrm{M} - E_\textrm{D} \right) }.
\end{gathered}
\label{equation_s_parameter_calibration}
\end{equation}

Pro idealizované mechanické kalibry je možné jednoduše získat parametry chybového modelu pomocí dosazení jejich idealizovaných S-parametrů
\begin{equation}
\begin{gathered}
S_\mathrm{M}=
   \begin{dcases}
	S_\mathrm{ML} = E_\textrm{D} & S_\mathrm{A}=0	\\
	S_\mathrm{MO} = E_\textrm{D} + \dfrac{E_\textrm{R}}{1-E_\mathrm{S}}  & S_\mathrm{A}=+1	\\
	S_\mathrm{MS} = E_\textrm{D} - \dfrac{E_\textrm{R}}{1+E_\mathrm{S}}  & S_\mathrm{A}=-1.
   \end{dcases}
\end{gathered}
\end{equation}

Pak je možné odvodit výpočty jednotlivých chybových parametrů
\begin{equation}
\begin{gathered}
   E_\textrm{D}=S_\mathrm{ML} \\
   E_\mathrm{S}=\dfrac{\left( \dfrac{S_\mathrm{MO}-S_\mathrm{ML}}{S_\mathrm{MS}-S_\mathrm{ML}}\right)  +1}{\left( \dfrac{S_\mathrm{MO}-S_\mathrm{ML}}{S_\mathrm{MS}-S_\mathrm{ML}}\right) -1} = \dfrac{S_\mathrm{MO} + S_\mathrm{MS} -2\cdot S_\mathrm{ML}}{S_\mathrm{MO} - S_\mathrm{MS}} \\
   E_\mathrm{R}=\dfrac{2}{\left( \dfrac{1}{S_\mathrm{MO}-S_\mathrm{ML}}\right)  - \left( \dfrac{1}{S_\mathrm{MS}-S_\mathrm{ML}} \right) } = \dfrac{\left( S_\mathrm{MS} - S_\mathrm{ML} \right) \cdot \left( S_\mathrm{MO} - S_\mathrm{ML} \right) }{S_\mathrm{MS} - S_\mathrm{MO}}.
\end{gathered}
\end{equation}

Pro kalibraci je tedy nezbytné změřit tři kalibrační standardy, výsledkem jsou tři sady S-parametrů, jejichž dosazením do vzorce \ref{equation_s_parameter_calibration} získáme skutečné S-parametry měřeného DUT. Kalibrace probíhá ve frekvenční doméně, pro kalibraci je tedy nezbytné změřená data jednotlivých kalibrů i DUT převést pomocí Fourierovy transformace do frekvenční domény, provést kalibraci a převést inverzní Fourierovou transformací zpět do časové domény.

Pokud se za měřená data dosadí jeden z použitých kalibrů, je výsledkem odpovídající koeficient odrazu v $t=0$, což bylo ověřeno i symbolicky pomocí matematického symbolického nástroje wxMaxima. Bohužel pro jiná měřená data již výsledek neodpovídá očekávání, nepovedlo se zjistit, proč tomu tak je. Software tak má tedy implementovanou kalibrační metodu OSL, avšak z neznámých důvodů nepracuje dle očekávání.

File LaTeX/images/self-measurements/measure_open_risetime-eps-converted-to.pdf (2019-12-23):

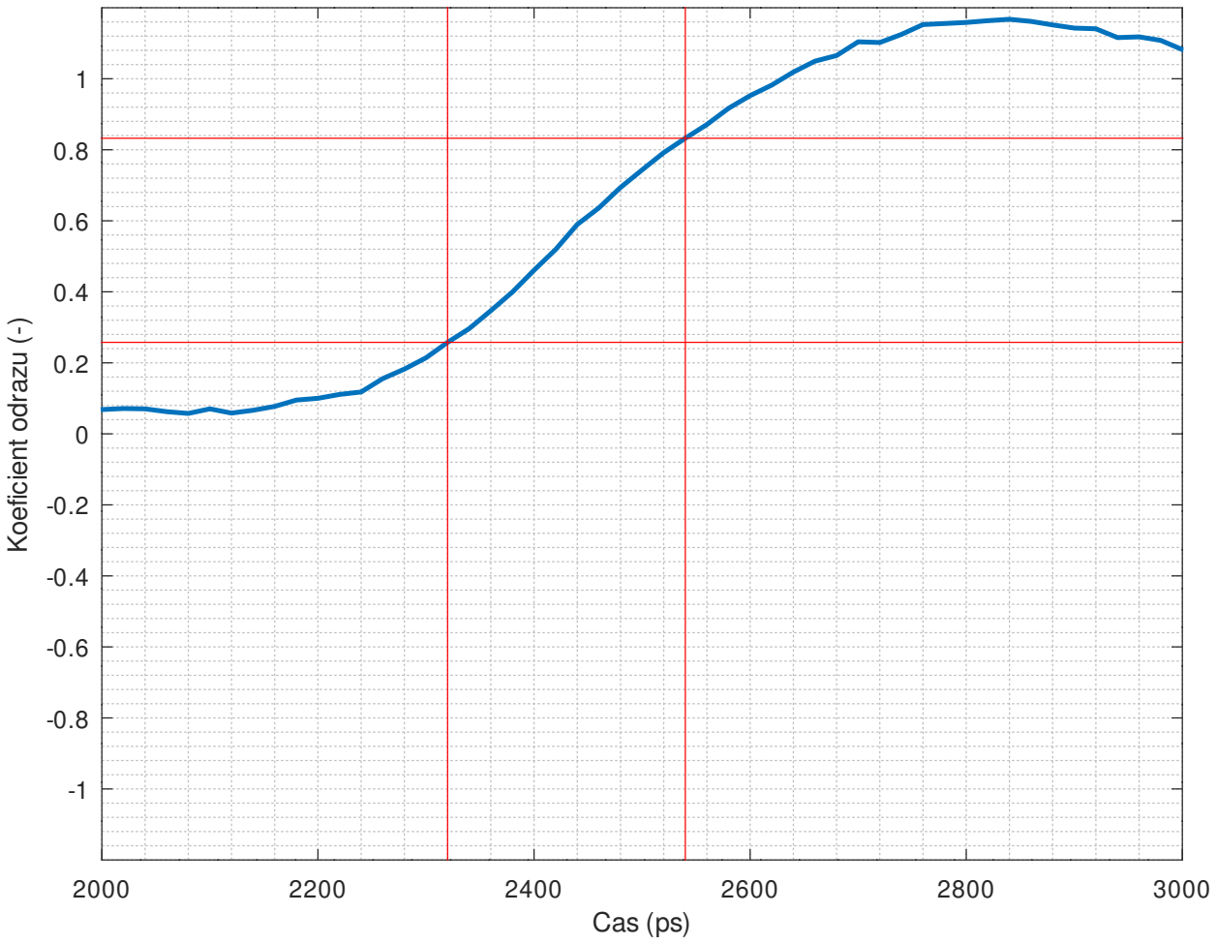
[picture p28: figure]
Cas (ps); Koeficient odrazu (-)

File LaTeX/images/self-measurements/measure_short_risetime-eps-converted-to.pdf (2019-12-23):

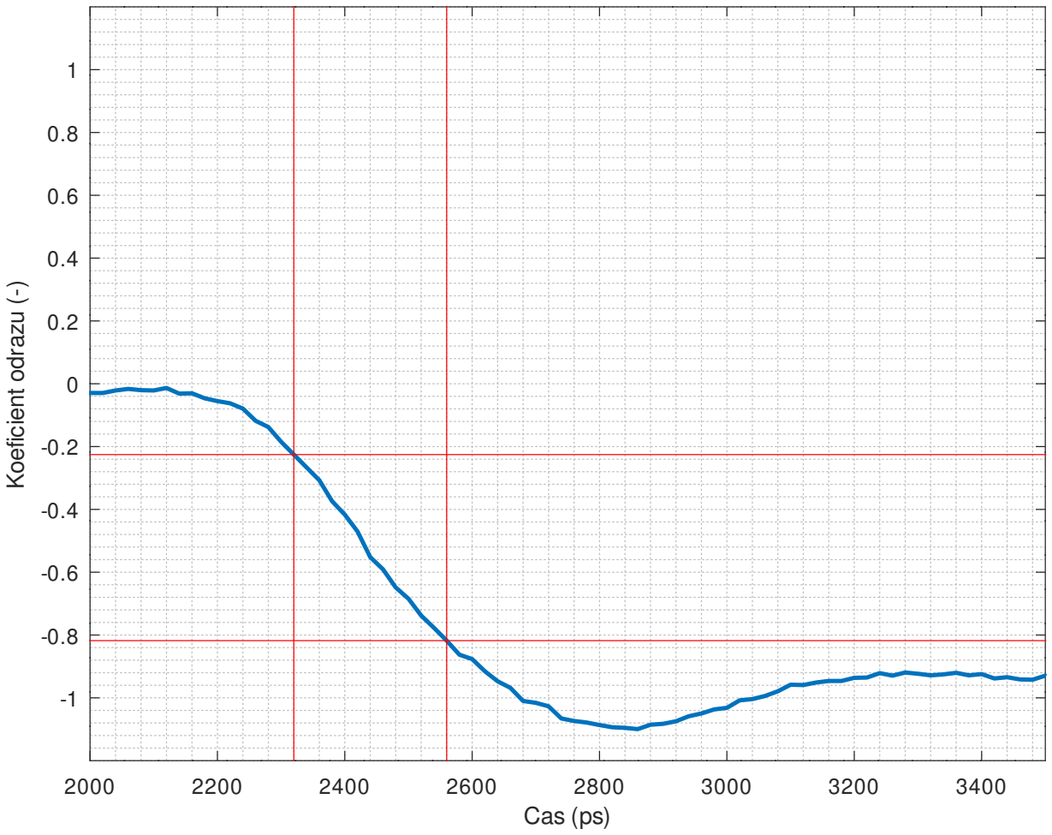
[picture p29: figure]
Cas (ps); Koeficient odrazu (-)

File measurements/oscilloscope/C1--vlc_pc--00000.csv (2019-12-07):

LECROYWR640Zi | 55774 | Waveform
Segments | 1 | SegmentSize | 42
Segment | TrigTime | TimeSinceSegment1
#1 | 18-Nov-2019 09:25:59 | 0
Time | Ampl
-1.05e-09 | -0.200122
-1e-09 | -0.200013
-9.5e-10 | -0.200095
-9e-10 | -0.200218
-8.5e-10 | -0.200245
-8e-10 | -0.200095
-7.5e-10 | -0.199972
-7e-10 | -0.200095
-6.5e-10 | -0.200313
-6e-10 | -0.200245
-5.5e-10 | -0.199904
-5e-10 | -0.199959
-4.5e-10 | -0.200218
-4e-10 | -0.199809
-3.5e-10 | -0.199522
-3e-10 | -0.200218
-2.5e-10 | -0.199577
-2e-10 | -0.197054
-1.5e-10 | -0.198609
-1e-10 | -0.201554
-5e-11 | -0.17874
4.1488e-24 | -0.109859
5e-11 | -0.0269603
1e-10 | 0.0149052
1.5e-10 | 0.00973679
2e-10 | -0.0033956
2.5e-10 | -0.00441838
3e-10 | -0.00230465
3.5e-10 | -0.00196372
4e-10 | -0.00175917
4.5e-10 | -0.00257739
5e-10 | -0.00338197
5.5e-10 | -0.00249556
6e-10 | -0.000845492
6.5e-10 | 0.000804581
7e-10 | 0.00196372
7.5e-10 | 0.00175917
8e-10 | 0.000613663
8.5e-10 | -0.000381835
9e-10 | -0.000545478
9.5e-10 | -0.000150007
1e-09 | 4.09109e-05

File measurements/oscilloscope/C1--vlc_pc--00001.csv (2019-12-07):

LECROYWR640Zi | 55774 | Waveform
Segments | 1 | SegmentSize | 42
Segment | TrigTime | TimeSinceSegment1
#1 | 18-Nov-2019 09:31:22 | 0
Time | Ampl
-1.05e-09 | -0.200751
-1e-09 | -0.20071
-9.5e-10 | -0.200737
-9e-10 | -0.200805
-8.5e-10 | -0.200805
-8e-10 | -0.200724
-7.5e-10 | -0.200696
-7e-10 | -0.200751
-6.5e-10 | -0.200792
-6e-10 | -0.200765
-5.5e-10 | -0.200656
-5e-10 | -0.200601
-4.5e-10 | -0.20071
-4e-10 | -0.200519
-3.5e-10 | -0.200274
-3e-10 | -0.200737
-2.5e-10 | -0.200042
-2e-10 | -0.197821
-1.5e-10 | -0.19992
-1e-10 | -0.202195
-5e-11 | -0.176386
8.4011e-25 | -0.104872
5e-11 | -0.0235745
1e-10 | 0.0136132
1.5e-10 | 0.00543712
2e-10 | -0.00780819
2.5e-10 | -0.00795809
3e-10 | -0.00494655
3.5e-10 | -0.00389728
4e-10 | -0.00318869
4.5e-10 | -0.0038564
5e-10 | -0.00482391
5.5e-10 | -0.00376101
6e-10 | -0.00166248
6.5e-10 | 0.000122642
7e-10 | 0.0014717
7.5e-10 | 0.00152621
8e-10 | 0.000190776
8.5e-10 | -0.00118554
9e-10 | -0.00158072
9.5e-10 | -0.000981134
1e-09 | -0.000531448

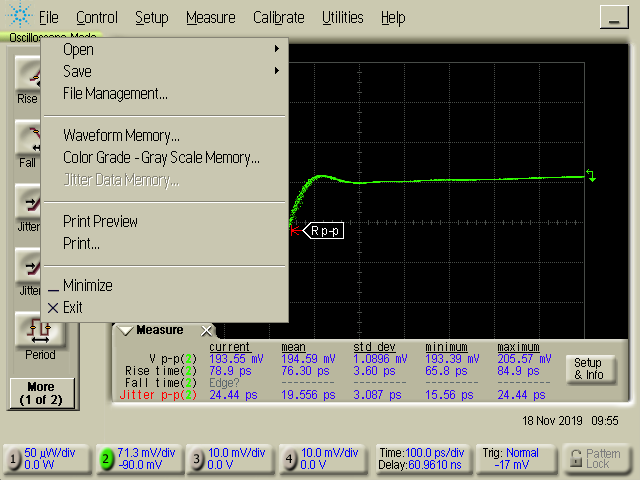
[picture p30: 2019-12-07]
measurements/oscilloscope/screen4.bmp

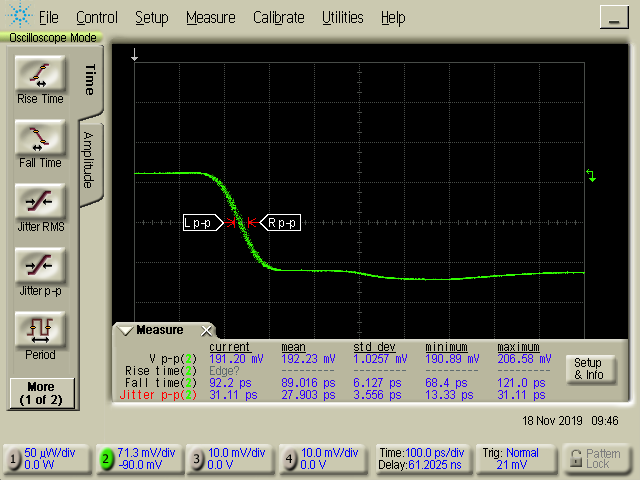
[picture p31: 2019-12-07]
measurements/oscilloscope/screen1.bmp

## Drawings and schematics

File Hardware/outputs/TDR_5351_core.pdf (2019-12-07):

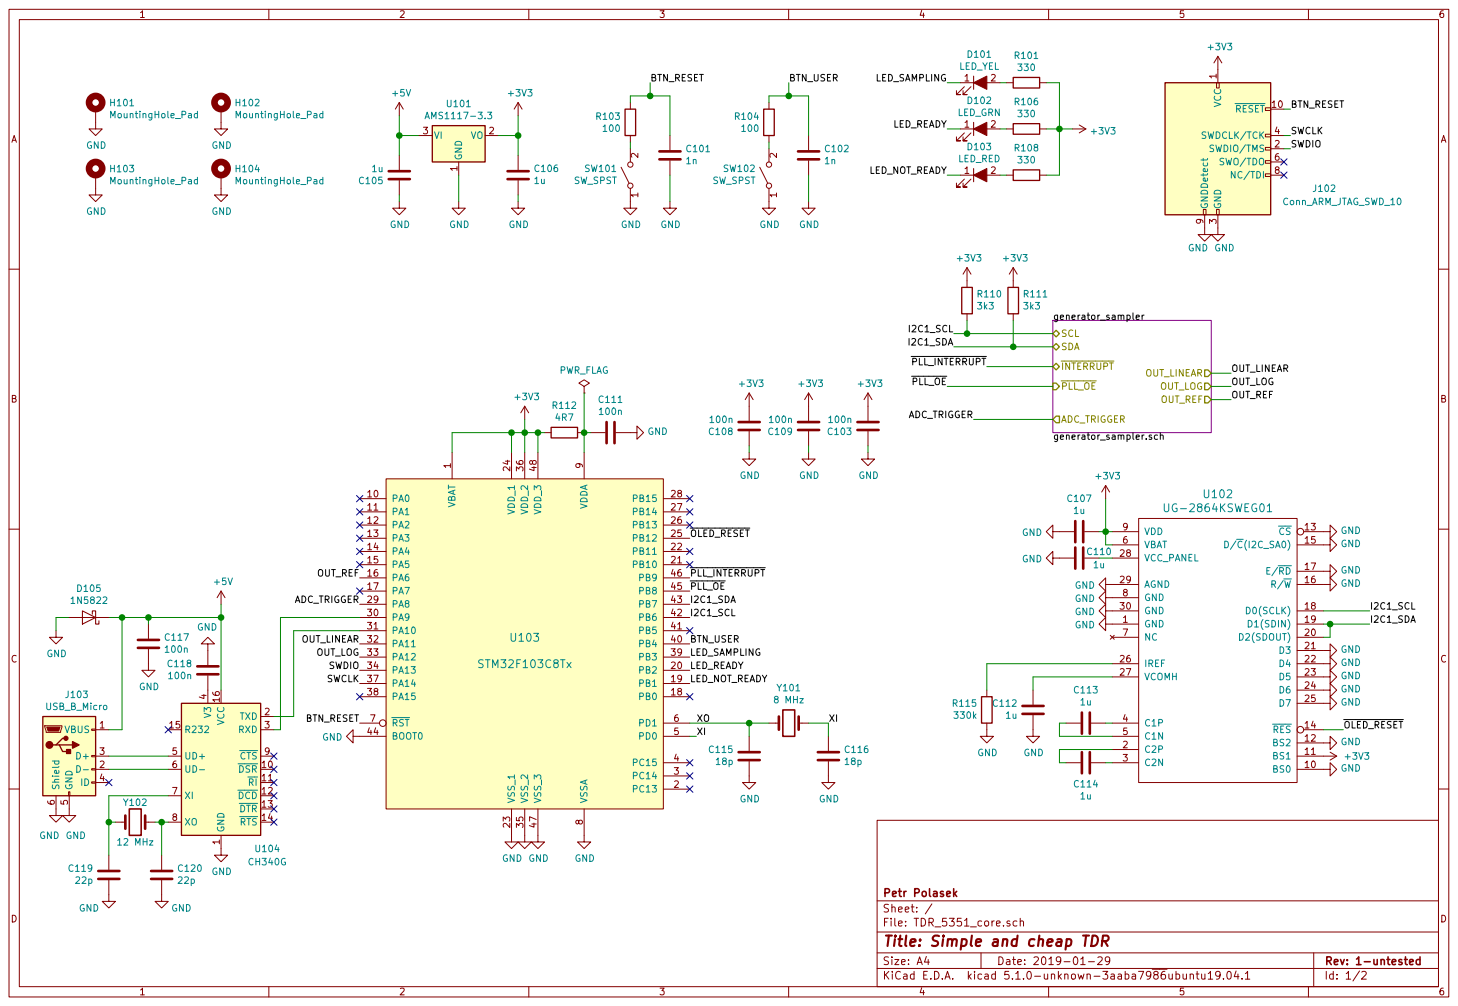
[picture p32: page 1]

1 RESET 10 SWDIO/TMS 2 GND

3 SWDCLK/TCK 4 SWO/TDO 6 NC/TDI 8 GNDDetect 9

1 DSR 10 RI 11 DCD 12 DTR 13 RTS 14 R232 15 VCC 16 TXD 2 RXD 3 V3

4 UD+ 5 UD- 6 XI 7 XO 8 CTS 9 U104 CH340G

File: TDR_5351_core.sch Sheet: / Petr Polasek

Id: 1/2 Title: Simple and cheap TDR

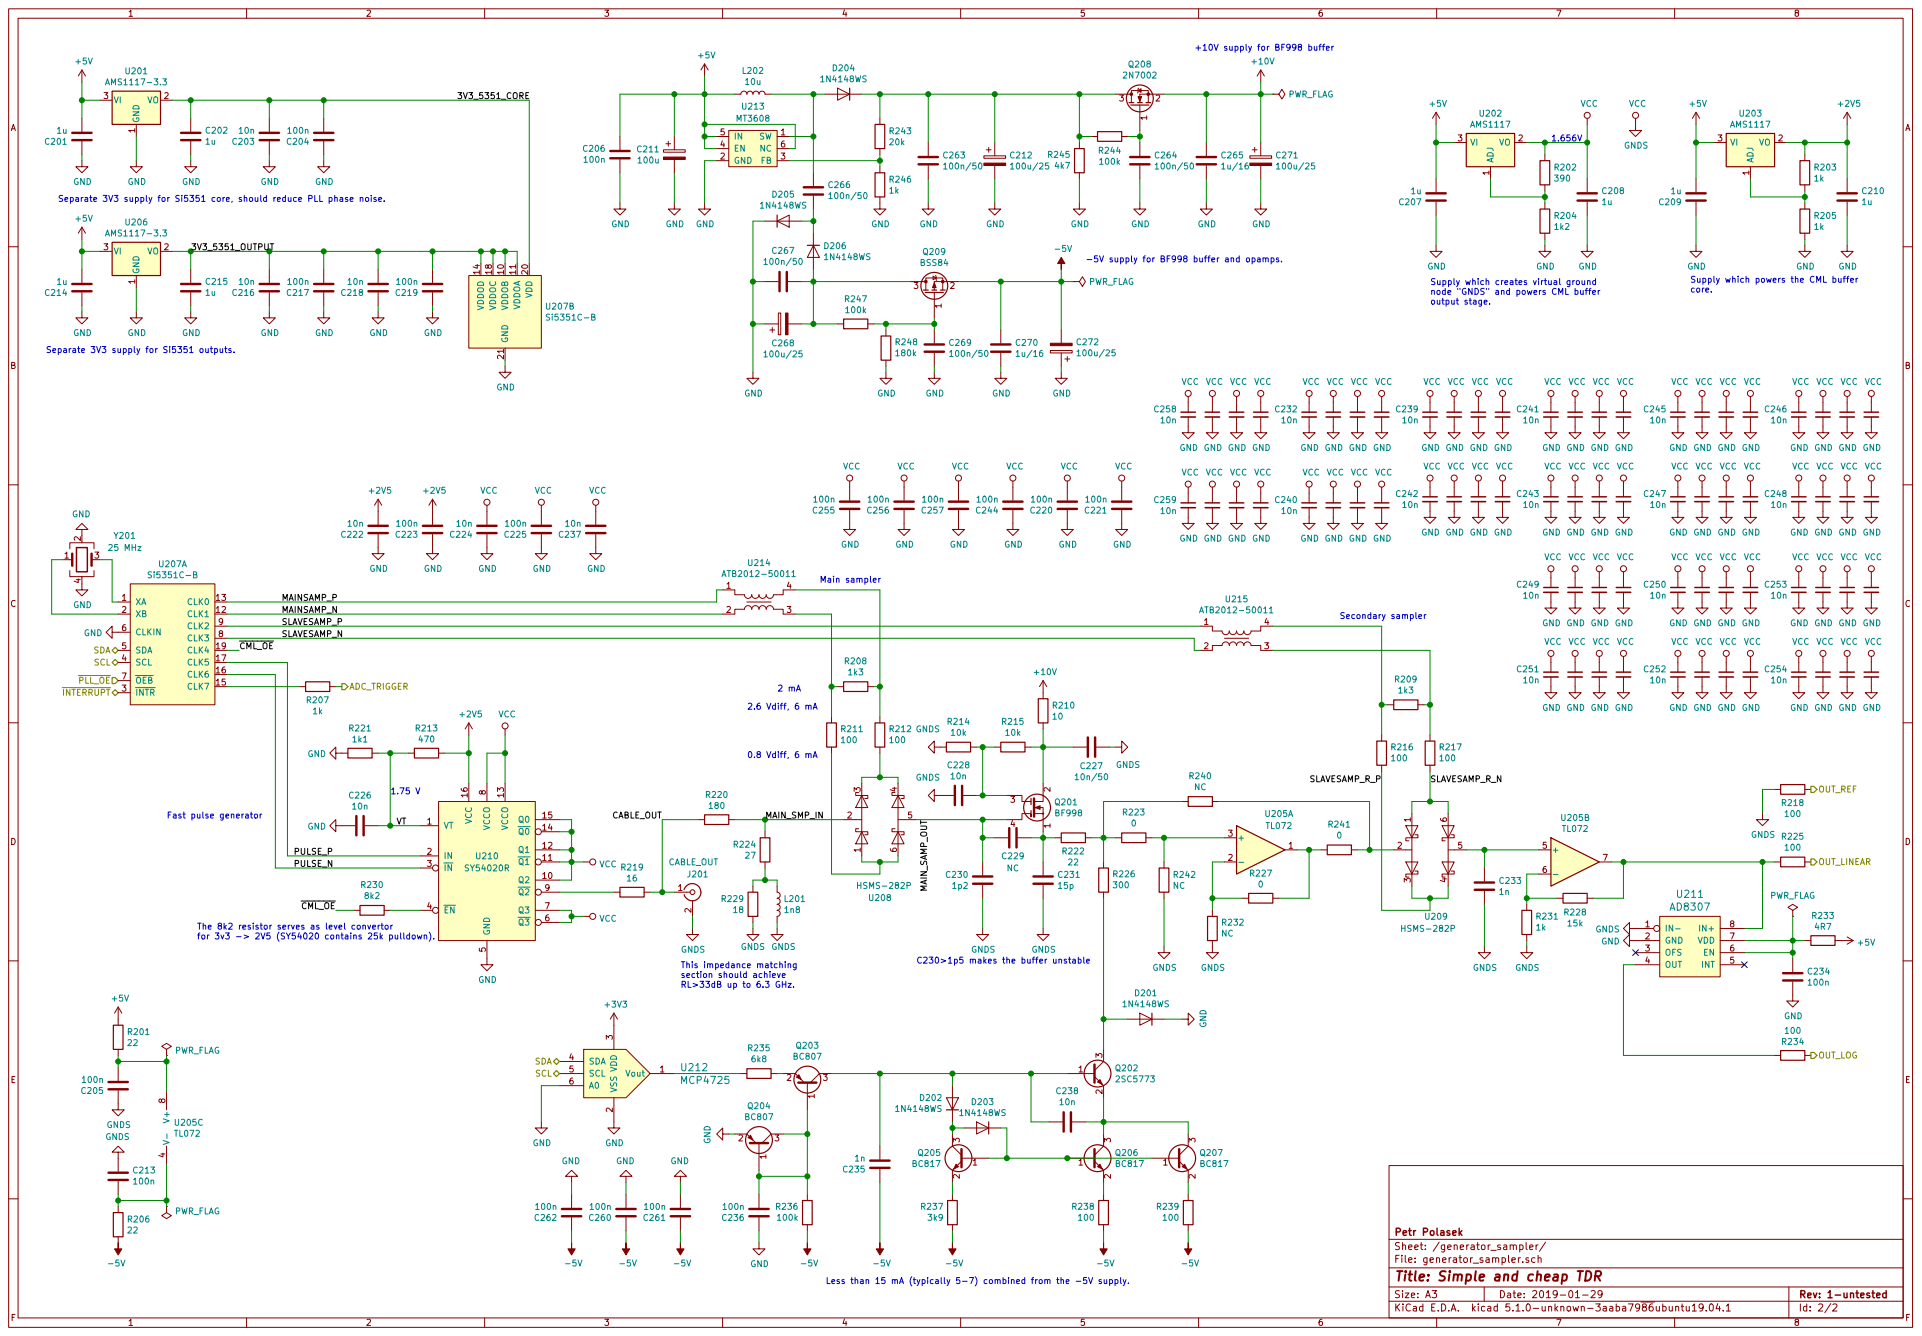
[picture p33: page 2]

1 VO 2 VI 3 U201 AMS1117-3.3 Main sampler

-5V supply for BF998 buffer and opamps. 3V3_5351_CORE

Supply which creates virtual ground

Separate 3V3 supply for Si5351 outputs.

10n VCC VCC VCC VCC GND GND GND GND

8k2 The 8k2 resistor serves as level convertor

C230>1p5 makes the buffer unstable This impedance matching
section should achieve RL>33dB up to 6.3 GHz.

File: generator_sampler.sch
Id: 2/2 Title: Simple and cheap TDR

Less than 15 mA (typically 5-7) combined from the -5V supply.

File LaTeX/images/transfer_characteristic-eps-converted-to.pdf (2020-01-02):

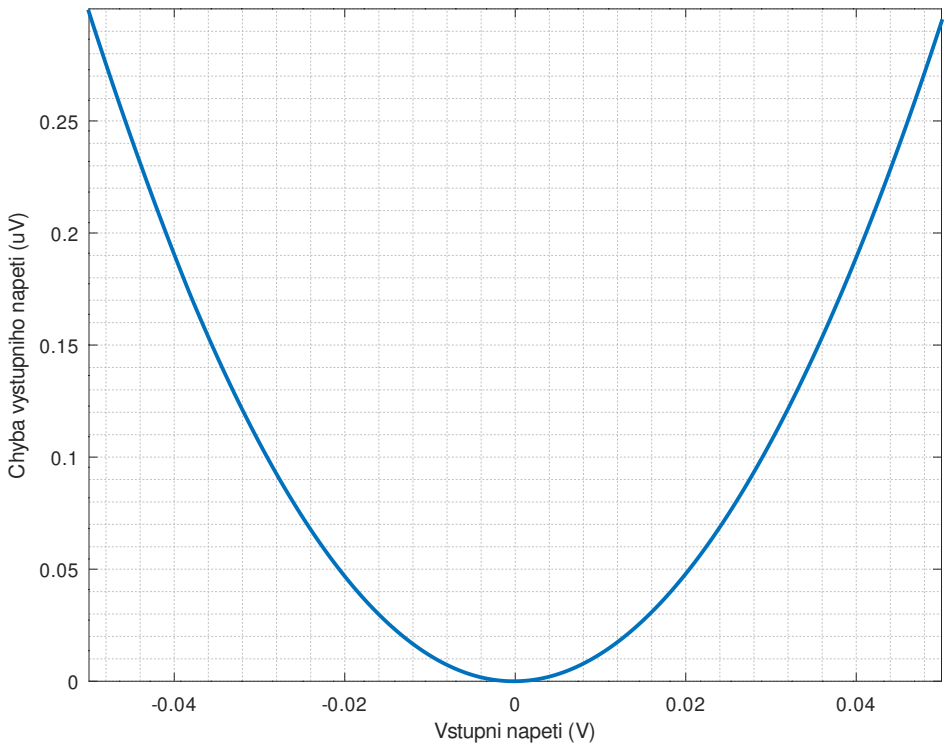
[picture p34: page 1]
Vstupni napeti (V)

Chyba vystupniho napeti (uV)

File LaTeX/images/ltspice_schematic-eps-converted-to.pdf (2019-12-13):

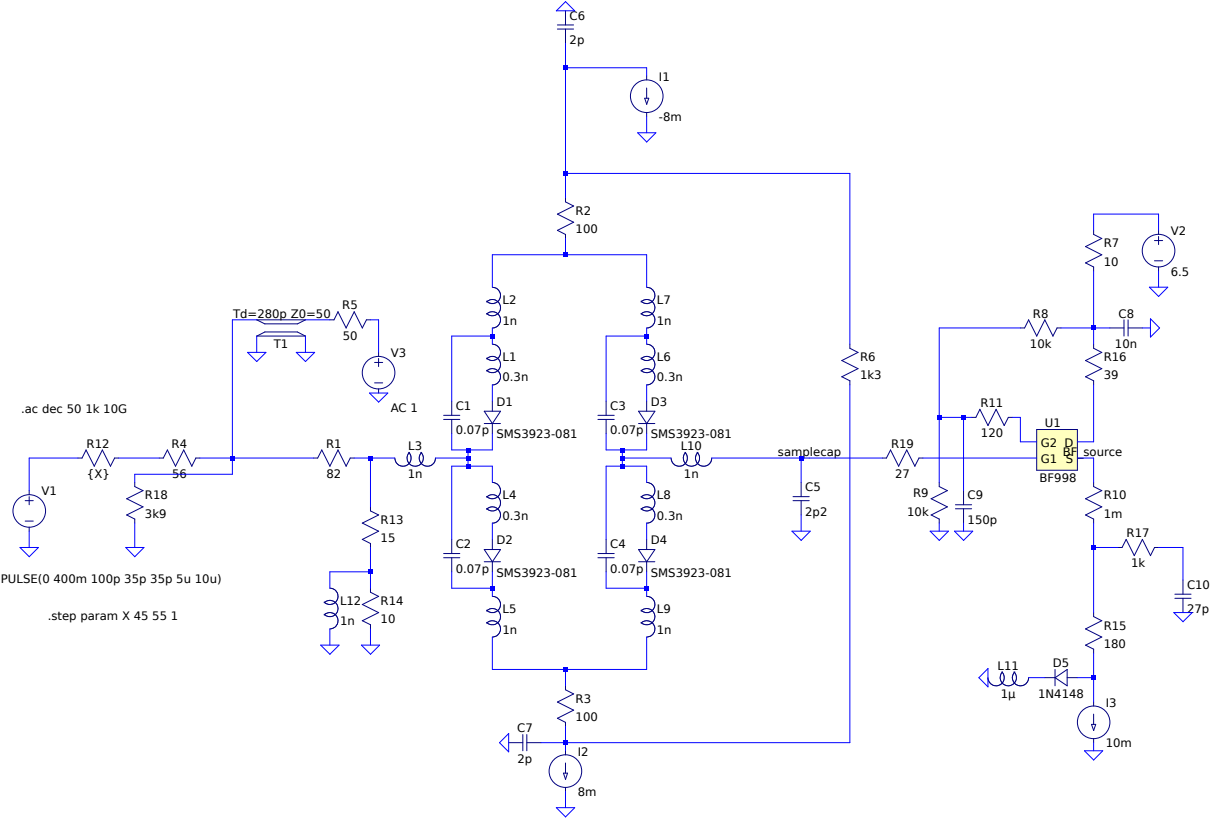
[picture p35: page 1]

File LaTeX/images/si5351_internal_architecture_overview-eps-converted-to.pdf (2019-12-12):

## Si5351C (20-QFN)

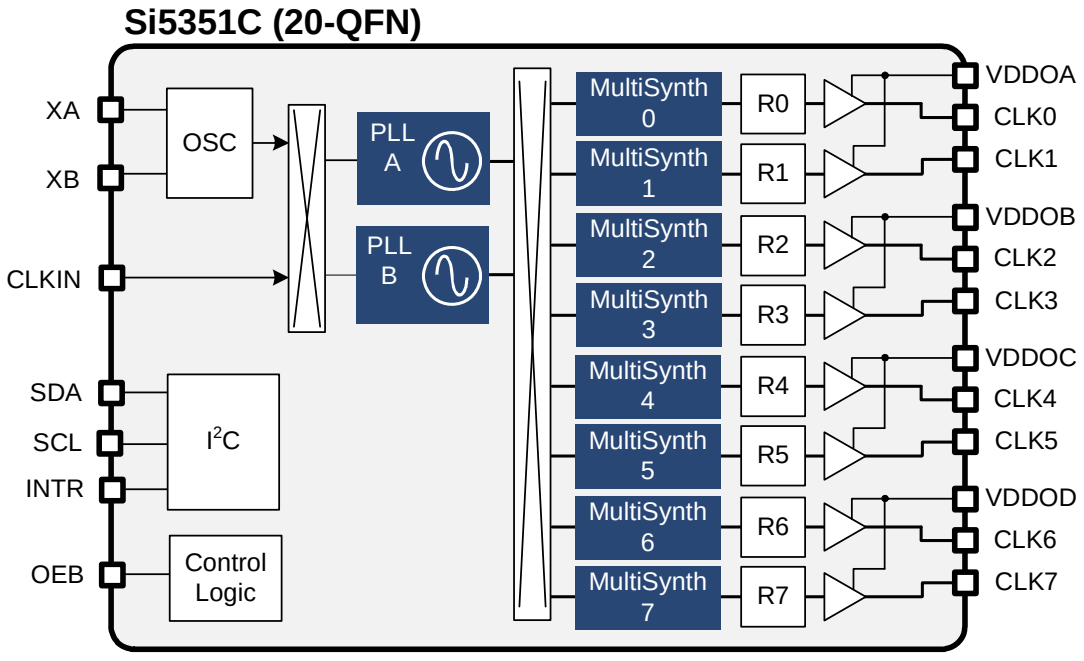
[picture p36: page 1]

MultiSynth 3 | R3

MultiSynth 4 | R4

MultiSynth 5 | R5

MultiSynth 6 | R6

MultiSynth 7 | R7

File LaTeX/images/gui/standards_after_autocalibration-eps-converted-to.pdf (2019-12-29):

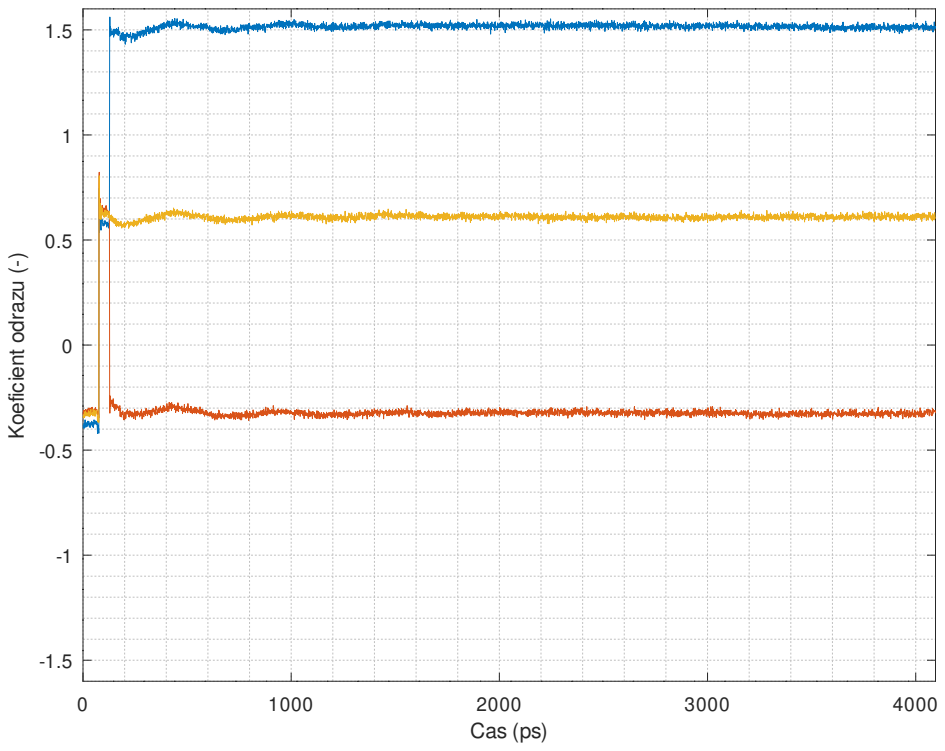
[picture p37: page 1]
Cas (ps); Koeficient odrazu (-)

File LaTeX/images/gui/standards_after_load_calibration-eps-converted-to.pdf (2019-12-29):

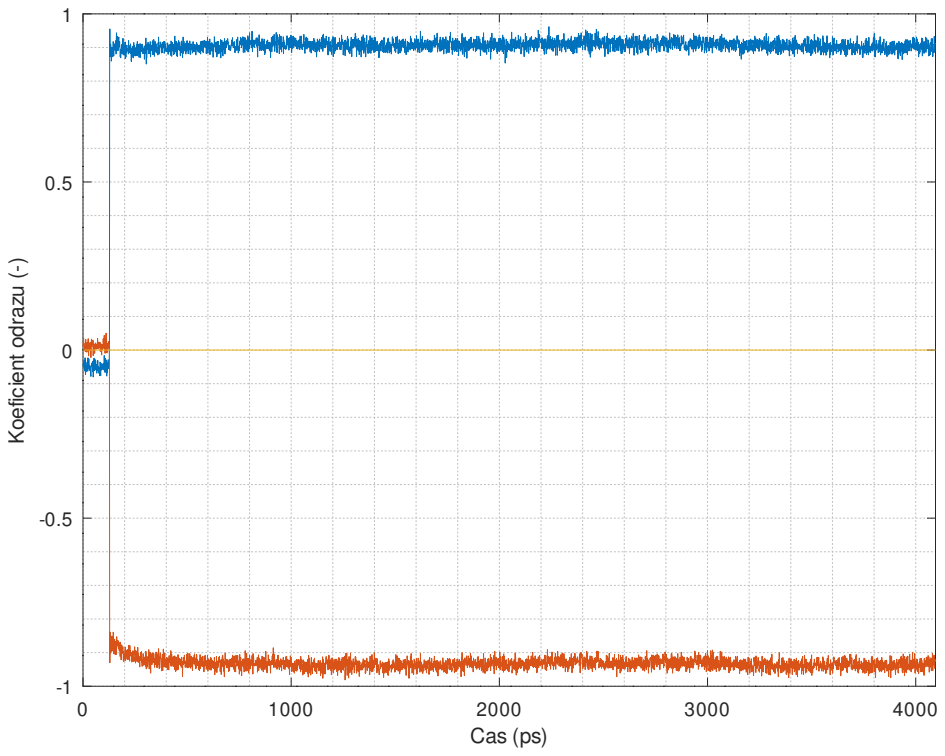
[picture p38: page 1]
Cas (ps); Koeficient odrazu (-)

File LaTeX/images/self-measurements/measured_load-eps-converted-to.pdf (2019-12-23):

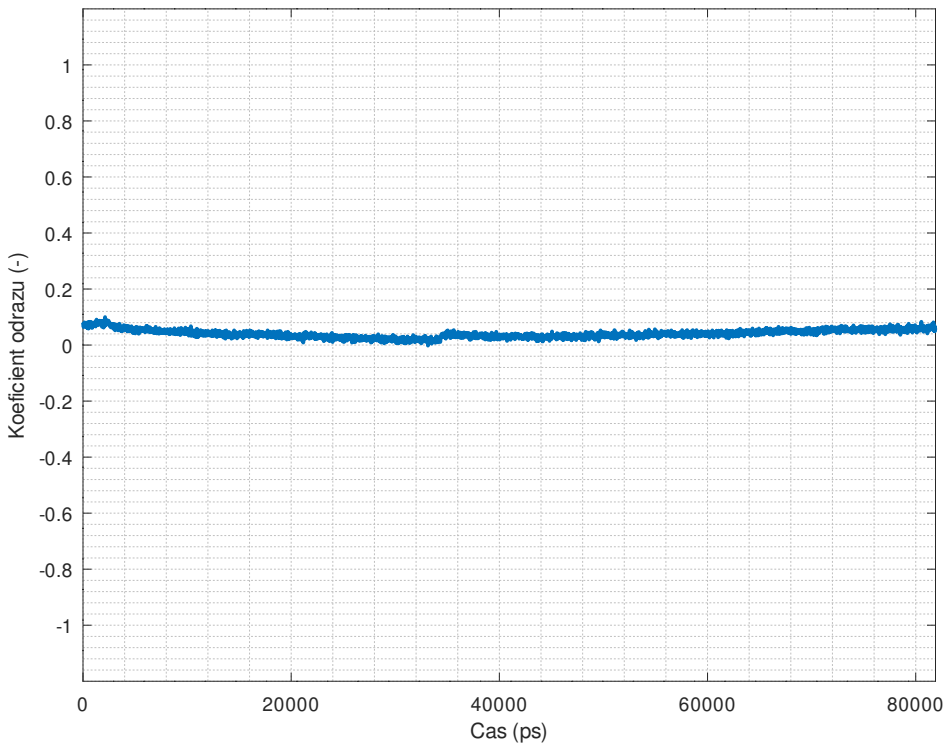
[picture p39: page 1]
Cas (ps); Koeficient odrazu (-)

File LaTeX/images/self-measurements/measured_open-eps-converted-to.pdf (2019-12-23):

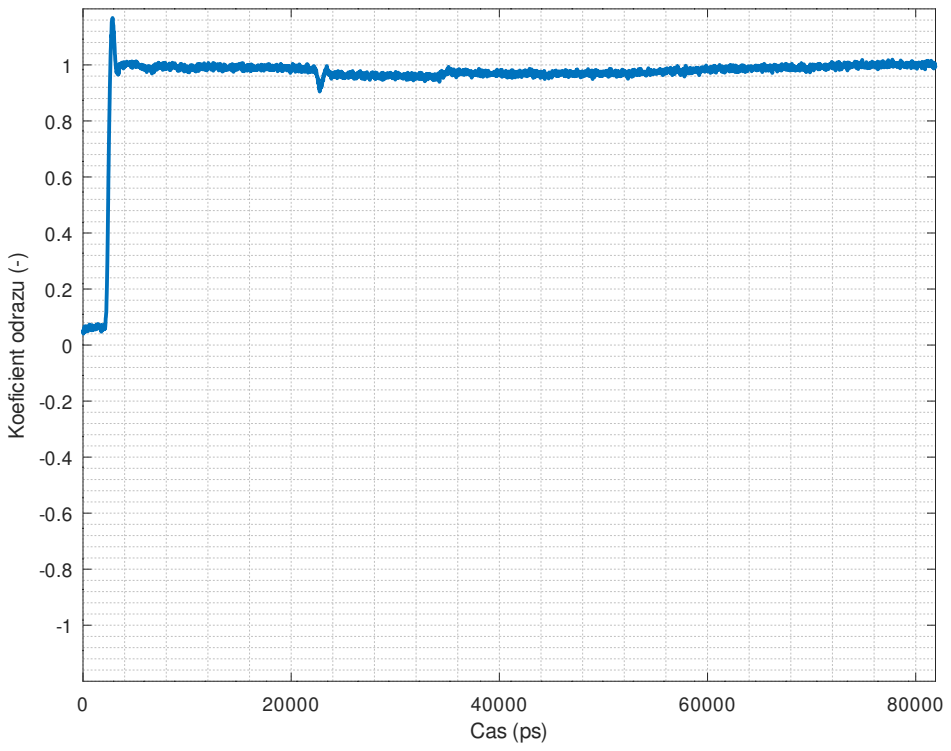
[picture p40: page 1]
Cas (ps); Koeficient odrazu (-)

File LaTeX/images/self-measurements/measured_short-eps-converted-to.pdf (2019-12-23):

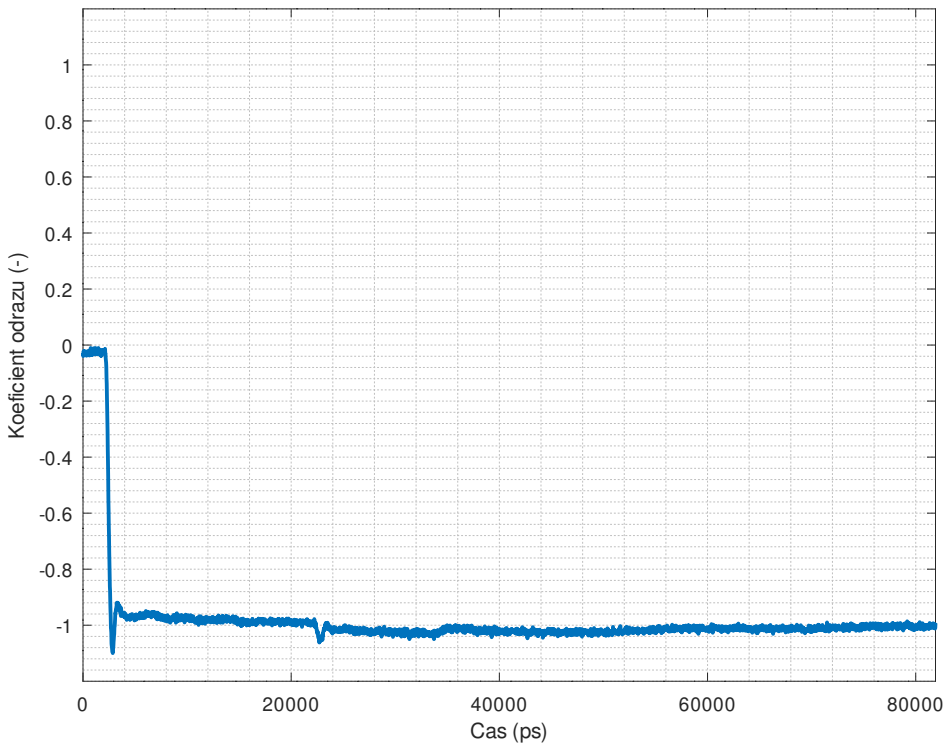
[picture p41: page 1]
Cas (ps); Koeficient odrazu (-)

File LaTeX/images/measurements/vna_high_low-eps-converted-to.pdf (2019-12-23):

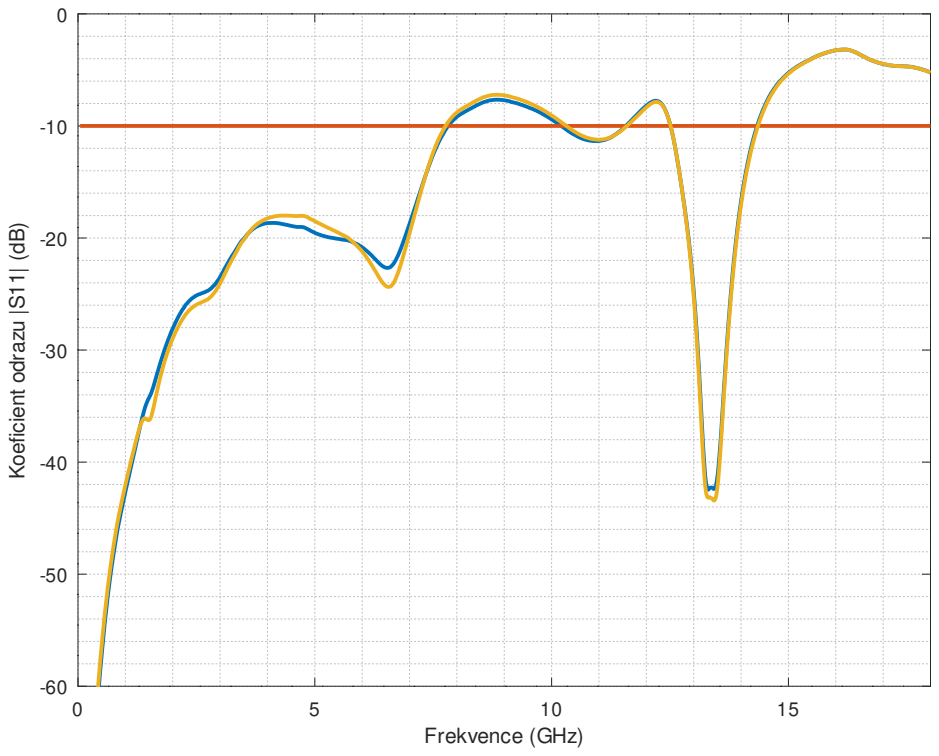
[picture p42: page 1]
Frekvence (GHz)

Koeficient odrazu |S11| (dB)

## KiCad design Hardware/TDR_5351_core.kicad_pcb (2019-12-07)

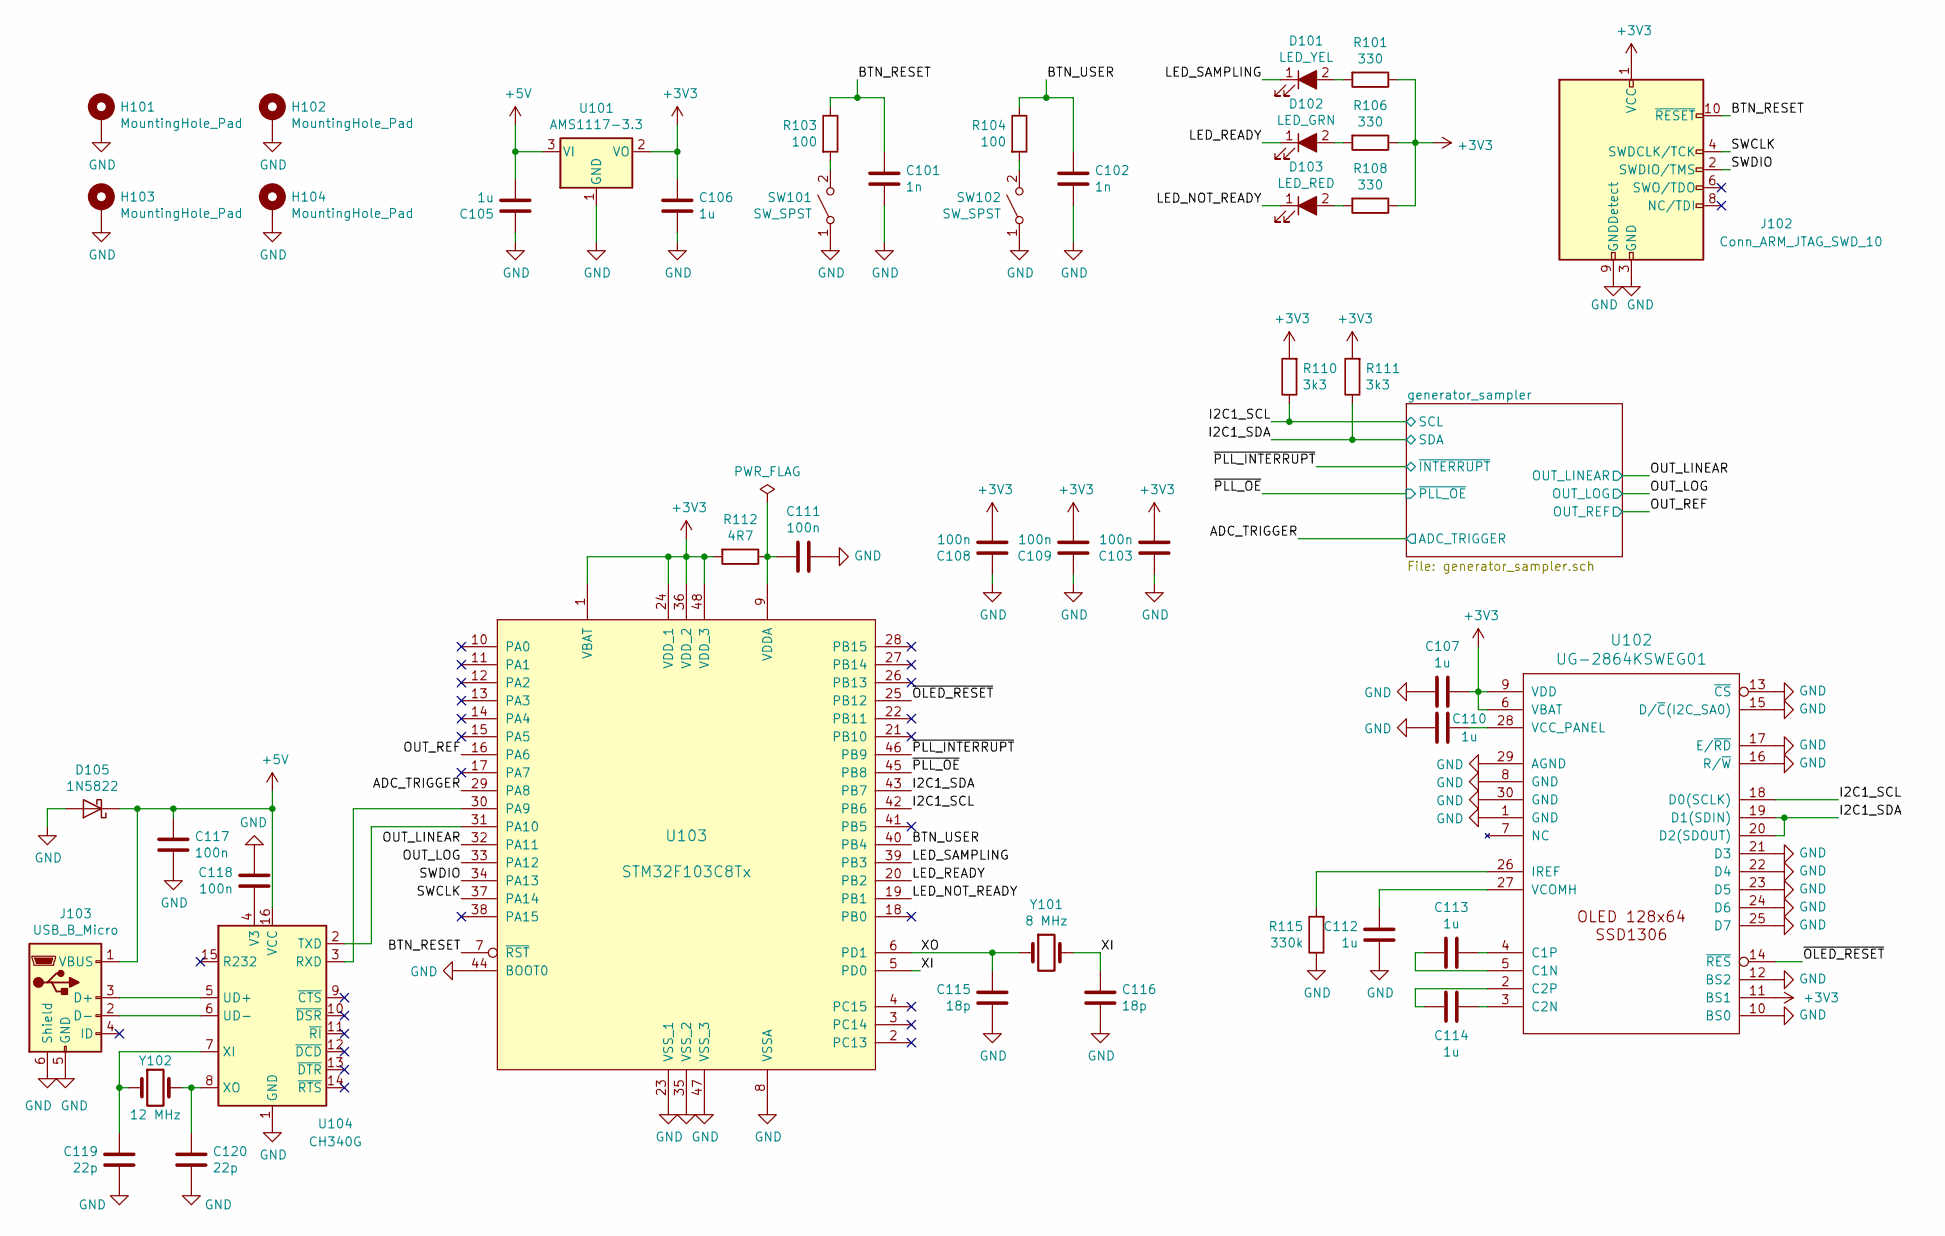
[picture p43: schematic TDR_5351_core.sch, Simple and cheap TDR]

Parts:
C101, C102: 1n; C_0603_1608Metric_Pad1.05x0.95mm_HandSolder
C103, C108, C109, C111, C117, C118: 100n; C_0603_1608Metric_Pad1.05x0.95mm_HandSolder
C105, C106, C107, C110, C112, C113, C114: 1u; C_0805_2012Metric_Pad1.15x1.40mm_HandSolder
C115, C116: 18p; C_0603_1608Metric_Pad1.05x0.95mm_HandSolder
C119, C120: 22p; C_0603_1608Metric_Pad1.05x0.95mm_HandSolder
D101: LED_YEL; LED_0603_1608Metric_Pad1.05x0.95mm_HandSolder
D102: LED_GRN; LED_0603_1608Metric_Pad1.05x0.95mm_HandSolder
D103: LED_RED; LED_0603_1608Metric_Pad1.05x0.95mm_HandSolder
D105: 1N5822; D_DO-201AD_P15.24mm_Horizontal
H101, H102, H103, H104: MountingHole_Pad; MountingHole_3.2mm_M3_Pad_Via
J102: Conn_ARM_JTAG_SWD_10; PinHeader_2x05_P1.27mm_Vertical_SMD
J103: USB_B_Micro; USB_Micro-B_Wuerth_629105150521
R101, R106, R108: 330; R_0603_1608Metric_Pad1.05x0.95mm_HandSolder
R103, R104: 100; R_0603_1608Metric_Pad1.05x0.95mm_HandSolder
R110, R111: 3k3; R_0603_1608Metric_Pad1.05x0.95mm_HandSolder
R112: 4R7; R_0603_1608Metric_Pad1.05x0.95mm_HandSolder
R115: 330k; R_0603_1608Metric_Pad1.05x0.95mm_HandSolder
SW101, SW102: SW_SPST; SW_SPST_TL3342
U101: AMS1117-3.3; SOT-223-3_TabPin2
U102: UG-2864KSWEG01
U103: STM32F103C8Tx; TQFP-48_7x7mm_P0.5mm
U104: CH340G; SOIC-16_3.9x9.9mm_P1.27mm
Y101: 8 MHz; Crystal_SMD_HC49-SD
Y102: 12 MHz; Crystal_SMD_HC49-SD

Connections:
+3V3: C103.2, C106.2, C107.1, C108.2, C109.2, J102.1 (VCC), R101.1, R106.1, R108.1, R110.2, R111.2, R112.2, U101.2 (VO), U102.6 (VBAT), U102.9 (VDD), U102.11 (BS1), U103.1 (VBAT), U103.24 (VDD_1), U103.36 (VDD_2), U103.48 (VDD_3); also elsewhere on the board
+5V: C105.2, C117.2, D105.1 (K), J103.1 (VBUS), U101.3 (VI), U104.16 (VCC); also elsewhere on the board
/ADC_TRIGGER: U103.29 (PA8); also elsewhere on the board
/BTN_RESET: C101.2, J102.10 (~RESET~), R103.1, U103.7 (~RST)
/BTN_USER: C102.2, R104.1, U103.40 (PB4)
/I2C1_SCL: R110.1, U102.18 (D0(SCLK)), U103.42 (PB6); also elsewhere on the board
/I2C1_SDA: R111.1, U102.19 (D1(SDIN)), U102.20 (D2(SDOUT)), U103.43 (PB7); also elsewhere on the board
/LED_NOT_READY: D103.1 (K), U103.19 (PB1)
/LED_READY: D102.1 (K), U103.20 (PB2)
/LED_SAMPLING: D101.1 (K), U103.39 (PB3)
/OUT_LINEAR: U103.32 (PA11); also elsewhere on the board
/OUT_LOG: U103.33 (PA12); also elsewhere on the board
/OUT_REF: U103.16 (PA6); also elsewhere on the board
/SWCLK: J102.4 (SWDCLK/TCK), U103.37 (PA14)
/SWDIO: J102.2 (SWDIO/TMS), U103.34 (PA13)
/XI: C116.2, U103.5 (PD0), Y101.2
/XO: C115.2, U103.6 (PD1), Y101.1
/~OLED_RESET: U102.14 (~RES), U103.25 (PB12)
/~PLL_INTERRUPT: U103.46 (PB9); also elsewhere on the board
/~PLL_OE: U103.45 (PB8); also elsewhere on the board
GND: C101.1, C102.1, C103.1, C105.1, C106.1, C107.2, C108.1, C109.1, C110.2, C111.1, C112.1, C115.1, C116.1, C117.1, C118.2, C119.1, C120.1, D105.2 (A), H101.1, H102.1, H103.1, H104.1, J102.3 (GND), J102.5 (GND), J102.9 (GNDDetect), J103.5 (GND), J103.6 (Shield), R115.1, SW101.1 (A), SW102.1 (A), U101.1 (GND), U102.1 (GND), U102.8 (GND), U102.10 (BS0), U102.12 (BS2), U102.13 (~CS), U102.15 (D/~C~(I2C_SA0)), U102.16 (R/~W), U102.17 (E/~RD), U102.21 (D3), U102.22 (D4), U102.23 (D5), U102.24 (D6), U102.25 (D7), U102.29 (AGND), U102.30 (GND), U103.8 (VSSA), U103.23 (VSS_1), U103.35 (VSS_2), U103.44 (BOOT0), U103.47 (VSS_3), U104.1 (GND); also elsewhere on the board
unnamed: C110.1, U102.28 (VCC_PANEL)
unnamed: C111.2, R112.1, U103.9 (VDDA)
unnamed: C112.2, U102.27 (VCOMH)
unnamed: C113.1, U102.4 (C1P)
unnamed: C113.2, U102.5 (C1N)
unnamed: C114.1, U102.3 (C2N)
unnamed: C114.2, U102.2 (C2P)
unnamed: C118.1, U104.4 (V3)
unnamed: C119.2, U104.7 (XI), Y102.1
unnamed: C120.2, U104.8 (XO), Y102.2
unnamed: D101.2 (A), R101.2
unnamed: D102.2 (A), R106.2
unnamed: D103.2 (A), R108.2
unnamed: J103.2 (D-), U104.6 (UD-)
unnamed: J103.3 (D+), U104.5 (UD+)
unnamed: R103.2, SW101.2 (B)
unnamed: R104.2, SW102.2 (B)
unnamed: R115.2, U102.26 (IREF)
unnamed: U103.30 (PA9), U104.3 (RXD)
unnamed: U103.31 (PA10), U104.2 (TXD)

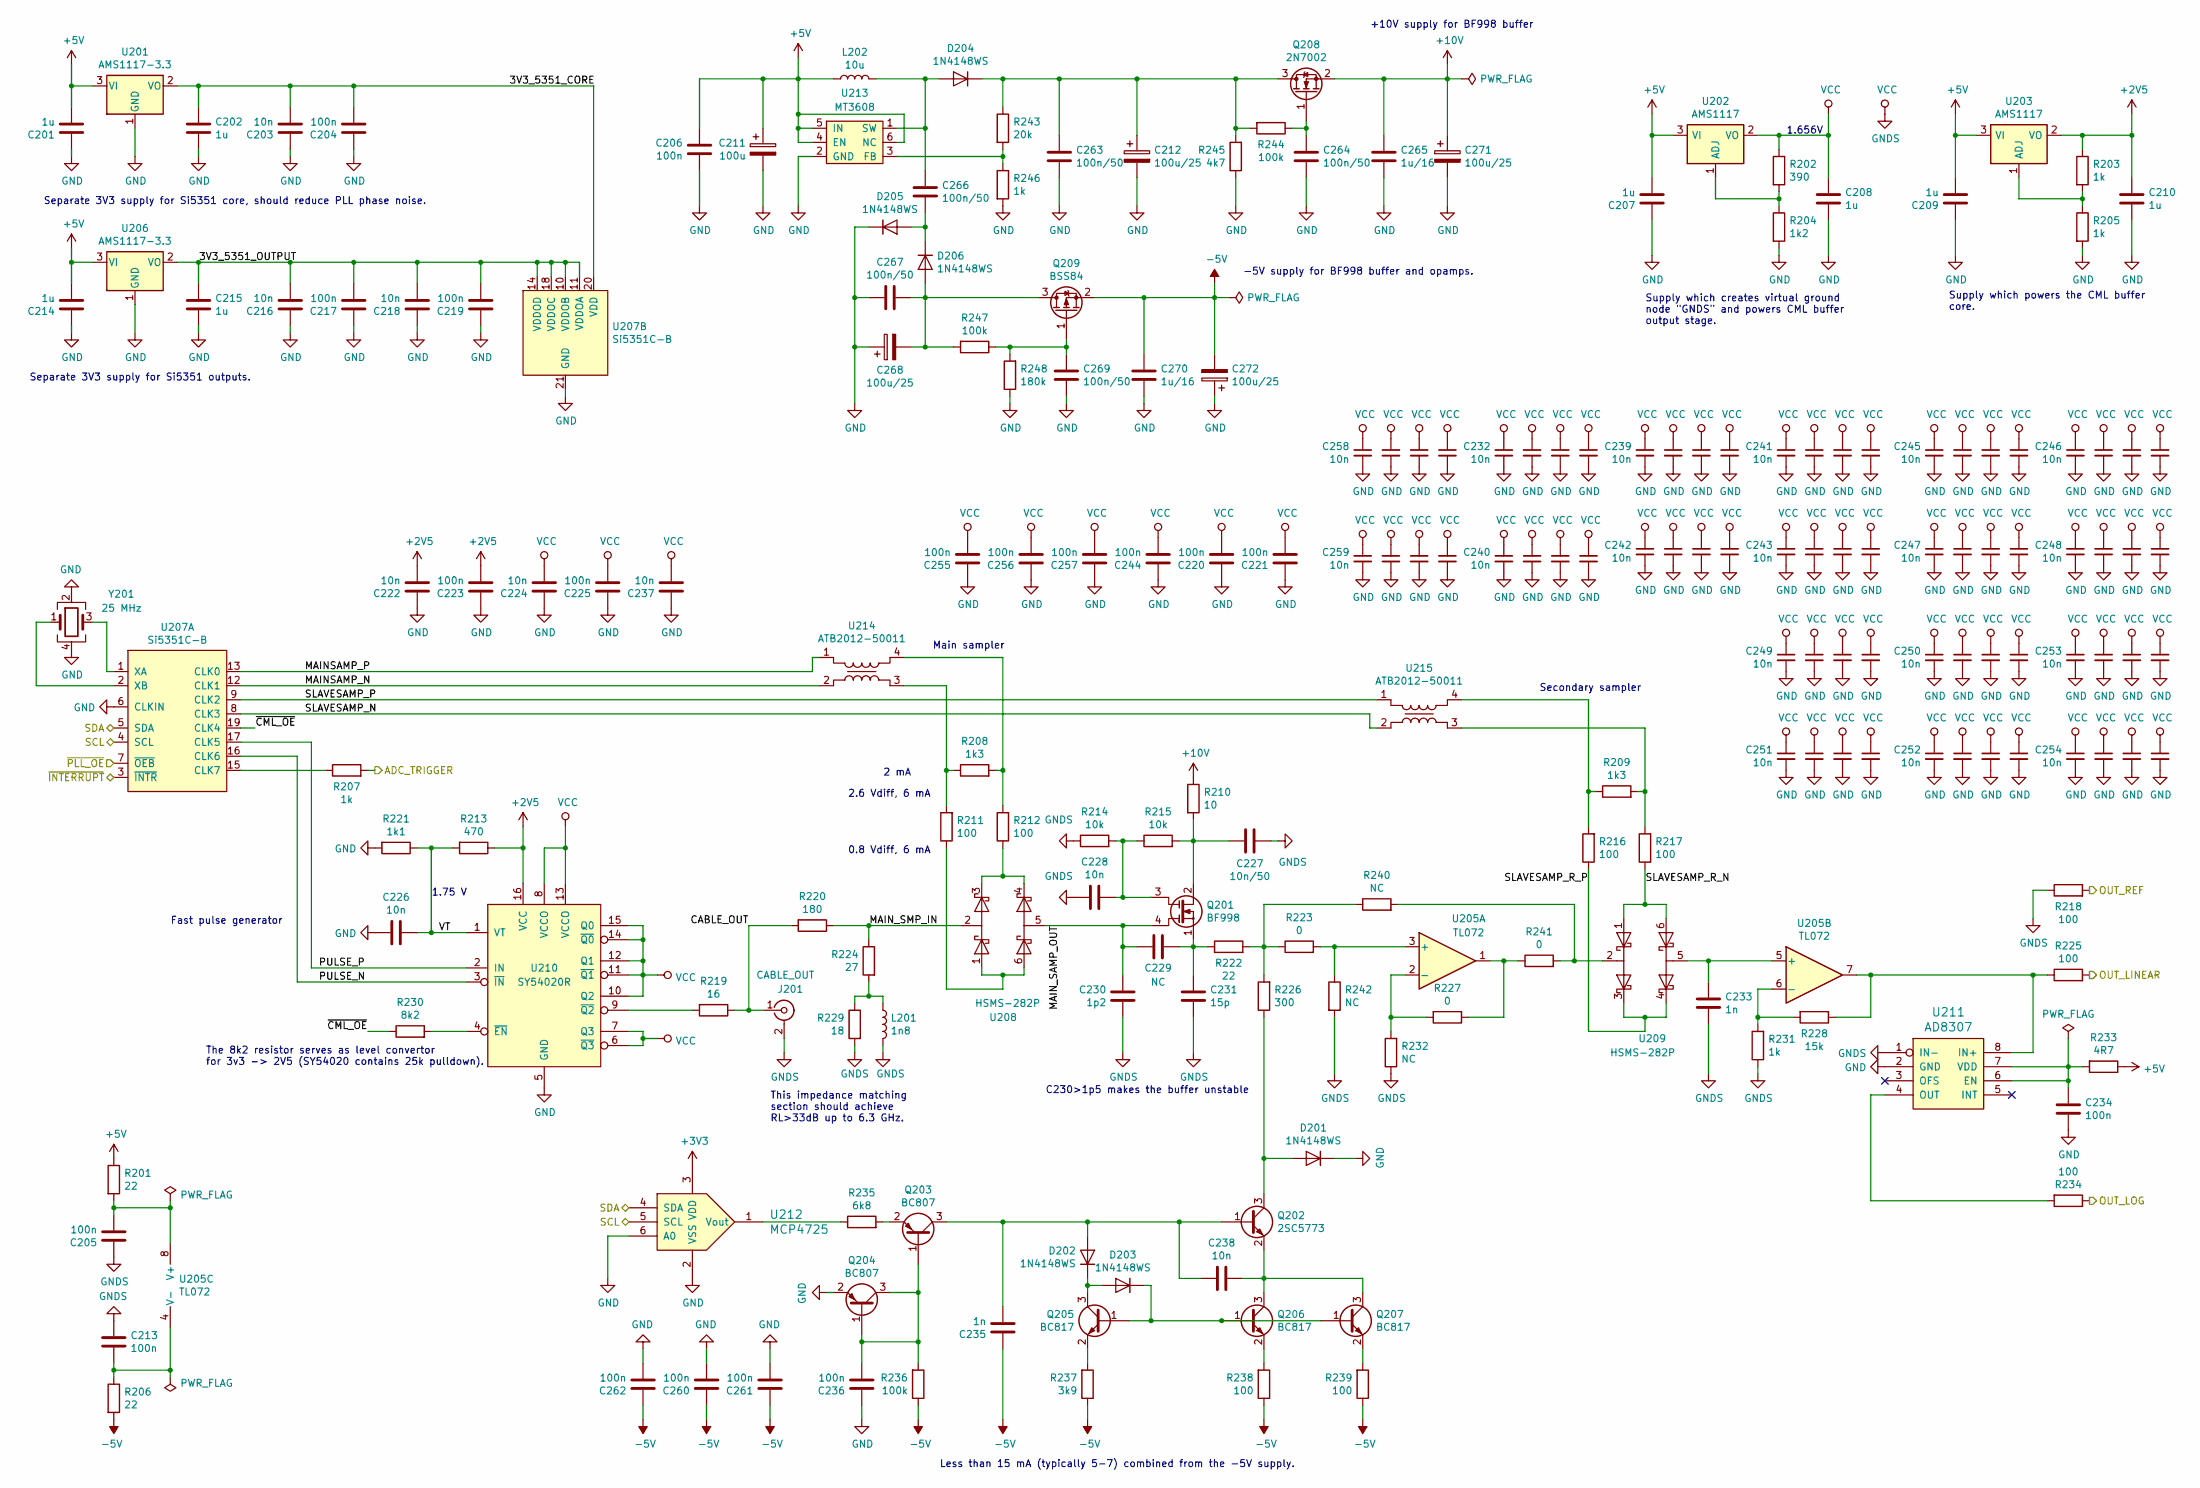
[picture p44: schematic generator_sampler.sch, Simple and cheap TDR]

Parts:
C201, C202, C207, C208, C209, C210, C214, C215: 1u; C_0805_2012Metric_Pad1.15x1.40mm_HandSolder
C203, C216, C218, C222, C224, C226, C228, C237: 10n; C_0402_1005Metric
C204, C217, C219, C223, C225: 100n; C_0402_1005Metric
C205, C206, C213, C220, C221, C234, C236, C244, C255, C256, C257, C260, C261, C262: 100n; C_0603_1608Metric_Pad1.05x0.95mm_HandSolder
C211: 100u; CP_Elec_6.3x7.7
C212, C268, C271, C272: 100u/25; CP_Elec_6.3x7.7
C227: 10n/50; C_0402_1005Metric
C229: NC; C_0402_1005Metric
C230: 1p2; C_0402_1005Metric
C231: 15p; C_0402_1005Metric
C232, C239, C240, C241, C242, C243, C245, C246, C247, C248, C249, C250, C251, C252, C253, C254, C258, C259: 10n; C_Array_4x0612
C233, C235: 1n; C_0603_1608Metric_Pad1.05x0.95mm_HandSolder
C238: 10n; C_0603_1608Metric_Pad1.05x0.95mm_HandSolder
C263, C264, C266, C267, C269: 100n/50; C_0603_1608Metric_Pad1.05x0.95mm_HandSolder
C265, C270: 1u/16; C_0603_1608Metric_Pad1.05x0.95mm_HandSolder
D201, D202, D203, D204, D205, D206: 1N4148WS; D_SOD-323
J201: CABLE_OUT; Molex_SMA_Jack_Edge_Mount_Chinese
L201: 1n8; L_0402_1005Metric
L202: 10u; L_Coilcraft_LPS5030
Q201: BF998; SOT-143
Q202: 2SC5773; SC-59_Handsoldering
Q203, Q204: BC807; SOT-23_Handsoldering
Q205, Q206, Q207: BC817; SOT-23_Handsoldering
Q208: 2N7002; SOT-23_Handsoldering
Q209: BSS84; SOT-23_Handsoldering
R201, R206: 22; R_0603_1608Metric_Pad1.05x0.95mm_HandSolder
R202: 390; R_0805_2012Metric_Pad1.15x1.40mm_HandSolder
R203, R205, R246: 1k; R_0805_2012Metric_Pad1.15x1.40mm_HandSolder
R204: 1k2; R_0805_2012Metric_Pad1.15x1.40mm_HandSolder
R207: 1k; R_0603_1608Metric_Pad1.05x0.95mm_HandSolder
R208, R209: 1k3; R_0402_1005Metric
R210: 10; R_0402_1005Metric
R211, R212, R216, R217: 100; R_0402_1005Metric
R213: 470; R_0402_1005Metric
R214, R215: 10k; R_0402_1005Metric
R218, R225, R234, R238, R239: 100; R_0603_1608Metric_Pad1.05x0.95mm_HandSolder
R219: 16; R_0402_1005Metric
R220: 180; R_0402_1005Metric
R221: 1k1; R_0402_1005Metric
R222: 22; R_0402_1005Metric
R223, R227, R241: 0; R_0402_1005Metric
R224: 27; R_0402_1005Metric
R226: 300; R_0603_1608Metric_Pad1.05x0.95mm_HandSolder
R228: 15k; R_0402_1005Metric
R229: 18; R_0402_1005Metric
R230: 8k2; R_0402_1005Metric
R231: 1k; R_0402_1005Metric
R232, R240, R242: NC; R_0402_1005Metric
R233: 4R7; R_0603_1608Metric_Pad1.05x0.95mm_HandSolder
R235: 6k8; R_0603_1608Metric_Pad1.05x0.95mm_HandSolder
R236, R244, R247: 100k; R_0603_1608Metric_Pad1.05x0.95mm_HandSolder
R237: 3k9; R_0603_1608Metric_Pad1.05x0.95mm_HandSolder
R243: 20k; R_0805_2012Metric_Pad1.15x1.40mm_HandSolder
R245: 4k7; R_1206_3216Metric_Pad1.42x1.75mm_HandSolder
R248: 180k; R_0603_1608Metric_Pad1.05x0.95mm_HandSolder
U201, U206: AMS1117-3.3; SOT-223-3_TabPin2
U202, U203: AMS1117; SOT-223-3_TabPin2
U205: TL072; SOIC-8_3.9x4.9mm_P1.27mm
U207: Si5351C-B; QFN-20-1EP_4x4mm_P0.5mm_EP2.6x2.6mm_ThermalVias
U208, U209: HSMS-282P; SOT-363_SC-70-6_Handsoldering
U210: SY54020R; QFN-16-1EP_3x3mm_P0.5mm_EP1.7x1.7mm_ThermalVias
U211: AD8307; SOIC-8_3.9x4.9mm_P1.27mm
U212: MCP4725; SOT-23-6_Handsoldering
U213: MT3608; TSOT-23-6_HandSoldering
U214, U215: ATB2012-50011; ATB2012
Y201: 25 MHz; Crystal_SMD_EuroQuartz_MT-4Pin_3.2x2.5mm_HandSoldering; Mouser 449-LFXTAL072604CUTT

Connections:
+2V5: C210.2, C222.2, C223.2, R203.1, R213.1, U203.2 (VO), U210.16 (VCC)
+3V3: U212.3 (VDD); also elsewhere on the board
+5V: C201.2, C206.2, C207.2, C209.2, C211.1, C214.2, L202.1, R201.1, R233.1, U201.3 (VI), U202.3 (VI), U203.3 (VI), U206.3 (VI), U213.4 (EN), U213.5 (IN), U213.6 (NC); also elsewhere on the board
+10V: C265.1, C271.1, Q208.2 (S), R210.1
-5V: C235.1, C260.1, C261.1, C262.1, C270.1, C272.2, Q209.2 (S), R206.2, R236.1, R237.1, R238.1, R239.1
/ADC_TRIGGER: R207.2; also elsewhere on the board
/I2C1_SCL: U207.4 (SCL), U212.5 (SCL); also elsewhere on the board
/I2C1_SDA: U207.5 (SDA), U212.4 (SDA); also elsewhere on the board
/OUT_LINEAR: R225.2; also elsewhere on the board
/OUT_LOG: R234.1; also elsewhere on the board
/OUT_REF: R218.2; also elsewhere on the board
/generator_sampler/3V3_5351_CORE: C202.2, C203.2, C204.2, U201.2 (VO), U207.20 (VDD)
/generator_sampler/3V3_5351_OUTPUT: C215.2, C216.2, C217.2, C218.2, C219.2, U206.2 (VO), U207.10 (VDDOB), U207.11 (VDDOA), U207.14 (VDDOD), U207.18 (VDDOC)
/generator_sampler/CABLE_OUT: J201.1 (In), R219.1, R220.2
/generator_sampler/MAINSAMP_N: U207.12 (CLK1), U214.2
/generator_sampler/MAINSAMP_P: U207.13 (CLK0), U214.1
/generator_sampler/MAIN_SAMP_OUT: C229.2, C230.1, Q201.4 (G2), U208.5
/generator_sampler/MAIN_SMP_IN: R220.1, R224.1, U208.2
/generator_sampler/PULSE_N: U207.16 (CLK6), U210.3 (~IN)
/generator_sampler/PULSE_P: U207.17 (CLK5), U210.2 (IN)
/generator_sampler/SLAVESAMP_N: U207.8 (CLK3), U215.2
/generator_sampler/SLAVESAMP_P: U207.9 (CLK2), U215.1
/generator_sampler/SLAVESAMP_R_N: R217.1, U209.1, U209.6
/generator_sampler/SLAVESAMP_R_P: R216.1, U209.3, U209.4
/generator_sampler/VT: C226.1, R213.2, R221.1, U210.1 (VT)
/generator_sampler/~CML_OE: R230.1, U207.19 (CLK4)
/~PLL_INTERRUPT: U207.3 (~INTR); also elsewhere on the board
/~PLL_OE: U207.7 (~OEB); also elsewhere on the board
GND: C201.1, C202.1, C203.1, C204.1, C206.1, C207.1, C208.1, C209.1, C210.1, C211.2, C212.2, C214.1, C215.1, C216.1, C217.1, C218.1, C219.1, C220.1, C221.1, C222.1, C223.1, C224.1, C225.1, C226.2, C232.5, C232.6, C232.7, C232.8, C234.2, C236.1, C237.1, C239.5, C239.6, C239.7, C239.8, C240.5, C240.6, C240.7, C240.8, C241.5, C241.6, C241.7, C241.8, C242.5, C242.6, C242.7, C242.8, C243.5, C243.6, C243.7, C243.8, C244.1, C245.5, C245.6, C245.7, C245.8, C246.5, C246.6, C246.7, C246.8, C247.5, C247.6, C247.7, C247.8, C248.5, C248.6, C248.7, C248.8, C249.5, C249.6, C249.7, C249.8, C250.5, C250.6, C250.7, C250.8, C251.5, C251.6, C251.7, C251.8, C252.5, C252.6, C252.7, C252.8, C253.5, C253.6, C253.7, C253.8, C254.5, C254.6, C254.7, C254.8, C255.1, C256.1, C257.1, C258.5, C258.6, C258.7, C258.8, C259.5, C259.6, C259.7, C259.8, C260.2, C261.2, C262.2, C263.2, C264.2, C265.2, C267.1, C268.1, C269.2, C270.2, C271.2, C272.1, D201.1 (K), D205.1 (K), Q204.2 (E), R204.2, R205.2, R221.2, R245.1, R246.2, R248.1, U201.1 (GND), U206.1 (GND), U207.6 (CLKIN), U207.21 (GND), U210.5 (GND), U210.17 (GND), U211.2 (GND), U212.2 (VSS), U212.6 (A0), U213.2 (GND), Y201.2, Y201.4; also elsewhere on the board
GNDS: C205.1, C208.2, C213.2, C220.2, C221.2, C224.2, C225.2, C227.2, C228.2, C230.2, C231.2, C232.1, C232.2, C232.3, C232.4, C233.2, C237.2, C239.1, C239.2, C239.3, C239.4, C240.1, C240.2, C240.3, C240.4, C241.1, C241.2, C241.3, C241.4, C242.1, C242.2, C242.3, C242.4, C243.1, C243.2, C243.3, C243.4, C244.2, C245.1, C245.2, C245.3, C245.4, C246.1, C246.2, C246.3, C246.4, C247.1, C247.2, C247.3, C247.4, C248.1, C248.2, C248.3, C248.4, C249.1, C249.2, C249.3, C249.4, C250.1, C250.2, C250.3, C250.4, C251.1, C251.2, C251.3, C251.4, C252.1, C252.2, C252.3, C252.4, C253.1, C253.2, C253.3, C253.4, C254.1, C254.2, C254.3, C254.4, C255.2, C256.2, C257.2, C258.1, C258.2, C258.3, C258.4, C259.1, C259.2, C259.3, C259.4, J201.2 (Ext), L201.2, R202.1, R214.1, R218.1, R229.2, R231.1, R232.1, R242.2, U202.2 (VO), U210.6 (~Q3), U210.7 (Q3), U210.8 (VCCO), U210.10 (Q2), U210.11 (~Q1), U210.12 (Q1), U210.13 (VCCO), U210.14 (~Q0), U210.15 (Q0), U211.1 (IN-)
unnamed: C205.2, R201.2, U205.8 (V+)
unnamed: C212.1, C263.1, D204.1 (K), Q208.3 (D), R243.1, R244.2, R245.2
unnamed: C213.1, R206.1, U205.4 (V-)
unnamed: C227.1, Q201.2 (D), R210.2, R215.2
unnamed: C228.1, Q201.3 (G1), R214.2, R215.1
unnamed: C229.1, C231.1, Q201.1 (S), R222.1
unnamed: C233.1, U205.5 (+), U209.5
unnamed: C234.1, R233.2, U211.6 (EN), U211.7 (VDD)
unnamed: C235.2, C238.1, D202.2 (A), Q202.1, Q203.3 (C)
unnamed: C236.2, Q203.1 (B), Q204.1 (B), Q204.3 (C), R236.2
unnamed: C238.2, Q202.2, Q206.3 (C), Q207.3 (C)
unnamed: C264.1, Q208.1 (G), R244.1
unnamed: C266.1, D205.2 (A), D206.1 (K)
unnamed: C266.2, D204.2 (A), L202.2, U213.1 (SW)
unnamed: C267.2, C268.2, D206.2 (A), Q209.3 (D), R247.2
unnamed: C269.1, Q209.1 (G), R247.1, R248.2
unnamed: D201.2 (A), Q202.3, R226.1
unnamed: D202.1 (K), D203.2 (A), Q205.3 (C)
unnamed: D203.1 (K), Q205.1 (B), Q206.1 (B), Q207.1 (B)
unnamed: L201.1, R224.2, R229.1
unnamed: Q203.2 (E), R235.2
unnamed: Q205.2 (E), R237.2
unnamed: Q206.2 (E), R238.2
unnamed: Q207.2 (E), R239.2
unnamed: R202.2, R204.1, U202.1 (ADJ)
unnamed: R203.2, R205.1, U203.1 (ADJ)
unnamed: R207.1, U207.15 (CLK7)
unnamed: R208.1, R211.2, U214.3
unnamed: R208.2, R212.2, U214.4
unnamed: R209.1, R216.2, U215.4
unnamed: R209.2, R217.2, U215.3
unnamed: R211.1, U208.1, U208.6
unnamed: R212.1, U208.3, U208.4
unnamed: R219.2, U210.9 (~Q2)
unnamed: R222.2, R223.1, R226.2, R240.1
unnamed: R223.2, R242.1, U205.3 (+)
unnamed: R225.1, R228.1, U205.7, U211.8 (IN+)
unnamed: R227.1, R241.1, U205.1
unnamed: R227.2, R232.2, U205.2 (-)
unnamed: R228.2, R231.2, U205.6 (-)
unnamed: R230.2, U210.4 (~EN)
unnamed: R234.2, U211.4 (OUT)
unnamed: R235.1, U212.1 (Vout)
unnamed: R240.2, R241.2, U209.2
unnamed: R243.2, R246.1, U213.3 (FB)
unnamed: U207.1 (XA), Y201.3
unnamed: U207.2 (XB), Y201.1

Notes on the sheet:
1.75 V
The 8k2 resistor serves as level convertor for 3v3 -> 2V5 (SY54020 contains 25k pulldown).
0.8 Vdiff, 6 mA
2.6 Vdiff, 6 mA
2 mA
1.656V
Main sampler
Supply which creates virtual ground node "GNDS" and powers CML buffer output stage.
Supply which powers the CML buffer core.
Separate 3V3 supply for Si5351 core, should reduce PLL phase noise.
Separate 3V3 supply for Si5351 outputs.
Fast pulse generator
-5V supply for BF998 buffer and opamps.
Secondary sampler
Less than 15 mA (typically 5-7) combined from the -5V supply.
+10V supply for BF998 buffer
C230>1p5 makes the buffer unstable
This impedance matching section should achieve RL>33dB up to 6.3 GHz.

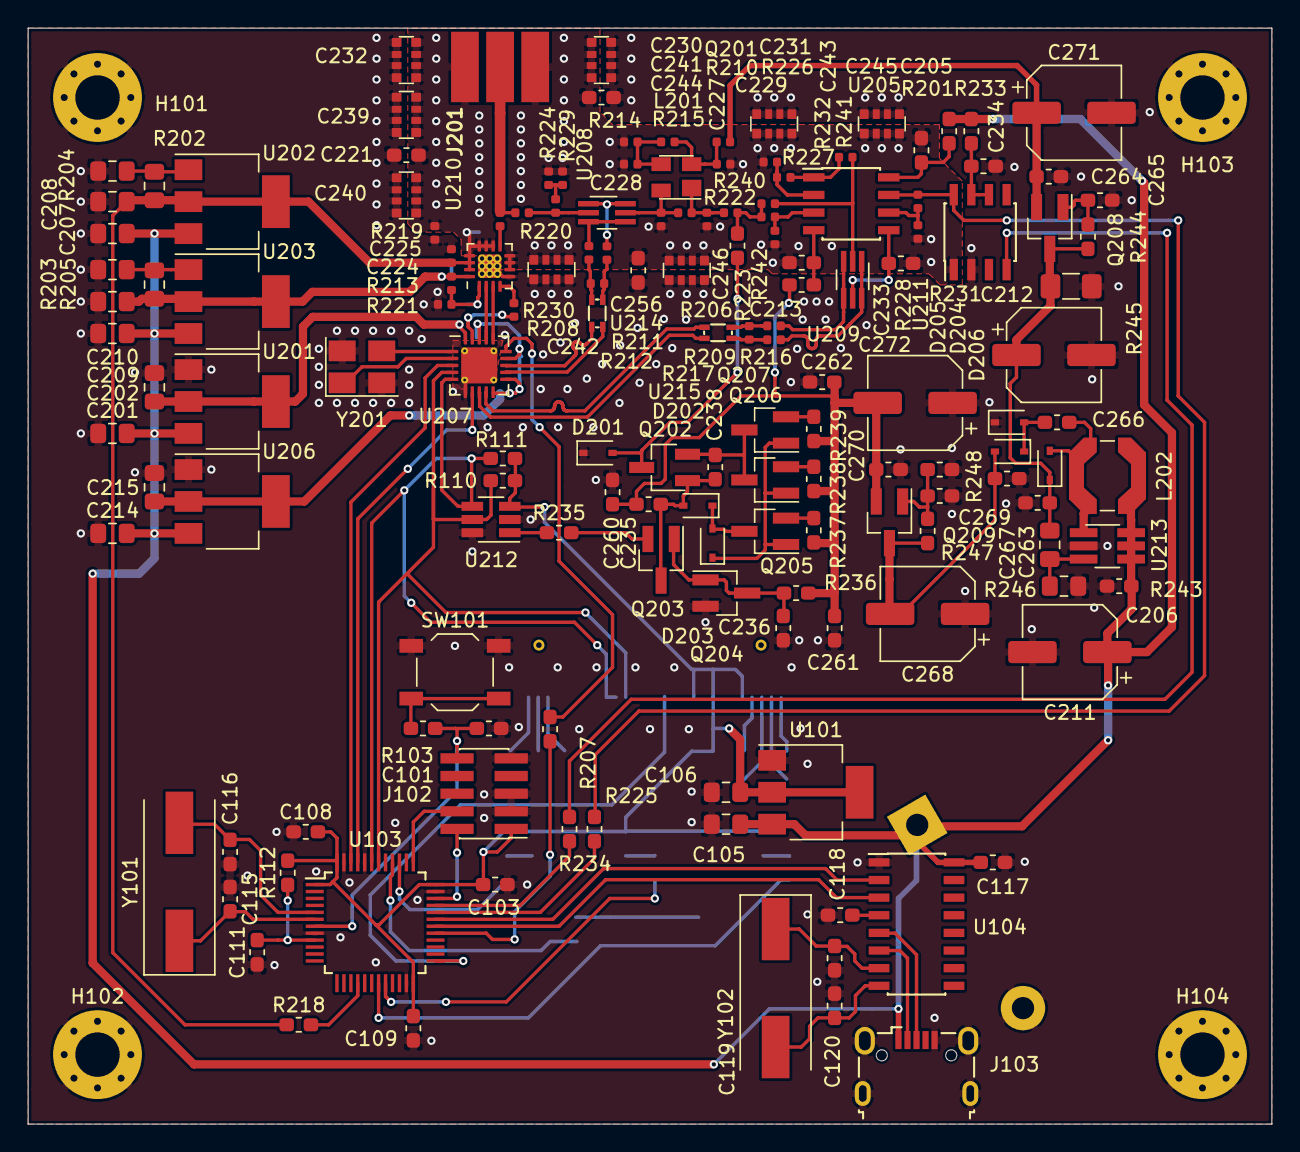
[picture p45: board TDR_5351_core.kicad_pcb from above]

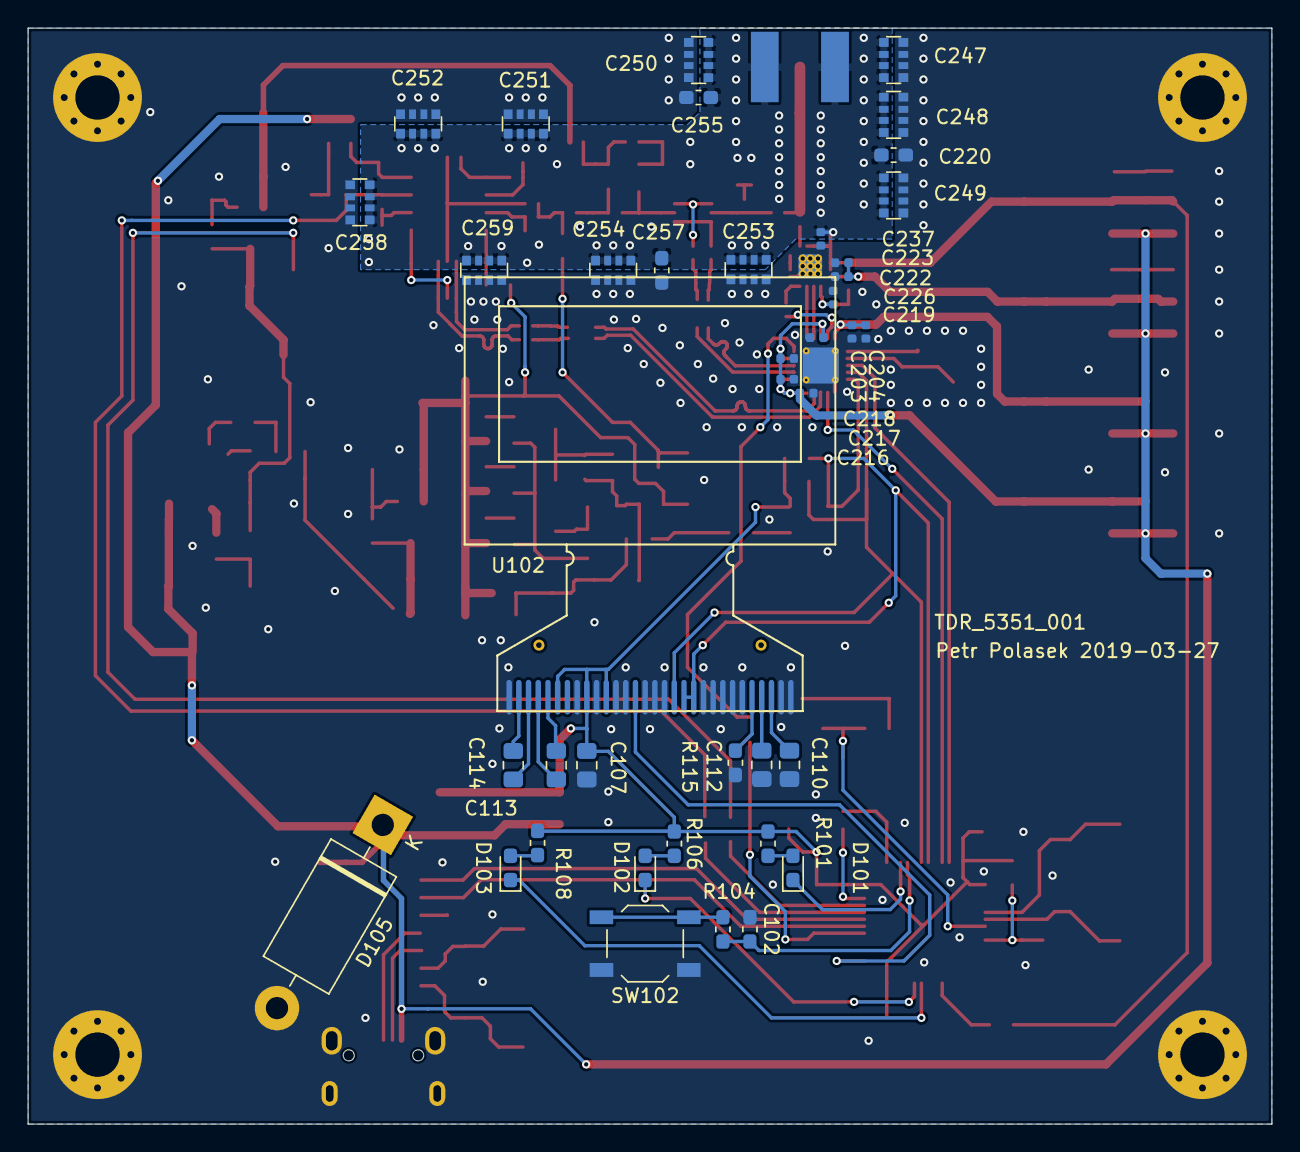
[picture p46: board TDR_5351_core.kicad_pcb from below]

Board: 2 copper layers, 89.6 x 79.0 mm, 199 parts (40 on the bottom side), 107 nets.

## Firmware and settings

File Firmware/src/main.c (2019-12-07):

/**
  ******************************************************************************
  * @file    main.c
  * @author  Ac6
  * @version V1.0
  * @date    01-December-2013
  * @brief   Default main function.
  ******************************************************************************
*/


#include "stm32f10x.h"
volatile uint32_t millis=0;
#include "board.h"
//#include "myFont.h"
#include "ssd1306.h"
#include "si5351.h"
Framebuffer display_buffer;
volatile Board_ReflectometerStateTypeDef Board_ReflectometerState;
volatile CalibrationState Board_CalibrationState;

int main(void)
{
	SSD1306_ConfigTypeDef SSD1306_ConfigStruct;
	Si5351_ConfigTypeDef Si5351_ConfigStruct;
	//uint16_t i=0;
	uint32_t last_millis=millis;

	Init_Board(&Si5351_ConfigStruct, &SSD1306_ConfigStruct, &display_buffer, &Board_ReflectometerState);

	while(1){__asm volatile ("NOP");}
	while(1)
	{
		uint8_t data=0;
		data=Si5351_ReadRegister(&Si5351_ConfigStruct, REG_DEV_STATUS);
		(data & DEV_SYS_INIT_MASK)?dispError(&SSD1306_ConfigStruct,0):dispOK(&SSD1306_ConfigStruct,0);
		(data & DEV_LOS_XTAL_MASK)?dispError(&SSD1306_ConfigStruct,1):dispOK(&SSD1306_ConfigStruct,1);
		(data & DEV_LOL_A_MASK)?dispError(&SSD1306_ConfigStruct,2):dispOK(&SSD1306_ConfigStruct,2);
		(data & DEV_LOL_B_MASK)?dispError(&SSD1306_ConfigStruct,3):dispOK(&SSD1306_ConfigStruct,3);

		SSD1306_StopProgressBar(&SSD1306_ConfigStruct);
		SSD1306_DrawPartialBuffer(&SSD1306_ConfigStruct,0,4);
		SSD1306_StartProgressBar(&SSD1306_ConfigStruct);

		Delay_ms(250);

		if(!(data & (DEV_STKY_SYS_INIT_MASK | DEV_STKY_LOS_XTAL_MASK | DEV_STKY_LOL_A_MASK | DEV_STKY_LOL_B_MASK)))
		{
			last_millis=millis;
			GPIO_WriteBit(LED_PORT, LED_NOT_RDY, Bit_SET);
			GPIO_WriteBit(LED_PORT, LED_RDY,    Bit_RESET);
		} else {
			GPIO_WriteBit(LED_PORT, LED_NOT_RDY, Bit_RESET);
			GPIO_WriteBit(LED_PORT, LED_RDY,    Bit_SET);
		}

		if(millis-last_millis>3000)
		{
			last_millis=millis;
			Si5351_ClearStickyBits(&Si5351_ConfigStruct);
		}
	}

	while(1)
	{
		uint8_t data=0;
		char str[9]={0,0,0,0,0,0,0,0,0};

		data=Si5351_ReadRegister(&Si5351_ConfigStruct, REG_DEV_STATUS);
		getbits(data, str);
		SSD1306_DrawStringToBuffer(&SSD1306_ConfigStruct, 0, 1, str);

		data=Si5351_ReadRegister(&Si5351_ConfigStruct, REG_DEV_STICKY);
		getbits(data, str);
		SSD1306_DrawStringToBuffer(&SSD1306_ConfigStruct, 0, 2, str);

		data=Si5351_ReadRegister(&Si5351_ConfigStruct, REG_INT_MASK);
		getbits(data, str);
		SSD1306_DrawStringToBuffer(&SSD1306_ConfigStruct, 0, 3, str);

		SSD1306_ConfigStruct.Scroll_State=OFF;
		SSD1306_ScrollInit(&SSD1306_ConfigStruct);
		SSD1306_DrawBuffer(&SSD1306_ConfigStruct);
		SSD1306_ConfigStruct.Scroll_State=ON;
		SSD1306_ScrollInit(&SSD1306_ConfigStruct);

		if(GPIO_ReadInputDataBit(nPLL_INT_PORT, nPLL_INT))
		{
			GPIO_WriteBit(LED_PORT, LED_NOT_RDY, Bit_RESET);
		} else {
			GPIO_WriteBit(LED_PORT, LED_NOT_RDY, Bit_SET);
		}
		Delay_ms(5);
	}
}

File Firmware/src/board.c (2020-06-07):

/*
 * board.c
 *
 *  Created on: Dec 24, 2017
 *      Author: msboss
 */

#define INT_DIVIDER 46
#define NUMBER_OF_POINTS 500000
#define DRAMATIC_PAUSE 250
#define SAMPLE_MEMORY_SIZE	4096
#define DEVICE_NAME "TDR5351_CORE"

#include <stm32f10x_rcc.h>
#include "board.h"
//#include <stm32f10x_misc.h>
#include "ssd1306.h"
#include "stdlib.h"
#include "si5351.h"

bool I2C_Initialised = FALSE;
extern volatile uint32_t millis;
extern volatile Board_ReflectometerStateTypeDef Board_ReflectometerState;
extern volatile CalibrationState Board_CalibrationState;
volatile bool Remote_Mode = FALSE;

#define COMMAND_REMOTE 0
#define COMMAND_DEVICE 1
#define COMMAND_STATE  2
#define COMMAND_ACTION 3
#define COMMAND_SEND_DATA	4
#define COMMAND_GET_AVG	5
#define COMMAND_SET_AVG 6
#define COMMAND_GET_LEVELS 7
const char commands[8][15]={"REM!","DEV?","STATE?","CONTINUE!","SEND_DATA!", "AVG?", "AVG!", "LEVELS!"};

#define NO_RESPONSE_PENDING		255
#define	RESPONSE_CARRIAGE_RETURN 254
#define RESPONSE_LINE_FEED 		253
#define RESPONSE_SEND_DATA		252
#define RESPONSE_REMOTE 				0
#define RESPONSE_DEVICE 				1
#define RESPONSE_BOARD_INIT 			2
#define RESPONSE_WAIT_EDGE 				3
#define RESPONSE_CALIBRATING_SAMPLER 	4
#define RESPONSE_NOISE_ESTIMATION	 	5
#define RESPONSE_FINDING_EDGE		 	6
#define RESPONSE_FINDING_REFERENCE_PLANE	7
#define RESPONSE_READY					8
#define RESPONSE_WAIT_OPEN				9
#define RESPONSE_WAIT_SHORT				10
#define RESPONSE_WAIT_LOAD				11
#define RESPONSE_NORMAL_CAL_RUNNING		12
#define RESPONSE_WAIT_REFERENCE_PLANE 	13
#define RESPONSE_WAIT_DUT				14
#define RESPONSE_MEASUREMENT_RUNNING	15
#define RESPONSE_READY_TO_SEND			16
#define RESPONSE_SENDING_DATA			17
#define RESPONSE_AVG					18
#define RESPONSE_AVG_NUMBER				19
#define RESPONSE_LEVELS					20
#define RESPONSE_LEVELS_LOW				21
#define RESPONSE_LEVELS_HIGH			22
uint8_t responses[23][48]={"REM.",DEVICE_NAME" "__DATE__" "__TIME__,"STATE BOARD_INIT","STATE WAIT_EDGE",
			"STATE CALIBRATING_SAMPLER","STATE NOISE_ESTIMATION","STATE FINDING_EDGE","STATE FINDING_REFERENCE_PLANE",
			"STATE READY","STATE WAIT_OPEN","STATE WAIT_SHORT","STATE WAIT_LOAD","STATE NORMAL_CAL_RUNNING",
			"STATE WAIT_REFERENCE_PLANE","STATE WAIT_DUT","STATE MEASUREMENT_RUNNING", "STATE READY_TO_SEND",
			"STATE SENDING_DATA", "AVG ", "0","LEVELS ", "0", "4095"};
volatile uint8_t global_response_pending=NO_RESPONSE_PENDING;

volatile bool remote_user_action=FALSE;

void Wait_For_User_Action(void)
{
	while((GPIO_ReadInputDataBit(BTN_PORT,BTN)==SET)&(remote_user_action==FALSE)){}
	while(GPIO_ReadInputDataBit(BTN_PORT,BTN)==RESET){}
	remote_user_action=FALSE;
}

void Find_Discontinuities(uint16_t data[SAMPLE_MEMORY_SIZE], uint16_t error_positions[8], int16_t diff_values[8], uint16_t low, uint16_t high)
{
	uint8_t error_counter=0;
	uint8_t i8;
	uint16_t i16;
	int16_t last_largest_diff=0;
	uint32_t last_largest_diff_position=0;
	for(i16=16; i16<SAMPLE_MEMORY_SIZE; i16++)
	{
		int16_t tmp=-(2000*((int32_t)data[i16]-data[i16-16]))/(high-low);

		if (abs(tmp)>abs(last_largest_diff))
		{
			last_largest_diff=tmp;
			last_largest_diff_position=i16;
		}
	}

	while(error_counter<7)
	{
		if (abs(last_largest_diff)>150)
		{
			error_positions[error_counter]=last_largest_diff_position;
			diff_values[error_counter]=last_largest_diff;
		}

		if (diff_values[error_counter]==0) break;

		error_counter++;
		last_largest_diff=0;
		last_largest_diff_position=0;
		for(i16=16; i16<SAMPLE_MEMORY_SIZE; i16++)
		{
			int16_t tmp=-(2000*((int32_t)data[i16]-data[i16-16]))/(high-low);
			if (abs(tmp)>abs(last_largest_diff))
			{
				bool already_found=FALSE;
				for (i8=0; i8<error_counter; i8++)
				{
					if ((i16<(error_positions[i8]+16)) & (i16>(error_positions[i8]-16))) already_found=TRUE;
				}
				if (already_found==TRUE) continue;

				last_largest_diff=tmp;
				last_largest_diff_position=i16;
			}
		}
	}

	error_counter=0;
	while(diff_values[error_counter]!=0) error_counter++;

	for (i8=0; i8<error_counter; i8++)
	{
		uint8_t i8_2;
		for(i8_2=1; i8_2<error_counter; i8_2++)
		{
			if (error_positions[i8_2]<error_positions[i8_2-1])
			{
				uint8_t tmp2=error_positions[i8_2];
				error_positions[i8_2]=error_positions[i8_2-1];
				error_positions[i8_2-1]=tmp2;

				tmp2=diff_values[i8_2];
				diff_values[i8_2]=diff_values[i8_2-1];
				diff_values[i8_2-1]=tmp2;
			}
		}
	}
}
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

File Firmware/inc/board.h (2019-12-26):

/*
 * board.h
 *
 *  Created on: Dec 24, 2017
 *      Author: msboss
 */

#ifndef BOARD_H_
#define BOARD_H_

#include "stm32f10x.h"
#include "ssd1306.h"
#include "si5351.h"

#ifdef __cplusplus
 extern "C" {
#endif

typedef enum {FALSE=0, TRUE=1} bool;

#define MCP4725_ADDRESS	(0xC0+(1<<2))

#define CH_MAINSAMP_P	0
#define	CH_MAINSAMP_N	1
#define CH_SLAVESAMP_P	2
#define CH_SLAVESAMP_N	3
#define CH_nCML_OE		4
#define CH_PULSE_P		5
#define CH_PULSE_N		6
#define CH_ADC_TRIGGER	7

#define TIM_ETR_PORT	GPIOA
#define TIM_ETR_PERIPH	RCC_APB2Periph_GPIOA
#define TIM_ETR			GPIO_Pin_12

#define OUT_PORT		GPIOA
#define OUT_PERIPH		RCC_APB2Periph_GPIOA
#define OUT_REF			GPIO_Pin_6
#define OUT_REF_ADC_CHANNEL		ADC_Channel_6
#define OUT_LIN			GPIO_Pin_11
#define OUT_LIN_ADC_CHANNEL		ADC_Channel_5
#define OUT_LOG			GPIO_Pin_12
#define OUT_LOG_ADC_CHANNEL		ADC_Channel_7

#define ADC_TRG_PORT	GPIOB
#define ADC_TRG_PERIPH	RCC_APB2Periph_GPIOB
#define ADC_TRG			GPIO_Pin_11
#define ADC_TRG_PORTSOURCE	GPIO_PortSourceGPIOB
#define ADC_TRG_PINSOURCE	GPIO_PinSource11

#define USART_PORT		GPIOA
#define USART_PERIPH	RCC_APB2Periph_GPIOA
#define USART_RX		GPIO_Pin_10
#define USART_TX		GPIO_Pin_9

#define LED_PORT		GPIOB
#define LED_PERIPH		RCC_APB2Periph_GPIOB
#define LED_NOT_RDY		GPIO_Pin_1
#define LED_RDY			GPIO_Pin_2
#define LED_BUSY		GPIO_Pin_3

#define BTN_PORT		GPIOB
#define BTN_PERIPH		RCC_APB2Periph_GPIOB
#define BTN				GPIO_Pin_4

#define I2C_PORT		GPIOB
#define I2C_PERIPH		RCC_APB2Periph_GPIOB
#define SDA				GPIO_Pin_7
#define SCL				GPIO_Pin_6
#define SDA_PinSource	GPIO_PinSource7
#define SCL_PinSource	GPIO_PinSource6

#define nPLL_OE_PORT	GPIOB
#define nPLL_OE_PERIPH	RCC_APB2Periph_GPIOB
#define nPLL_OE			GPIO_Pin_8

#define nPLL_INT_PORT	GPIOB
#define nPLL_INT_PERIPH	RCC_APB2Periph_GPIOB
#define nPLL_INT		GPIO_Pin_9

#define nOLED_RESET_PORT	GPIOB
#define nOLED_RESET_PERIPH	RCC_APB2Periph_GPIOB
#define nOLED_RESET			GPIO_Pin_12

//#define CLK_

typedef enum {DISABLED=0, ENABLED=1} ForceState;

typedef enum {CAL_BOARD_INIT=0, CAL_WAIT_EDGE, CAL_CALIBRATING_SAMPLER, CAL_NOISE_ESTIMATION,
			CAL_FINDING_EDGE, CAL_FINDING_REFERENCE_PLANE, CAL_READY, CAL_WAIT_OPEN, CAL_WAIT_SHORT,
			CAL_WAIT_LOAD, CAL_RUNNING, CAL_WAIT_REFERENCE_PLANE, CAL_WAIT_DUT, CAL_MEASUREMENT_RUNNING,
			CAL_READY_TO_SEND, CAL_SENDING_DATA, CAL_DATA_SENT} CalibrationState;

#ifndef ENABLESTATE
#define ENABLESTATE
	typedef enum
	{
		OFF = 0,
		ON = 1
	} EnableState;
#endif

typedef enum
{
	ReflectometerMode_Run,
		//enable everything
		//when disabled by OEB, pulser HIGH, first sampler connected, second connected, ADC still running (mask OEB)
		//"normal" measurement mode


	ReflectometerMode_Test_Risetime_Disconnected_Sampler,
		//disable main sampler (sampler disconnected), otherwise the same as "Run"
		//when disabled by OEB, pulser HIGH, first sampler disconnected, second connected, ADC still running (mask OEB)
		//should be used to measure risetime using oscilloscope or spectrum analyser
	ReflectometerMode_Test_Risetime_Connected_Sampler,
		//disable main sampler (sampler connected), otherwise the same as "Run"
		//when disabled by OEB, the same as "Run"
		//should be used to measure risetime using oscilloscope or spectrum analyser

	ReflectometerMode_Test_ReturnLoss_Disconnected_Sampler,
		//The same as "Test_Risetime_Disconnected_Sampler", but pulser set permanently to HIGH
		//when disabled by OEB, the same as "Test_Risetime_Disconnected_Sampler"
		//should be used to measure return loss using VNA or TDR
	ReflectometerMode_Test_ReturnLoss_Connected_Sampler,
		//The same as "Test_Risetime_Connected_Sampler", but pulser set permanently to HIGH
		//when disabled by OEB, the same as "Test_Risetime_Connected_Sampler"
		//should be used to measure return loss using VNA or TDR


	ReflectometerMode_Calibrate_Sampler_HIGH,
		//disable pulser (set to HIGH), otherwise the same as "Run"
		//when disabled by OEB, the same as "Run"
		//should be used to measure dependence of linear channel on DAC value
	ReflectometerMode_Calibrate_Sampler_LOW,
		//disable pulser (set to HLOW), otherwise the same as "Run"
		//when disabled by OEB, the same as "Run"
		//should be used to measure dependence of linear channel on DAC value
	ReflectometerMode_Calibrate_Log_Detector,
		//the same as "Calibrate_Sampler"
		//when disabled by OEB, the same as "Calibrate_Sampler"
		//should be used to measure log detector characteristic using DAC


	ReflectometerMode_Stop
		//everything disabled, but still running
		//don't care about OEB
		//should be used as "safe" mode
} Board_ReflectometerModeTypeDef;
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

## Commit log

2019-12-07 Creating the repository
    [C1--vlc_pc--00000.csv, C1--vlc_pc--00001.csv, C1--vlc_pc--00002.csv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]
2019-12-07 fix due to broken submodules
    [TDR_5351_core-B_Cu.gbr, TDR_5351_core-B_Mask.gbr, TDR_5351_core-B_SilkS.gbr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]
2019-12-08 Tried to fix the problem with missing interrupts during USART TX, not successful yet. Updates to the GUI in Octave.
    [board.c]
2019-12-14 Made some minor simulations, some graphs fro mthe simulations, added more text to the thesis, corrected values on schematic and added a few parts to make it consistent with the simulation
2019-12-15 performed simulations on power supplies, power filters, transfer functions of amplifier and sampler, added more content to thesis
2019-12-18 Added screenshots from the device
2019-12-21 Completed the ability to set and get averages setting, added chapter to thesis, corrected a few things to the software
    [board.c]
2019-12-21 Added panoramatic effect after measurement is completed in local mode, rewritten the serial handler to use DMA for transmitting
2019-12-22 The firmware is complete, at least for purposes of using without computer. Thesis was updated to reflect the added functionality. Software was updated to take basic calibration into account.
2019-12-23 added photos of the PCB to the thesis, added content about details of the PCB
2019-12-23 Added chapter about hardware realization, a lot of photos, desciption of PCB, chapter about measurements...
2019-12-23 The firmware and thesis are almost finished, only the chapter on calibration is missing, since the feature is not implemented yet in the software.
    [board.c]
2019-12-26 Finally fixed the issue with lost interrupts. The root cause was not found, but it was hotfixed by checking a timer value in ADC interrupt to find out if and how many interrupts were lost.
    [settings_test.ods]
2019-12-26 Fixed issue with displaying discontinuities with negative position (placed before measurement plane).
    [board.c]
2019-12-27 Implemented semicalibration (load only) and calibration (OSL) into the software. Implemented help texts to clarify the usage of the GUI. Added the possibility to save and load calibration.
    [settings_test.ods]
2019-12-29 Added calibration to software and a chapter in the thesis about calibration.
2020-01-26 Fixed SOL calibration, added noise reduction features
